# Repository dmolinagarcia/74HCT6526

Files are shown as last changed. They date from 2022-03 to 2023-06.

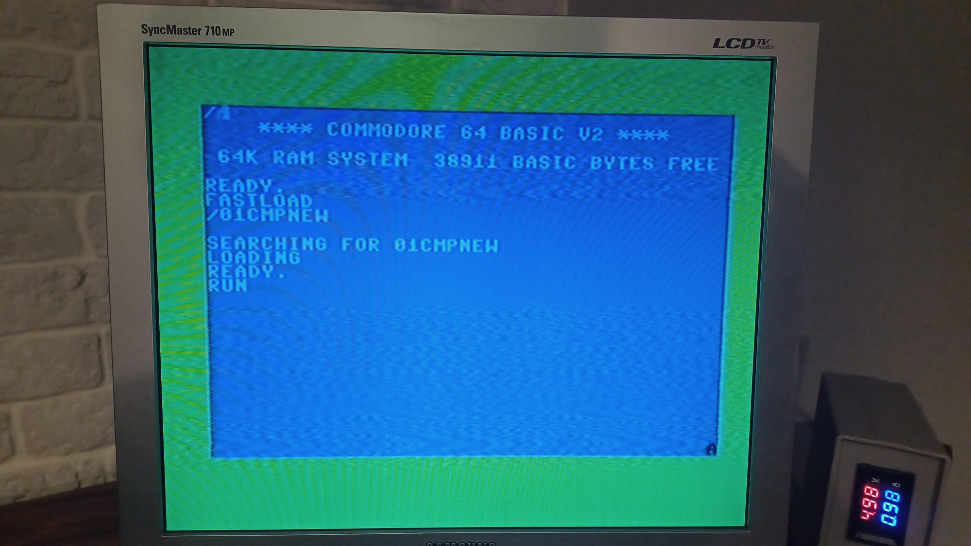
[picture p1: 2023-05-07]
img/20230506_TEST01_NEWHCT.jpeg

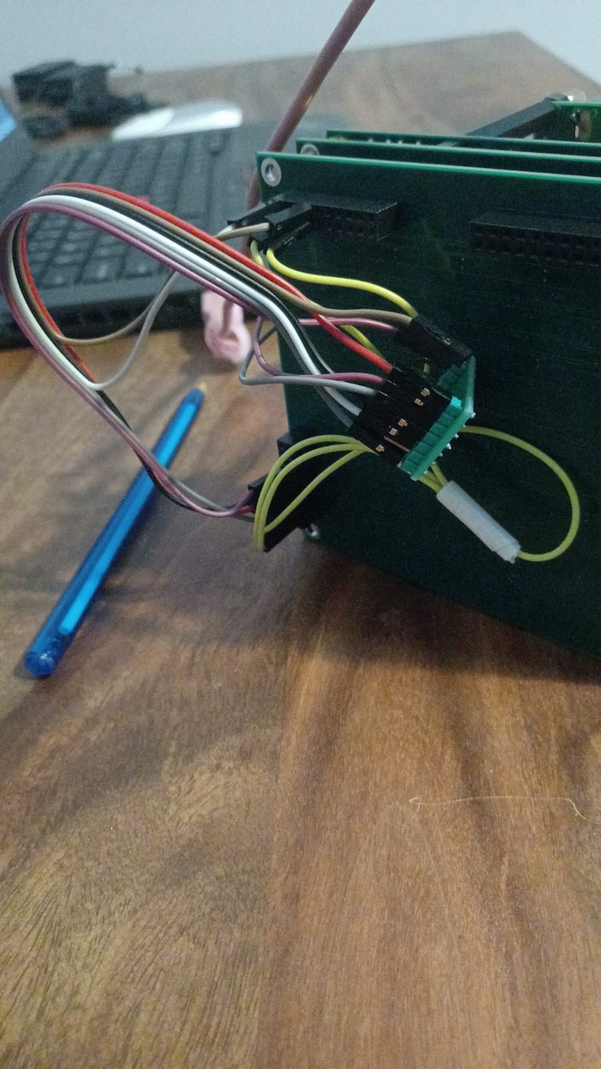
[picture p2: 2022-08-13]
img/20220810_TA_fix.jpg

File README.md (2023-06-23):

>
> DISCLAIMER
> Everything you see here is the result of the work of an amateur hobbyist. I had no knowledge in any required field for this project when I started, so I offer no guarantee that, if you replicate my work, you may end burning up you Commodore, your fingertips, or your whole house.
> So far, no Commodore equipment (or fingertips, or whole house) have been permanently damaged in any way. But I can't promise to keep it that way.
>

# 74HCT6526 
The 74HCT6526 is a very amateur attempt at building a MOS6526 replica using discrete logic. This repo is publicly shared just for educational purposes, and I can offer no guarantee on the correct behaviour of this implementation. So far, it's working great for me, but I can't promise anything.

# Current Status
As of v0.2.2, the 74HCT6526 is extremely cycle accurate when compared to a real 6526. Some VICE test still fail on edge cases, but it has been tested against multiple games with very satisfactory results. 

# History
Work on the 74HCT6526 began in the summer of 2018. I was so impressed by other attempts at replicating Commodore chips, that I wanted to give it myself a try. I chose the CIA, as it wasn't replicated back then, even though it seemed the simplest chip. I had no previous knowledge in electronics, only some lessons back in college more than 20 years ago.

> ###### Important note
> Please visit http://forum.6502.org/viewtopic.php?f=4&t=5593 for more information

# Versioning
74HCT6526 is released under the following versioning scheme:

> MAJOR.MINOR.REVISION

For a stack to work properly, is mandatory that all boards share the same MAJOR.MINOR versión. Any change than renders a board incompatible with the previous releases triggers a new MINOR version. If a version only includes fixes, but does not alter the buses, it's only a new revision. There may be some cases where boards with different MAJOR.MINOR version can actually work together, but this is not something I can guarantee or predict. A deep look at the schematics to understand the differences between releases is needed to actually confirm this.

Under the current scheme, I don't think I'll ever need a new MAJOR version, but it is nice to have it there, just in case.

# Upgrades
In the upgrades folder, there's a guide for each version/board pair, with instructions to upgrade the board up until the latest version. You'll see theres no file for the latest version (As there's no upgrade path for it).

Whenever a new release is published, upgrade path for the now second-oldest release will by published.

> WARNING! I offer no guarantee on anything on this project, but, specially on the upgrades part. 

# Manufacturing
All boards are tested against JLCPCB and PCBWAY capabilities. For PCBWAY, there is no increase in cost compared to the standard 4 layer board.

# Releases
* v0.1.0  First production run. Only includes B0 (DDR and PORTs)
* v0.1.0a First production run for B1. (TIMERA and CREGA)
* v0.1.1  Second production run for B1. Fixes TASTART issue. First B2 (TIMERB and CREGB) 
* v0.1.2  First production run for B3. (SDR and ICR)
* v0.2.0  First MINOR advance. B0+B1+B2+B3 tested and validated. 
* v0.2.1  Fixes for Reload under Underflow issue. 
* v0.2.2  First production run for B4 (TOD). It now passes test 01 and 02 in both NEW and OLD modes.

# Changelog
## [0.2.2 ] - 23-Jun-2023
* B0. Some HCT parts are changed to HC
* B1. Split TIMER into modules for improved readability
* B2. Split TIMER into modules for improved readability
* B3. Issue #12. Fixed all issues for test 02
* B3. Master Switch for Mode Change. (Old vs NEW)
* B3. Some HC parts are changed to HCT
* B4. Added TOD PCB and SCH
* All boards. Published upgrade procedures

## [0.2.1 ] - 26-Mar-2023
* All boards. Added pdfs for all schematic and pcbs for all versions for ease of access
* B1. Changes to Reload portion of TimerA pipeline to fix 01cmpold issue
* B2. Changes to Reload portion of TimerA pipeline to fix 01cmpold issue
* B3. Added switch to select OLD or NEW CIA

## [0.2.0 ] - 24-Jan-2023
* All boards. Removed TARUNMODE from the ControlBus
* All boards. Updated for JLCPCB and PCBWAY capabilities
* All boards. Minor aesthetic changes to schematics
* All boards. Updated PDFs on the release
* B1. Optimized CNT edge detector
* B2. Optimized CNT edge detector
* B3. Fixed FLAG edge detector in ICR
* B3. Fixed SDR input and output issues from v0.1.2 (not sending nor receiving)

## [0.1.2 ] - 01-Nov-2022 
* B3. First release. SDR and ICR
* B2. Updates for JLCPCB capabilities
* All boards. Schematic review. Added /RES capacitor to prevent false restarts

## [0.1.1 ] - 24-Aug-2022 
* B2. First release. 
* B1. Fixed additional cycle on forceload by removing second flipflop in the chain (rolled-back)
* B1. Added additionad dFF to Start before being fed into the timer
* B1. D and DZ moved to separate buses on schematic.
* B0. Routing optimized. D and DZ moved to separate buses on schematic. Silkscreen improved. 

## [0.1.0a] - 06-Jun-2022
* B1 with TimerA and Control Register A. Ready for production. 

## [0.1.0 ] - 19-Oct-2021
* Mounting holes pads were covered with soldermask. Soldermask removed and pads properly labeled.
* Silkscreen fixes
* Updated gerber files
* B0 with DDRs, PORTs, and bus interface

# Status updates
* June 23, 2023. v0.2.2 released. Adds TOD (B4) and fixes more NEW to OLD issues. Now passes tests 01 and 02.
* March 26, 2023. v0.2.1 released. Fixes a missing IRQ issue on reload while underflowing. It also adds a selector for OLD vs NEW cia in ICR
* January 24, 2023. v0.2.0 released. Fixes a potential problem on B1 and B2 with CNT edge detector. It also fixes some bugs on B3. A cleanup of schematic, PCBs and PDFs for all boards has been done. TARUNMODE is removed from controlbus as it is not needed. This triggers a new MINOR version
* November 01, 2022. v0.1.2 released. Includes B3 (SDR+ICR) and some minor tweaks to all boards
* August 24, 2022. v0.1.1 released. Fixes a bug in B1 (TASTART) and adds B2. Minor routing fixes to all boards
* June 06, 2022. v0.1.0a released. It adds B1 to v0.1.0
* October 19, 2021. v0.1.0 is released. It add B0 to v0.1.0
* September 12th, 2021. Repository is now public. B0 schematic is 100% done. PCB layout is 100% done. It's currently being reviewed before sending it into production

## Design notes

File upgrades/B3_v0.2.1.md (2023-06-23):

# B3 v0.2.1 Upgrade Path

@ v0.2.1
- [ ] We need one extra FF (NEWFF). 7 to GND 14 to VCC
- [ ] We also need one 74HC157 and a 2 way switch. 8 to GND 16 to VCC
- [ ] HC157.1 to center pin on switch.
- [ ] On switch. GND is NEW. VCC will be old
- [ ] HC157.15 to GND (/ENABLE)
- [ ] Replace /ICRCLR2 by /ICRCLR1 for all sources. Lift U330.6. Connect U331.1 to U330.8
- [ ] ICR1 clear OLD vs NEW. Lift U332.13. Connect to HC157.4
- [ ] ICR1 clear OLD vs NEW. HC157.2 connect to U331.13
- [ ] ICR1 clear OLD vs NEW. HC157.3 connect to U330.6
- [ ] ICR1 SET ICR7. Lift U337.12 connect to U335.13
- [ ] ICR7 OLD vs NEW. Lift U334.13 connect to U334.1
- [ ] ICR7 OLD vs NEW. Lift U336.8 connect to HC157.7
- [ ] ICR7 OLD vs NEW. HC157.5 to U334.5
- [ ] ICR7 OLD vs NEW. HC157.6 to U334.9
- [ ] IRQ OLD vs NEW. NEWFF.1 to U333.13
- [ ] IRQ OLD vs NEW. NEWFF.2 NEWFF.3 NEWFF.10 to VCC
- [ ] IRQ OLD vs NEW. NEWFF.4 to U335.8
- [ ] IRQ OLD vs NEW. NEWFF.5 to NEWFF.12
- [ ] IRQ OLD vs NEW. NEWFF.6 to HC157.11
- [ ] IRQ OLD vs NEW. NEWFF.8 to HC157.10
- [ ] IRQ OLD vs NEW. NEWFF.11 to U330.3
- [ ] IRQ OLD vs NEW. HC157.9 to /IRQ in controlBUS

@ v0.2.2

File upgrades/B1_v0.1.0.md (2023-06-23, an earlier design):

# B1 v0.1.0 Upgrade Path

@ v0.1.0
- [ ] FIX TASTART is too early. We need a new FF. Prepare a new 74HC74
- [ ] Cut trace just outside U125 PIN5. Data PIN will be early, but this is good enough
- [ ] NEWFF.1 >> VCC                RESET (VCC)
- [ ] Connect U125.5 to NEWFF.2     DATA  (old TASTART)
- [ ] NEWFF.3 >> U128.11            CLOCK (/PHI2)
- [ ] NEWFF.4 >> VCC                SET   (VCC)
- [ ] NEWFF.5 >> U127.9             Q     (new TASTART)
- [ ] NEWFF.6 >> unconected         /Q
- [ ] NEWFF.7 >> GND                GND
- [ ] NEWFF.14>> VCC                VCC

@ v0.1.1
- [ ] Added reset capacitor (100n) Optional.

@ v0.1.2
- [ ] TARUNMODE Removed from CONTROLBUS. Optional. (For now)
- [ ] CNTSYNC Improvement. Lift U123.1 Connect to 8. Optional

@ v0.2.0
- [x] FORCELOAD FIX. We use second FF from Extra FF. 
- [ ] Cut between U119.9 and U127.4
- [ ] NEWFF.13 >> U119.13 (RESET)
- [ ] NEWFF.12 >> U119.9  (DATA)
- [ ] NEWFF.11 >> NEWFF.3 (/PHI2) 
- [ ] NEWFF.10 >> VCC     (SET)
- [ ] NEWFF.9  >>  U127.4 (NEW DELAYED FORCELOAD)
- [ ] Lift U118.13 >> Connect to U115.4

@ v0.2.1
- [ ] Nothing to do

@ v0.2.2

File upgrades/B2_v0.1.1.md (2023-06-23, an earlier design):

# B2 v0.1.1 Upgrade Path

@ v0.1.1
- [ ] Added reset capacitor (100n) Optional.

@ v0.1.2
- [ ] TARUNMODE Removed from CONTROLBUS. Optional. (For now)
- [ ] CNTSYNC Improvement. Lift U221.1 Connect to U221.8. Optional

@ v0.2.0
- [ ] FORCELOAD FIX. We need an extra FF (NEWFF)
- [ ] Cut between U217.9 and U229.4
- [ ] NEWFF.13 >> U217.13 (RESET)
- [ ] NEWFF.12 >> U217.9  (DATA)
- [ ] NEWFF.11 >> U217.11 (/PHI2) 
- [ ] NEWFF.10 >> VCC     (SET)
- [ ] NEWFF.9  >>  U229.4 (NEW DELAYED FORCELOAD)
- [ ] Lift U216.13 >> Connect to U213.4

@ v0.2.1
- [ ] Nothing to do

@ v0.2.2

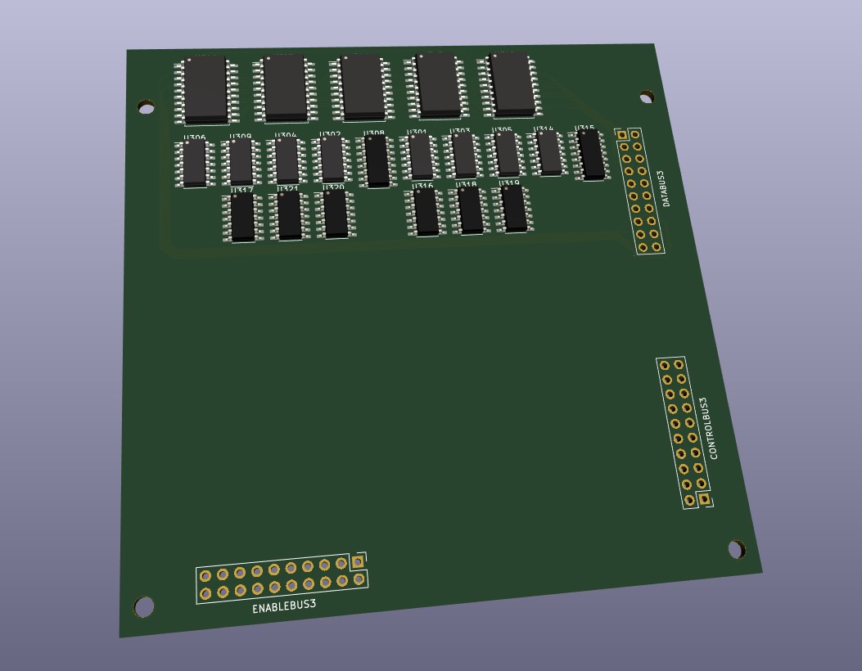
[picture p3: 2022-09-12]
img/B3_prov.jpg

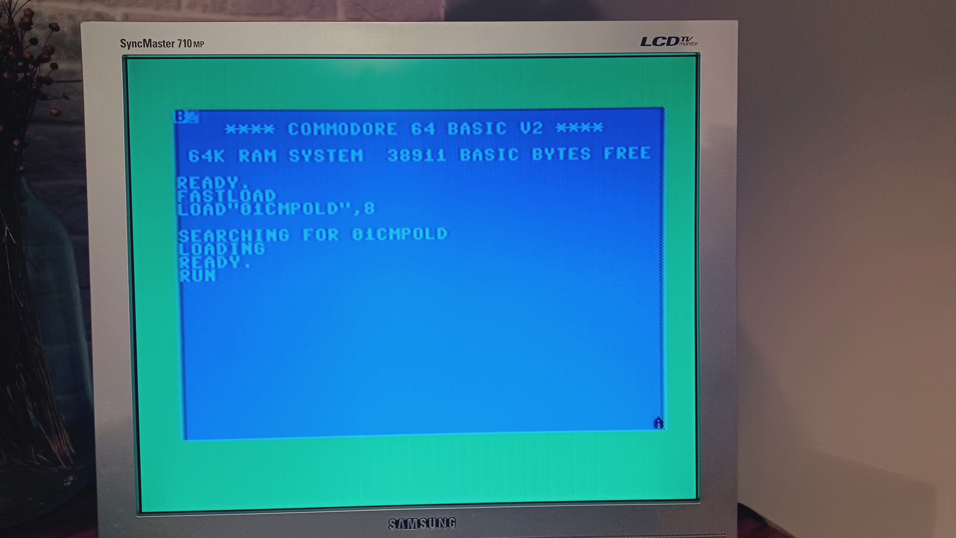
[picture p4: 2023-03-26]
img/20230321_01cmpold_success.jpg

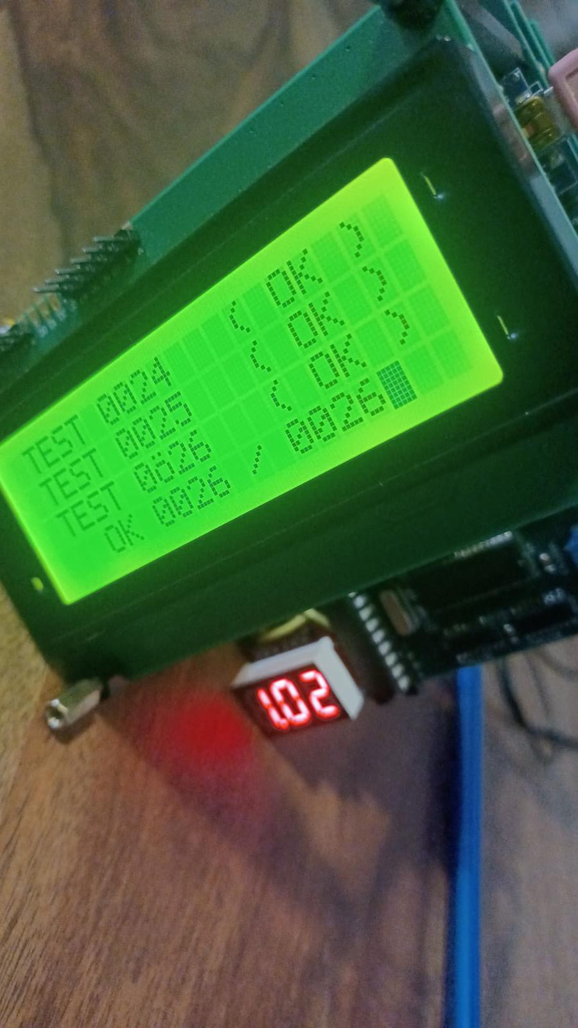
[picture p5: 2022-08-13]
img/20220810_TA_fixed.jpg

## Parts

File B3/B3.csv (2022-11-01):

Source: | Z:\gitHub\74HCT6526\B3\B3.kicad_sch
Date: | 18/10/2022 22:42:34
Tool: | Eeschema (6.0.5)
Generator: | C:\Program Files\KiCad\6.0\bin\scripting\plugins/bom_csv_grouped_by_value.py
Component Count: | 82
Individual Components:
Item | Qty | Reference(s) | Value | LibPart | Footprint | Datasheet
 |  | C301 | 100n | Device:C | Capacitor_SMD:C_0603_1608Metric | ~
 |  | C302 | 100n | Device:C | Capacitor_SMD:C_0603_1608Metric | ~
 |  | C303 | 100n | Device:C | Capacitor_SMD:C_0603_1608Metric | ~
 |  | C304 | 100n | Device:C | Capacitor_SMD:C_0603_1608Metric | ~
 |  | C305 | 100n | Device:C | Capacitor_SMD:C_0603_1608Metric | ~
 |  | C306 | 100n | Device:C | Capacitor_SMD:C_0603_1608Metric | ~
 |  | C307 | 100n | Device:C | Capacitor_SMD:C_0603_1608Metric | ~
 |  | C308 | 100n | Device:C | Capacitor_SMD:C_0603_1608Metric | ~
 |  | C309 | 100n | Device:C | Capacitor_SMD:C_0603_1608Metric | ~
 |  | C310 | 100n | Device:C | Capacitor_SMD:C_0603_1608Metric | ~
 |  | C311 | 100n | Device:C | Capacitor_SMD:C_0603_1608Metric | ~
 |  | C312 | 100n | Device:C | Capacitor_SMD:C_0603_1608Metric | ~
 |  | C313 | 100n | Device:C | Capacitor_SMD:C_0603_1608Metric | ~
 |  | C314 | 100n | Device:C | Capacitor_SMD:C_0603_1608Metric | ~
 |  | C315 | 100n | Device:C | Capacitor_SMD:C_0603_1608Metric | ~
 |  | C316 | 100n | Device:C | Capacitor_SMD:C_0603_1608Metric | ~
 |  | C317 | 100n | Device:C | Capacitor_SMD:C_0603_1608Metric | ~
 |  | C318 | 100n | Device:C | Capacitor_SMD:C_0603_1608Metric | ~
 |  | C319 | 100n | Device:C | Capacitor_SMD:C_0603_1608Metric | ~
 |  | C320 | 100n | Device:C | Capacitor_SMD:C_0603_1608Metric | ~
 |  | C321 | 100n | Device:C | Capacitor_SMD:C_0603_1608Metric | ~
 |  | C322 | 100n | Device:C | Capacitor_SMD:C_0603_1608Metric | ~
 |  | C323 | 100n | Device:C | Capacitor_SMD:C_0603_1608Metric | ~
 |  | C324 | 100n | Device:C | Capacitor_SMD:C_0603_1608Metric | ~
 |  | C325 | 100n | Device:C | Capacitor_SMD:C_0603_1608Metric | ~
 |  | C326 | 100n | Device:C | Capacitor_SMD:C_0603_1608Metric | ~
 |  | C327 | 100n | Device:C | Capacitor_SMD:C_0603_1608Metric | ~
 |  | C328 | 100n | Device:C | Capacitor_SMD:C_0603_1608Metric | ~
 |  | C329 | 100n | Device:C | Capacitor_SMD:C_0603_1608Metric | ~
 |  | C330 | 100n | Device:C | Capacitor_SMD:C_0603_1608Metric | ~
 |  | C331 | 100n | Device:C | Capacitor_SMD:C_0603_1608Metric | ~
 |  | C332 | 100n | Device:C | Capacitor_SMD:C_0603_1608Metric | ~
 |  | C333 | 100n | Device:C | Capacitor_SMD:C_0603_1608Metric | ~
 |  | C334 | 100n | Device:C | Capacitor_SMD:C_0603_1608Metric | ~
 |  | C335 | 100n | Device:C | Capacitor_SMD:C_0603_1608Metric | ~
 |  | C336 | 100n | Device:C | Capacitor_SMD:C_0603_1608Metric | ~
 |  | C337 | 100n | Device:C | Capacitor_SMD:C_0603_1608Metric | ~
 |  | C338 | 100n | Device:C | Capacitor_SMD:C_0603_1608Metric | ~
 |  | C339 | 100n | Device:C | Capacitor_SMD:C_0603_1608Metric | ~
 |  | C340 | 100n | Device:C | Capacitor_SMD:C_0603_1608Metric | ~
 |  | CONTROLBUS3 | Conn_02x10_Odd_Even | Connector_Generic:Conn_02x10_Odd_Even | Connector_PinHeader_2.54mm:PinHeader_2x10_P2.54mm_Vertical | ~
 |  | DATABUS3 | Conn_02x10_Odd_Even | Connector_Generic:Conn_02x10_Odd_Even | Connector_PinHeader_2.54mm:PinHeader_2x10_P2.54mm_Vertical | ~
 |  | ENABLEBUS3 | Conn_02x10_Odd_Even | Connector_Generic:Conn_02x10_Odd_Even | Connector_PinHeader_2.54mm:PinHeader_2x10_P2.54mm_Vertical | ~
 |  | U301 | 74HC00 | 74xx:74HC00 | Package_SO:SO-14_3.9x8.65mm_P1.27mm | http://www.ti.com/lit/gpn/sn74hc00
 |  | U302 | 74HC125 | 74xx:74LS125 | Package_SO:SO-14_3.9x8.65mm_P1.27mm | http://www.ti.com/lit/gpn/sn74LS125
 |  | U303 | 74HC74 | 74xx:74HC74 | Package_SO:SO-14_3.9x8.65mm_P1.27mm | 74xx/74hc_hct74.pdf
 |  | U304 | 74HC74 | 74xx:74HC74 | Package_SO:SO-14_3.9x8.65mm_P1.27mm | 74xx/74hc_hct74.pdf
 |  | U305 | 74HC74 | 74xx:74HC74 | Package_SO:SO-14_3.9x8.65mm_P1.27mm | 74xx/74hc_hct74.pdf
 |  | U306 | 74HC32 | 74xx:74LS32 | Package_SO:SO-14_3.9x8.65mm_P1.27mm | http://www.ti.com/lit/gpn/sn74LS32
 |  | U307 | 74HC299 | 74xx:74LS299 | Package_SO:SOIC-20W_7.5x12.8mm_P1.27mm | http://www.ti.com/lit/gpn/sn74LS299
 |  | U308 | 74HC193 | 74xx:74LS193 | Package_SO:SO-16_3.9x9.9mm_P1.27mm | http://www.ti.com/lit/ds/symlink/sn74ls193.pdf
 |  | U309 | 74HC00 | 74xx:74HC00 | Package_SO:SO-14_3.9x8.65mm_P1.27mm | http://www.ti.com/lit/gpn/sn74hc00
 |  | U310 | 74HC244 | 74xx:74HC244 | Package_SO:SOIC-20W_7.5x12.8mm_P1.27mm | https://assets.nexperia.com/documents/data-sheet/74HC_HCT244.pdf
 |  | U311 | 74HC377 | 74xx:74LS377 | Package_SO:SOIC-20W_7.5x12.8mm_P1.27mm | http://www.ti.com/lit/gpn/sn74LS377
 |  | U312 | 74HC244 | 74xx:74HC244 | Package_SO:SOIC-20W_7.5x12.8mm_P1.27mm | https://assets.nexperia.com/documents/data-sheet/74HC_HCT244.pdf
 |  | U313 | 74HC299 | 74xx:74LS299 | Package_SO:SOIC-20W_7.5x12.8mm_P1.27mm | http://www.ti.com/lit/gpn/sn74LS299
 |  | U314 | 74HC32 | 74xx:74LS32 | Package_SO:SO-14_3.9x8.65mm_P1.27mm | http://www.ti.com/lit/gpn/sn74LS32
 |  | U315 | 74HC193 | 74xx:74LS193 | Package_SO:SO-16_3.9x9.9mm_P1.27mm | http://www.ti.com/lit/ds/symlink/sn74ls193.pdf
 |  | U316 | 74HC00 | 74xx:74HC00 | Package_SO:SO-14_3.9x8.65mm_P1.27mm | http://www.ti.com/lit/gpn/sn74hc00
 |  | U317 | 74HC74 | 74xx:74HC74 | Package_SO:SO-14_3.9x8.65mm_P1.27mm | 74xx/74hc_hct74.pdf
 |  | U318 | 74HC08 | Custom 74xx:74HC08 | Package_SO:SO-14_3.9x8.65mm_P1.27mm
 |  | U319 | 74HC32 | 74xx:74LS32 | Package_SO:SO-14_3.9x8.65mm_P1.27mm | http://www.ti.com/lit/gpn/sn74LS32
 |  | U320 | 74HC00 | 74xx:74HC00 | Package_SO:SO-14_3.9x8.65mm_P1.27mm | http://www.ti.com/lit/gpn/sn74hc00
 |  | U321 | 74HC00 | 74xx:74HC00 | Package_SO:SO-14_3.9x8.65mm_P1.27mm | http://www.ti.com/lit/gpn/sn74hc00
 |  | U322 | 74HC00 | 74xx:74HC00 | Package_SO:SO-14_3.9x8.65mm_P1.27mm | http://www.ti.com/lit/gpn/sn74hc00
 |  | U323 | 74HC00 | 74xx:74HC00 | Package_SO:SO-14_3.9x8.65mm_P1.27mm | http://www.ti.com/lit/gpn/sn74hc00
 |  | U324 | 74HC00 | 74xx:74HC00 | Package_SO:SO-14_3.9x8.65mm_P1.27mm | http://www.ti.com/lit/gpn/sn74hc00
 |  | U325 | 74HC08 | Custom 74xx:74HC08 | Package_SO:SO-14_3.9x8.65mm_P1.27mm
 |  | U326 | 74HC08 | Custom 74xx:74HC08 | Package_SO:SO-14_3.9x8.65mm_P1.27mm
 |  | U327 | 74HC377 | 74xx:74LS377 | Package_SO:SOIC-20W_7.5x12.8mm_P1.27mm | http://www.ti.com/lit/gpn/sn74LS377
 |  | U328 | 74HC00 | 74xx:74HC00 | Package_SO:SO-14_3.9x8.65mm_P1.27mm | http://www.ti.com/lit/gpn/sn74hc00
 |  | U329 | 74HC00 | 74xx:74HC00 | Package_SO:SO-14_3.9x8.65mm_P1.27mm | http://www.ti.com/lit/gpn/sn74hc00
 |  | U330 | 74HC74 | 74xx:74HC74 | Package_SO:SO-14_3.9x8.65mm_P1.27mm | 74xx/74hc_hct74.pdf
 |  | U331 | 74HC74 | 74xx:74HC74 | Package_SO:SO-14_3.9x8.65mm_P1.27mm | 74xx/74hc_hct74.pdf
 |  | U332 | 74HC74 | 74xx:74HC74 | Package_SO:SO-14_3.9x8.65mm_P1.27mm | 74xx/74hc_hct74.pdf
 |  | U333 | 74HC74 | 74xx:74HC74 | Package_SO:SO-14_3.9x8.65mm_P1.27mm | 74xx/74hc_hct74.pdf
 |  | U334 | 74HC74 | 74xx:74HC74 | Package_SO:SO-14_3.9x8.65mm_P1.27mm | 74xx/74hc_hct74.pdf
 |  | U335 | 74HC04 | 74xx:74HC04 | Package_SO:SO-14_3.9x8.65mm_P1.27mm | https://assets.nexperia.com/documents/data-sheet/74HC_HCT04.pdf
 |  | U336 | 74HC244 | 74xx:74HC244 | Package_SO:SOIC-20W_7.5x12.8mm_P1.27mm | https://assets.nexperia.com/documents/data-sheet/74HC_HCT244.pdf
 |  | U337 | 74HC08 | Custom 74xx:74HC08 | Package_SO:SO-14_3.9x8.65mm_P1.27mm
 |  | U338 | 74HC32 | 74xx:74LS32 | Package_SO:SO-14_3.9x8.65mm_P1.27mm | http://www.ti.com/lit/gpn/sn74LS32
 |  | U339 | 74HC08 | Custom 74xx:74HC08 | Package_SO:SO-14_3.9x8.65mm_P1.27mm
Collated Components:
Item | Qty | Reference(s) | Value | LibPart | Footprint | Datasheet
1 | 40 | C301, C302, C303, C304, C305, C306, C307, C308, C309, C310, C311, C312, C313, C314, C315, C316, C317, C318, C319, C320, C321, C322, C323, C324, C325, C326, C327, C328, C329, C330, C331, C332, C333, C334, C335, C336, C337, C338, C339, C340 | 100n | Device:C | Capacitor_SMD:C_0603_1608Metric | ~
2 | 3 | CONTROLBUS3, DATABUS3, ENABLEBUS3 | Conn_02x10_Odd_Even | Connector_Generic:Conn_02x10_Odd_Even | Connector_PinHeader_2.54mm:PinHeader_2x10_P2.54mm_Vertical | ~
3 | 10 | U301, U309, U316, U320, U321, U322, U323, U324, U328, U329 | 74HC00 | 74xx:74HC00 | Package_SO:SO-14_3.9x8.65mm_P1.27mm | http://www.ti.com/lit/gpn/sn74hc00
4 | 1 | U302 | 74HC125 | 74xx:74LS125 | Package_SO:SO-14_3.9x8.65mm_P1.27mm | http://www.ti.com/lit/gpn/sn74LS125
5 | 9 | U303, U304, U305, U317, U330, U331, U332, U333, U334 | 74HC74 | 74xx:74HC74 | Package_SO:SO-14_3.9x8.65mm_P1.27mm | 74xx/74hc_hct74.pdf
6 | 4 | U306, U314, U319, U338 | 74HC32 | 74xx:74LS32 | Package_SO:SO-14_3.9x8.65mm_P1.27mm | http://www.ti.com/lit/gpn/sn74LS32
7 | 2 | U307, U313 | 74HC299 | 74xx:74LS299 | Package_SO:SOIC-20W_7.5x12.8mm_P1.27mm | http://www.ti.com/lit/gpn/sn74LS299
8 | 2 | U308, U315 | 74HC193 | 74xx:74LS193 | Package_SO:SO-16_3.9x9.9mm_P1.27mm | http://www.ti.com/lit/ds/symlink/sn74ls193.pdf
9 | 3 | U310, U312, U336 | 74HC244 | 74xx:74HC244 | Package_SO:SOIC-20W_7.5x12.8mm_P1.27mm | https://assets.nexperia.com/documents/data-sheet/74HC_HCT244.pdf
10 | 2 | U311, U327 | 74HC377 | 74xx:74LS377 | Package_SO:SOIC-20W_7.5x12.8mm_P1.27mm | http://www.ti.com/lit/gpn/sn74LS377
11 | 5 | U318, U325, U326, U337, U339 | 74HC08 | Custom 74xx:74HC08 | Package_SO:SO-14_3.9x8.65mm_P1.27mm
12 | 1 | U335 | 74HC04 | 74xx:74HC04 | Package_SO:SO-14_3.9x8.65mm_P1.27mm | https://assets.nexperia.com/documents/data-sheet/74HC_HCT04.pdf

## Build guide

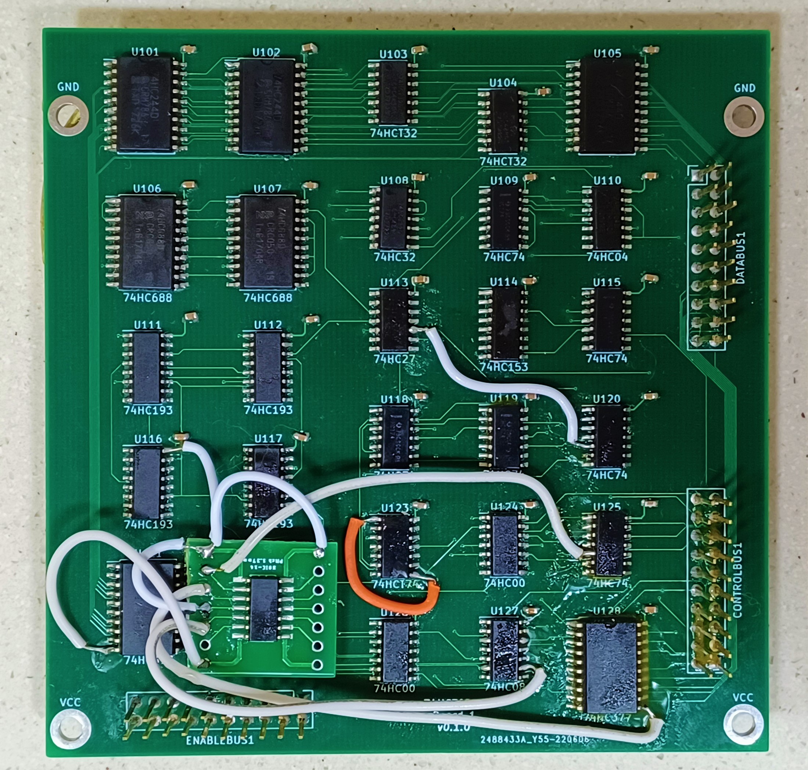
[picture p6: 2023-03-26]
img/Photos-001/20230319_step1.jpg

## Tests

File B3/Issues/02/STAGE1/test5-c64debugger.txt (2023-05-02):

abrimos el retrodebugger
load 02olcdias.prg
reset

poke 2077,5		; Start en test 5
sys 2061

breakpoint 096b		right after delay

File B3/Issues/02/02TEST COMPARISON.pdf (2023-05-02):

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
@ iA iA iA iA

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
iA iA iA iA

@

@

@

@

@ iA iA iA iA
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
@ iA iA iA iA iA

@

@

@

@

@

@

@
iA iA iA iA

@

@

@

@

@ iA iA iA iA
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
@ iA iA iA iA iA

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
iA iA iA

@

@

@

@

@

@ iA iA iA
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
@ iA iA iA iA iA

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
iA iA iA

@

@

@

@

@ iA iA iA
K

K

K

G

G

G

G

B | B B B

HCTOLD

MOSOLD

TEST6

HCTNEW

MOSNEW

TEST6

TEST5

HCTNEW

MOSNEW

TEST5

HCTOLD

MOSOLD

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
@ iB iB iB iB

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
@ iB iB iB

@

@

@

@

@

@ iB iB iB
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
@ iB iB iB iB iB

@

@

@

@

@

@

@
iB iB iB iB

@

@

@

@

@ iB iB iB iB
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
@ iB iB iB iB iB

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
@ iB iB

@

@

@

@

@

@

@ iB iB
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
@ iB iB iB iB iB

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
i@ iB iB

@

@

@

@

@ i@ iB iB
K

K

K

G

G

G

G

B | B B B

TEST8

HCTNEW

MOSNEW

TEST8

HCTOLD

MOSOLD

TEST7

HCTNEW

MOSNEW

TEST7

HCTOLD

MOSOLD

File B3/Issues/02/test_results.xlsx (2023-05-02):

 | OLD MODE |  |  |  | NEW MODE
AFTER CHANGE | 01old | 01new | 02old | 02new | 01old | 01new | 02old | 02new
1 | OK - ESPERADO | KO - ESPERADO | TA OK - TB OK - IA OK - IB KO | TA OK - TB KO - IA KO - IB KO | KO - ESPERADO | OK - ESPERADO | TA OK TB OK IA KO IB KO | TA OK TB KO IA KO IB KO

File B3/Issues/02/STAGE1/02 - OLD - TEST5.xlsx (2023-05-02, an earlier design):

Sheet: Hoja1
microSecs | MOS OLD |  |  |  |  |  |  | microSecs | HCT OLD |  |  |  |  |  |  |  |  |  | A | B | C | D | E | F | G | H
 | PHI2 | PB6 | /CS | /IRQ | D7 | D1 | D0 |  | PHI2 | PB6 | /CS | /IRQ | D7 | D1 | D0 |  |  |  | @ | @ | @ | @ | @ | @ | @ | @
 |  |  |  |  |  |  |  |  |  |  |  |  |  |  |  |  |  |  |  | @ | @ | @ | @ | @ | @ | @
 |  |  |  |  |  |  |  |  |  |  |  |  |  |  |  |  |  |  |  | A | A | A
 |  |  |  |  |  |  |  |  |  |  |  |  |  |  |  | OPCODE |  | SCREEN OUTPUT
48.250 | 0 | 1 | 1 | 1 | 1 | 0 | 1 | 48.375 | 0 | 1 | 1 | 1 | 1 | 0 | 1
48.375 | 0 | 1 | 1 | 1 | 0 | 0 | 0 | 48.500 | 0 | 1 | 1 | 1 | 0 | 0 | 0
48.500 | 0 | 1 | 1 | 1 | 0 | 0 | 0 | 48.625 | 0 | 1 | 1 | 1 | 0 | 0 | 0
48.625 | 1 | 1 | 0 | 1 | 0 | 0 | 0 | 48.750 | 1 | 1 | 0 | 1 | 0 | 1 | 1
48.750 | 1 | 1 | 0 | 1 | 0 | 1 | 1 | 48.875 | 1 | 1 | 0 | 1 | 0 | 1 | 1
48.875 | 1 | 1 | 0 | 1 | 0 | 1 | 1 | 49.000 | 1 | 1 | 0 | 1 | 0 | 1 | 1
49.000 | 1 | 1 | 0 | 1 | 0 | 1 | 1 | 49.125 | 1 | 1 | 0 | 1 | 0 | 1 | 1 |  |  |  |  |  |  |  |  |  |  |  | STA CRG | SET PB ON
49.125 | 0 | 1 | 1 | 1 | 0 | 1 | 1 | 49.250 | 0 | 0 | 1 | 1 | 0 | 1 | 1 |  |  |  |  |  |  |  |  |  |  |  | START OF TEST
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

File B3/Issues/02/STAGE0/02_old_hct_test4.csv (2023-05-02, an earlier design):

Time[s] | PHI2 | PB6 | PB7 | /CS | /IRQ | D0 | D1 | D7
0.019945375000000 | 1 | 1 | 1 | 1 | 1 | 0 | 0 | 0
0.019945500000000 | 1 | 1 | 1 | 0 | 1 | 0 | 0 | 0
0.019945625000000 | 1 | 1 | 1 | 0 | 1 | 0 | 0 | 0
0.019945750000000 | 1 | 1 | 1 | 0 | 1 | 0 | 0 | 0
0.019945875000000 | 0 | 1 | 1 | 1 | 1 | 0 | 0 | 0
0.019946000000000 | 0 | 1 | 1 | 1 | 1 | 0 | 0 | 0
0.019946125000000 | 0 | 1 | 1 | 1 | 1 | 0 | 0 | 0
0.019946250000000 | 0 | 1 | 1 | 1 | 1 | 0 | 0 | 0
0.019946375000000 | 1 | 1 | 1 | 1 | 1 | 0 | 0 | 0
0.019946500000000 | 1 | 1 | 1 | 1 | 1 | 0 | 0 | 0
0.019946625000000 | 1 | 1 | 1 | 1 | 1 | 0 | 0 | 1
0.019946750000000 | 1 | 1 | 1 | 1 | 1 | 1 | 0 | 1
0.019946875000000 | 0 | 1 | 1 | 1 | 1 | 1 | 0 | 1
0.019947000000000 | 0 | 1 | 1 | 1 | 1 | 1 | 0 | 1
0.019947125000000 | 0 | 1 | 1 | 1 | 1 | 1 | 0 | 1
0.019947250000000 | 0 | 1 | 1 | 1 | 1 | 0 | 0 | 0
0.019947375000000 | 1 | 1 | 1 | 1 | 1 | 0 | 0 | 0
0.019947500000000 | 1 | 1 | 1 | 1 | 1 | 0 | 0 | 0
0.019947625000000 | 1 | 1 | 1 | 1 | 1 | 0 | 0 | 0
0.019947750000000 | 1 | 1 | 1 | 1 | 1 | 0 | 0 | 0
0.019947875000000 | 0 | 1 | 1 | 1 | 1 | 0 | 0 | 0
0.019948000000000 | 0 | 1 | 1 | 1 | 1 | 0 | 0 | 0
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

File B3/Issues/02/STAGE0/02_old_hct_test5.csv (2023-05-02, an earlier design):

Time[s] | PHI2 | PB6 | PB7 | /CS | /IRQ | D0 | D1 | D7
0.059857750000000 | 1 | 1 | 1 | 0 | 1 | 0 | 0 | 0
0.059857875000000 | 1 | 1 | 1 | 0 | 1 | 0 | 0 | 0
0.059858000000000 | 1 | 1 | 1 | 0 | 1 | 0 | 0 | 0
0.059858125000000 | 0 | 1 | 1 | 0 | 1 | 0 | 0 | 0
0.059858250000000 | 0 | 1 | 1 | 1 | 1 | 0 | 0 | 0
0.059858375000000 | 0 | 1 | 1 | 1 | 1 | 0 | 0 | 0
0.059858500000000 | 0 | 1 | 1 | 1 | 1 | 0 | 0 | 1
0.059858625000000 | 0 | 1 | 1 | 1 | 1 | 0 | 0 | 1
0.059858750000000 | 1 | 1 | 1 | 1 | 1 | 0 | 0 | 1
0.059858875000000 | 1 | 1 | 1 | 1 | 1 | 0 | 0 | 1
0.059859000000000 | 1 | 1 | 1 | 1 | 1 | 1 | 0 | 1
0.059859125000000 | 1 | 1 | 1 | 1 | 1 | 1 | 0 | 1
0.059859250000000 | 0 | 1 | 1 | 1 | 1 | 1 | 0 | 1
0.059859375000000 | 0 | 1 | 1 | 1 | 1 | 1 | 0 | 1
0.059859500000000 | 0 | 1 | 1 | 1 | 1 | 0 | 0 | 0
0.059859625000000 | 0 | 1 | 1 | 1 | 1 | 0 | 0 | 0
0.059859750000000 | 1 | 1 | 1 | 1 | 1 | 0 | 0 | 0
0.059859875000000 | 1 | 1 | 1 | 1 | 1 | 0 | 0 | 0
0.059860000000000 | 1 | 1 | 1 | 1 | 1 | 0 | 0 | 0
0.059860125000000 | 1 | 1 | 1 | 1 | 1 | 0 | 0 | 0
0.059860250000000 | 0 | 1 | 1 | 1 | 1 | 0 | 0 | 0
0.059860375000000 | 0 | 1 | 1 | 1 | 1 | 0 | 0 | 0
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

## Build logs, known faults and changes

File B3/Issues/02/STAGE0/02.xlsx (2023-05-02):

REAL |  |  |  |  |  |  | HCT |  |  |  |  |  |  |  |  | TEST OUTPUT
Time[s] | PHI2 | PB6 | /CS | D7 | D1 | D0 | Time[s] | PHI2 | PB6 | /CS | D7 | D1 | D0 | OPCODE | Comentarios | 0 | 1 | 2 | 3 | 4 | 5 | 6 | 7 | 8 | 9 | a | b | c | d | e | f | ICR
 |  |  |  |  |  |  |  |  |  |  |  |  |  |  |  |  |  |  |  |  |  |  |  |  | B | C | D | E | F | G | H
 |  |  |  |  |  |  |  |  |  |  |  |  |  |  |  |  |  |  |  |  |  |  |  |  | A | A | A | A | A | A | @
 |  |  |  |  |  |  |  |  |  |  |  |  |  |  |  |  |  |  |  |  |  |  |  |  | @ | @ | @ | @ | @ | @ | @
0.019945375 | 1 | 1 | 1 | 1 | 0 | 0 | 0.019945375 | 1 | 1 | 1 | 0 | 0 | 0
0.019945500 | 1 | 1 | 0 | 1 | 0 | 0 | 0.019945500 | 1 | 1 | 0 | 0 | 0 | 0
0.019945625 | 1 | 1 | 0 | 0 | 0 | 0 | 0.019945625 | 1 | 1 | 0 | 0 | 0 | 0
0.019945750 | 1 | 1 | 0 | 0 | 0 | 0 | 0.019945750 | 1 | 1 | 0 | 0 | 0 | 0
0.019945875 | 0 | 1 | 0 | 0 | 0 | 0 | 0.019945875 | 0 | 1 | 1 | 0 | 0 | 0
0.019946000 | 0 | 1 | 1 | 0 | 0 | 0 | 0.019946000 | 0 | 1 | 1 | 0 | 0 | 0
0.019946125 | 0 | 1 | 1 | 0 | 0 | 0 | 0.019946125 | 0 | 1 | 1 | 0 | 0 | 0
0.019946250 | 0 | 1 | 1 | 0 | 0 | 0 | 0.019946250 | 0 | 1 | 1 | 0 | 0 | 0
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

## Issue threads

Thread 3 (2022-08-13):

ICR

dmolinagarcia, 2022-08-13:
// IRQ bit 7 of ICR is one cycle later set also one cycle later cleared than a timer irq is set.
// Reading ICR seems to reset the ICR the next cycle.
// Writing ICR seems to also clear the ICR, 2 cycles later, in my 6526R4. (without any read)

Seen in https://www.forum64.de/index.php?thread/109935-mos6526-cia-detailed-test-vectors-and-models/&pageNo=1

dmolinagarcia, 2023-06-23:
So far this is unproven. ICR seems ok now. Closing this.
We'll revisit if necesary.

Closed 2023-06-23.

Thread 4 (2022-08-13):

TIMER B BUG

dmolinagarcia, 2022-08-13:
Reading when timer b is going to fire an interrupt causes it not to fire.

dmolinagarcia, 2023-02-05:
```
Guess what?

I do have a Timer B bug.

And a timer A bug.

And everything else  :lol:

Everything else seems to be doing just fine, so I'm focusing on fixing this, before moving on to TOD.

The problem is something like this.

Whenever the ICR is read, on the next cycle, all interrupt bits are cleared to, by asserting the /reset line on their DFFs (74HC74). (/ICRCLR signal accomplish this)
The interrupt source feeds into the /set line of the DFFs.

I did some tests with just a couple of ICs, and whenever /set and /reset where asserted at the same time, /set prevailed, leaving the DFF set to 1. According to the datasheet, this is supposed to output a high value on both Q and /Q, and on the next clock pulse, the value on the D input is latched. Anyway, Clk and D are tied high.

The interrupt source and the /ICRCLR are out of phase by half a cycle, and are active only for 1 full cycle.  So... the interrupt source can be half a cycle earlier, or half a cycle after the /ICRCLR signal.

PHI2      --__--__--__--__--__--__
IRQsource -----------__-----------
/IRCLR    ------------__----------

PHI2      --__--__--__--__--__--__
IRQsource -----------__-----------
/IRCLR    ----------__------------
```

dmolinagarcia, 2023-02-05:
I need to confirm the behaviour of the FF when this happens on both cases. Does it really trigger the IRQ? How can I prevent it?

dmolinagarcia, 2023-06-23:
After solving #12 this seems to be fixed too. But further confirmation is needed.

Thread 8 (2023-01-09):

Check if pdf are updated for schematic

dmolinagarcia, 2023-01-09:

dmolinagarcia, 2023-01-24:
Updating all pdfs. Will be fixed in v0.2.0

Closed 2023-01-24.

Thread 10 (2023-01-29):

TIMERA/TIMERB underflows issue.

dmolinagarcia, 2023-01-29:
From CIATEST 01.cmpold. Wheneven TIMERB is loaded (or force loaded) exactly when it overflows, real CIA seems to skip an interrupt, where 74HCT6526 doesn't. This causes NMI 51C6 to fail on the test.

This is the only value that fails.

dmolinagarcia, 2023-01-30:
Looking at test results... it seems the opposite, I skip the IRQ, real CIA doesn't but... totally unsure at this point.

dmolinagarcia, 2023-02-05:
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

6526 on the left, 74HCT6526 on right. When TIMERB underflows right after TB Forceload, the underflow is missed, and so is the pulse, and the interrupt.

dmolinagarcia, 2023-02-05:
And...

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

Logisim does not share this behaviour. IRQ fires one cycle later, but still fires.

dmolinagarcia, 2023-02-06:
Needed test!

Run the test but with different values. Verify that I'm indeed triggering the timer pulse and IRQ on the exact cycle. As IRQ is not execute until current instruction ends, I may be firing with a cycle offset and still don't see it.

As the whole test runs fine, I have the feeling I'm triggering on the exact cycle, but I want to verify it.

Then focus on how to get the underflow while reloading!

dmolinagarcia, 2023-02-06:
Bite me!

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

According to logisim, TBLOAD is high during 1 cycle, but start is high for two cycles. Enough that on the next cycle, to the forceload, the interrupt is triggered. Still not 100% accurate but.. 95% closer than my current version.

I need to measure 74HCT6526 with the same values as this last test.  According to logisim, there's plenty of time for the pulse to happen... it isn't even an asynchronous event, so, why am I missing it?

dmolinagarcia, 2023-02-08:
What signals do I need for this test?

- PHI2
- /CS (CIA2)
- /NMI
- A[3..0]
- TA[4..0]
- TBis0 (Underflow Signal from timer block)
- TBLOAD (output from CREG)
- TBPRECOUNT (Output from first FF in pipeline)
- ICR1
- TBStart (output from CREG)

Son 17 señales. Puedo prescindir de /CS (Lo calculo desde A) o de parte de A, lo calculo desde el flujo del programa.

dmolinagarcia, 2023-02-13:
I'm thinking of a reduced test that I can do with a 8ch channel.
* PHI2
* /CS (CIA2)
* PB6 (TAPULSE)
* PB7 (TBPULSE)
* TBLOAD
* TBPRECOUNT
* TBSTART (Output from CREG, not the register value)

But... I may have found a solution. Neither TBLOAD nor TBHI when not running should clear the pipeline, but they do. TBHI does not matter, as timer is not running, so pipeline is already empty, but.. TBLOAD... why!!!!

If I reset the clock pipeline with TBPULSET, and have the other reload sources reset only the LOAD ff. It may just work. Just maybe...

dmolinagarcia, 2023-02-24:
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

Indeed, this seems to be case, at least on LOGISIM6526. However, as forceload does not clear the pipeline, count differs by one. I need to add a DFF to delay forceload by 1 cycle. Seems to work on LOGISIM, time to do some real testing.

dmolinagarcia, 2023-02-26:
Work in progress. I am adapting B1. From it's original v0.1.0 form it's now a propore 0.1.1 and still works. Will keep upgrading it until 0.2.1

dmolinagarcia, 2023-03-18:
Finished build ov v0.2.1 B1. Unitary tests still works, but 01cmpold is worse than before. The missed underflow is still missing, and there are a few more failures. Will revert to 0.2.0

dmolinagarcia, 2023-03-21:
B1 and B2 upgraded to v0.2.1. The 51C6 failure is fixed but new failures are introduced. When TA=10 and both FL=1 It seems TB underflows earlier than expected. Should this be fixable, a fix will be introduced in 0.2.1 again.

Further testing required.

dmolinagarcia, 2023-03-21:
A wrongfully cut trace (And one that was supposed to be cut, intact) were the cause of this. Once this has been fixed, 01cmpold success.

This fix will be incorporated in v0.2.1

Closed 2023-03-21.

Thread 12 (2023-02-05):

02CIATIMERS

dmolinagarcia, 2023-02-05:
Timer pulse on original CIA is aligned with PHI2 falling edge. On 74HCT6526 is aligned with posedge.

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

Fixing this could alter all IRQ timings! Be careful.

dmolinagarcia, 2023-02-07:
I need to run several test, with TA underflows, TB underflows, TA/TB underflows.

dmolinagarcia, 2023-02-11:
HCT fires the timer pulse half a cycle late, but has the same value at PHI2 falling edge, so it should be read-identical via the PB pins. Still IRQ fires at the same time, so it may not be worth fixing this.

I need to move counting earlier (I fire the pulse as soon as the timer overflows, so theres no room to move the pulse earlier, without altering the whole pipeline).

I've been trying for a couple of days, and the pipeline is so delicate, any changes breaks it.

Moreover, if I count at PHI2 falling edge, I may not read a stable value so a latch would be needed, adding to more ICs (8bit latches) to the board.

All other timings seem perfect, at least from a CPU POV. This will remaing as is for now.

dmolinagarcia, 2023-02-12:
Note to self. If I ever go this route, I need to replace the 244 with 373. They will latch the timer output on PHI2 high, so, when PHI falls, they retain the previous value from the timer, while they do their thing.

This me be extended to all Boards. And this may be well my biggest failure :/

dmolinagarcia, 2023-03-29:
Issue renamed to reflect reality. This issue is behind the failure of test 02CIATIMERS. At least that's my current feeling. Emulator tests of 02TIMERS shows that, the very cycle the timer is reloaded, ICR bit is set. (This is NEWCIA behaviour) on OLDCIA, TIMERA does this, but TIMERB ICR is enabled one cycle later.

So, my switch between old mode and new mode is wrong. I need to move both Timers interrupts one cycle earlier (Danger! I need to re-do the pipeline 😭) And the OLD vs NEW change is to delay TIMERB by one cycle, not the interrupt being fired.

I need the full 02 test capture with the logic analyzer, with some changes.
PB7 and PB6 should output timer pulses. This should be captured
PHI2, should be captured
/CS for the CIA, captured
/IRQ as a bonus
On the 74HCT6526, I can add ICR0 and ICR1 too.

I can infer the registers from the code so the are not needed. Capture single subtest at a time. We're looking at 20*200 cycles max per test, so it should be easy to compare.

What am I looking for? Exactness of the pulse (ok ok, I know It is delayed by half a cycle)

dmolinagarcia, 2023-04-10:
OLD vs OLD (bottom result)

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

NEW vs NEW (again, bottom result)

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

dmolinagarcia, 2023-04-10:
TIMER A interrupt shows no difference between new or old. It's timerB the one that has a difference. TIMERB interreupt seems to fire a cycle earlier on NEW cias.

My CIA behaves like an old one. Keep in mind, this is always relative to the ICR register. I am setting the ICR bit as soon as the overflow happens. there's  no room to fire earlier.

dmolinagarcia, 2023-04-11:
Bite me! I'm getting it al wrong!

on first test, when reading ICR, I'm reading a 0 when there should be a 1, but not because I'm setting it half a cycle late... The 1 I should be reading, has fired long before, right at the end of cycle B.

I am clearing the ICR when I shouldn't. That's what I need to tackle. Issue now feels to exists only at ICR level.

dmolinagarcia, 2023-05-01:
After analyzing the test line by line, my failure comes from clearing interrupts too late. So I miss already set interrupt, by creating the clear before it even triggers.

Moving the clear for TA one cycle earlier, I am getting TA with no IRQ to end with OK!

This is stage one. To change from NEW to OLD, Clear of TB needs to move from where it is now (OLD) to one cycle earlier (NEW)

Still some differences in the IRQ enabled tests. Full capture of both old and new (mos and hct9 is done. time to analyze it!

dmolinagarcia, 2023-05-01:
STAGE 1

HCT-NEW
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

HCT-OLD
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

MOS-NEW
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

MOS-OLD
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

dmolinagarcia, 2023-05-08:
Some changes to ICR have been applied.
STAGE0. Cleanup of the dangling flipflop. Glued to the board and with bodge wires replaced. Everything still works the same, but looks much nicer.
STAGE1. ICR0 reset moved one cycle earlier. Fix fixes test 5
STAGE2. Same for ICR0, however, OLD still resets after two, NEW after one
BONUS. This seems to be behind timerB bug.
STAGE3. ICR7 moved one cycle earlier for NEW mode. Works fine!

This is enough to pass 02NEW.

02OLD still shows some issues, which I expect to fix in the next two stages
STAGE4. ICR CLEAR. Reset both ICR7 DFF at the same time. Right now, second one is delayed
STAGE5. IRQ. I have the feeling IRQ does not clear at the same time as ICR7, so I may need a new 74HC74 for this.

None of the above is applied to the schematic.. When S4 and S5 are done and validated, everything will be updated.

dmolinagarcia, 2023-06-19:
Next steps.

Consolidate :
- Stage 1. Fixes TA clear. Same for both modes
- Stage 2. Switch for TB clear. /ICRCLR1 for NEW /ICRCLR2 for OLD
- Stage 3. ICR7 switch. One cycle earlier for NEW

This is confirmed as good.

Then...

Stage 4 alters the clear of ICR on OLD mode, clearing it one cycle earlier. This alters the IRQ in OLD too. NEW shouldn't be affected.
Stage 5 adds 2 new FF for IRQ. The set is same as ICR7, but clear is different.

Adding 4 and 5 I'm getting weird results that I do not understand, so let's backtrack a bit.

- change the new FF so the clear is same as IC7. This should be the same as undoing stage 5.
- undo stage 4. Let's see if I get back to known conditions.

Once here, take capture of the test. Both new and old, HCT and MOS.

dmolinagarcia, 2023-06-21:
Rollback to STAGE3. 02NEW success. But IRQ is produced in a separate set of FF than ICR7.

02OLD fails in two scenearios.
A read right before the interrupt for TB clears ICR1 but not ICR7, so a 0x80 is read. I tried moving ICR7 clear forward, but it remains set always and needs a second read to clear ICR7. I think triggering the ICR7 set with TBPULSE instead of ICR1 can do the trick. Try this later today.

Also, the next iteration, no interrupt should fire. This can probably by fixed ltering the clear for IRQ.

Now that I have separated ICR7 and IRQ, this two issues are independent.

But, as everything checks out in NEW mode, it may be a good idea to make a commit (v0.2.2 I think) with NEW mode working. I really need to consolidate the schematic, as B3 is becoming more and more hard to follow.

dmolinagarcia, 2023-06-21:
Hold your horses!

I've managed to succesfully apply a STAGE4 that fixes the first remaining issue:

A read right before the interrupt for TB clears ICR1 but not ICR7, so a 0x80 is read. I tried moving ICR7 clear forward, but it remains set always and needs a second read to clear ICR7. I think triggering the ICR7 set with TBPULSE instead of ICR1 can do the trick. Try this later today.

First of all. All interrupt sources must be cleaned by

<span style="text-decoration:overline">SIGNAL_ACTIVE_LOW</span>

dmolinagarcia, 2023-06-22:
And stage 5.

Clearing both IRQ sources on /ICRCLR1 makes both old and new 02 to succed :)

dmolinagarcia, 2023-06-23:
All of this will be implemented in release v.0.2.2

Closed 2023-06-23.

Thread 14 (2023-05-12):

Segregate CNT edge detector

dmolinagarcia, 2023-05-12:
CNT edge detector is made up of 3 DFF. First one needs to be HCT.
When TARUNMODE was removed from the CONTROLBUS, a pin was left there unused.
As theres enough realstate on B0, the edge detector can be moved there, and the syncronyzed edge pulse added to the controlbus.
This will use 3 DFF on B0 (there´s 1 free already) so I'll be adding one more IC to B0.
In return, I can remove 9 DFF from B1, B2, B3 (3 each)
On B1, theres a unused FF, so I save 2 ICs
Same for B2. 2 less ICs
Same again on B3, 2 less ICs.
So I save 5 ICs total with this change.
Beware of B3, Edge detector is different, but should work OK with the one on B1 or B2.

This will trigger a new minor release. V0.1.x boards have TARUNMODE on the unused CONTROLBUS pin. So they will be incompatibilites, unless some traces are hacked.

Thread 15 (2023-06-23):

Timer Pulses are offseted half a cycle

dmolinagarcia, 2023-06-23:
Timer pulse on original CIA is aligned with PHI2 falling edge. On 74HCT6526 is aligned with posedge.

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

Fixing this could alter all IRQ timings! Be careful.

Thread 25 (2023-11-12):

TOD Count is (wrongly) Enabled by default

dmolinagarcia, 2023-11-12:
As both TENTHs and HOURS are written to on reset... SET predominates on the flipflop.

We can remove RESET from TENTHs write. Let's see what value do we have on restart!
Or reverse bits, and set COUNT to /Q on the flipflop.

dmolinagarcia, 2023-11-14:
Some mistery here... After retinning the stack connectors, this is now working. I will keep it open until I can fully confirm it is working fine.

dmolinagarcia, 2023-11-19:
Still working, every time. Assuming it's OK. Will reopen if necessary.

Closed 2023-11-19.

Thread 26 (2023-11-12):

TOD AM/PM flag is not wired properly.

dmolinagarcia, 2023-11-12:
Issue on v0.2.2. AM/PM flip DFF will never be set. Look into it.

dmolinagarcia, 2023-11-19:
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

changed into

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

H7_FLIP FF is properly rewired. H7_FLIP is delayed by one cycle so after writing a 12 or 92, it doesn't get lost to SET or RESET on H7.

Also, it is gated with /LOADH so succesive writes still work.

Fixed!

Closed 2023-11-19.

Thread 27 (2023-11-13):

TOD is not setting ICR2

dmolinagarcia, 2023-11-13:

dmolinagarcia, 2023-11-13:
On first inspection. TODIRQ is not set on B4. Will need to check the status of all 4 comparators. Maybe start with a reflow.

dmolinagarcia, 2023-11-15:
ALARM register for seconds was not properly soldered. I have reflowed it and now I get TODIRQ. However, ICR2 is not getting set yet. Maybe the stack connector, maybe an issue on the ICR.

Also, right now ICR2 fires based on TODIRQ level which is not right. Under normal conditions, TODIRQ will be active for at least a tenth, so multiple IRQ fires are possible. ICR2 should be edge triggered.

dmolinagarcia, 2023-11-15:
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

TODIRQ is ok on B3, measured on 335.1 (04 input)
However /TODIRQ at 332.4 does not reach 0v. It bottoms at 0.5v.
ICR2, measured at the 244 input (336.4) never goes high.

U335 or U332 maybe faulty. Reflow, and replace.

dmolinagarcia, 2023-11-17:
Short to ground under U337 that affected ICR1 and ICR2.

Fixed after removal, cleanup and resolder of U337.

Closed 2023-11-17.

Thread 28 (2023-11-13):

SDR sends fails

dmolinagarcia, 2023-11-13:

dmolinagarcia, 2024-01-27:
Test SDR send on both units. Identify actual behaviour. Register it and elaborate test case.

dmolinagarcia, 2024-02-01:
SDR send is failing on both units.

On U1, only 1's are shifted out. CNT pulses seem OK, but no matter what I write into the register, only 0xFF is shifted out.

On U2. A single byte send seems OK, but two consecutive bytes causes some failures.

dmolinagarcia, 2024-02-01:
We will start with U1. Proposed test is as follows :

U302.11 is SP out
U302.6  is CNT out
U314.11 is SP driver. A 0 pulls SP down. A 1 lets it float
U313.17 is Q7. Bit to be shifted out
U313.12 is Cp. Clock pulses to Shift register.

This test will let me know if the issue is :
- Is the SP output failing? If it is provided with actual output, but not producing any
- Is the SHIFT register being pulsed? If it is, and actual byte shows up in Q7, shift is fine
- Maybe shift register is not being written to. Although, I don't think it initializes to all ones.

dmolinagarcia, 2024-02-03:
Test reveals SDR value is not being loaded onto the shift register.
S1 and CP (Setup signal and Clock pulse) to 299 are correct, so value should be loaded.
Is it possible the outout 299 is faulty? I've swapped both on U1, and now both output and input works. Bad solder or Bad IC (with only the output stage affected?)

Anyway, I am not unswapping them. It works, move on.

I am going to do a full dual send suite now.

dmolinagarcia, 2024-02-03:
Dual send has some issues.... LSB seems to fail every two bytes. I feel I am writing the second byte to the shift register too early.

More tests needed. Let's focus on SDR Send on U2 now.

dmolinagarcia, 2024-02-03:
U2 works the same as U1. Closing this issue. A new one will be created to handle the dual send issue.

Closed 2024-02-03.

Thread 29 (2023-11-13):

SDR receive issues

dmolinagarcia, 2023-11-13:
Sometimes we receive, sometimes we don't.

dmolinagarcia, 2024-01-27:
Test SDR receive on both units. Identify actual behaviour. Register it and elaborate test case.

dmolinagarcia, 2024-01-28:
Receive on U1 works without issue.

dmolinagarcia, 2024-01-28:
Receive on U2 works too.

Keep testing and close if confirmed

dmolinagarcia, 2024-01-30:
Tested OK. Both U1 and U2 receive without issues

Closed 2024-01-30.

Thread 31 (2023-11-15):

TOD invalid counts

dmolinagarcia, 2023-11-15:
I'm not checking the full nibble to trigger the ticks in TOD. A redesign with 74HC85 may be good for this. Although it will increase the IC count on an already very dense board.

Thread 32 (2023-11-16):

ICR1 is missing

dmolinagarcia, 2023-11-16:
TB underflow triggers IRQ and sets ICR7 (If enabled) but ICR1 is not set.

Suspecting a U335 fault while troubleshooting #27 (Apparently, Input was OK but output was not 0v but 0,5v) I did replace it. Then ICR1 was gone. U332 was also replaced (A Set in the FF didn't set it) but again, nothing.

A faulty IC? Solder ball? Broken trace?

dmolinagarcia, 2023-11-17:
Replaced again U335 as it was in very bad shape. Clean solder now.
I'm measuring U335.13 (TBPULSE) and U332.10 (/TBPULSE > /SET). Logic analyzer says they're OK. But no ICR1

dmolinagarcia, 2023-11-17:
Short to ground on the output buffer (ICR2 - TOD was also affected). Caused by unmelted solder paste under U337.

Fixed after removal of U337, cleanup and resolder.

Closed 2023-11-17.

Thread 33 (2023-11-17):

TOD IRQ should be edge-triggered

dmolinagarcia, 2023-11-17:
Test 409 hangs. (TOD+IRQ)

IRQ fires as soon as the alarm is reached. However, as TOD takes a while to clean... it never goes down.

dmolinagarcia, 2023-11-17:
In B3. Change this

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

To this

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

With this, ICR2 is now rising-edge triggered from TODIRQ. Otherwise, TODIRQ stays high for a tenth of a second, triggering IRQ after IRQ and (most likely) overflowing the stack and causing a crash.

Closed 2023-11-17.

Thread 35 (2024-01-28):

U1 B3 SDR Interrupt bit clear

dmolinagarcia, 2024-01-28:
I think I am clearing it with ICRCLR2. too many fixes, lost track of it. It should be cleared with ICRCLR1. Schematics for new releases are OK, it is just a build construction issue.

Check On U2 too to be safe.

dmolinagarcia, 2024-01-28:
U1 clear SDR with ICRCLR2
U2 clear SDR with ICRCLR1

So, when reading ICR on U1, ICR7 is not cleared on first run. Need to read twice.

Revisit

dmolinagarcia, 2024-01-29:
Cut trace between

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

And problem is solved

dmolinagarcia, 2024-01-29:
TOD IRQ cycle has changed. Still not exact to original, but closer. Issue solved.

Closed 2024-01-29.

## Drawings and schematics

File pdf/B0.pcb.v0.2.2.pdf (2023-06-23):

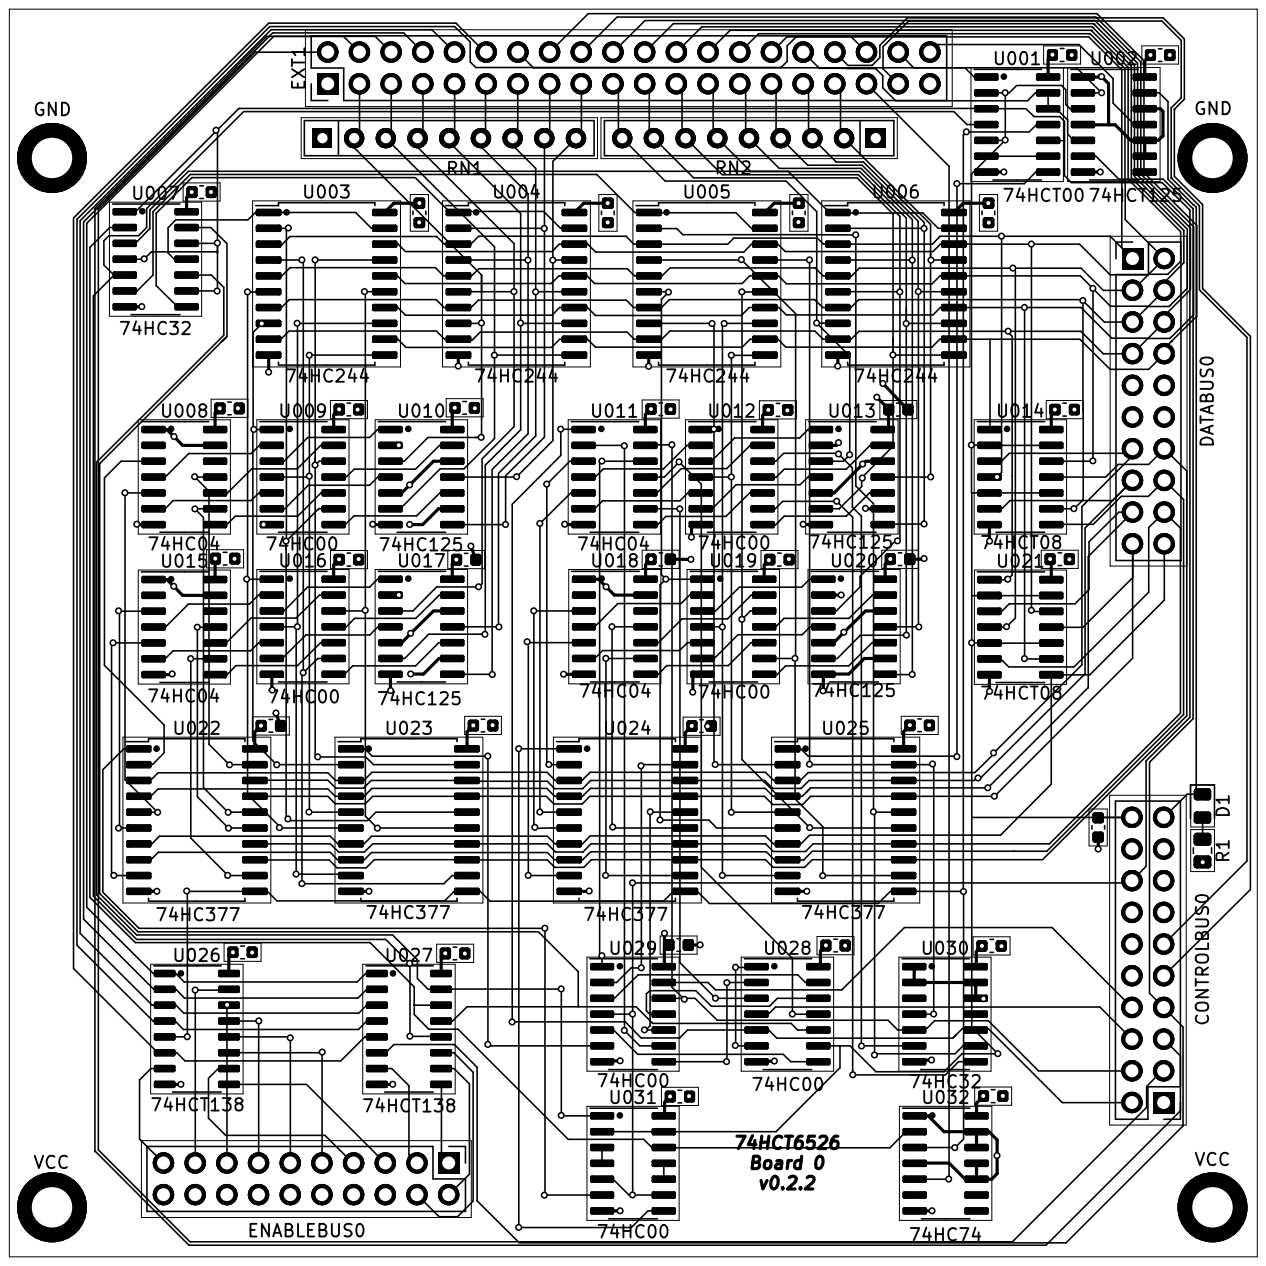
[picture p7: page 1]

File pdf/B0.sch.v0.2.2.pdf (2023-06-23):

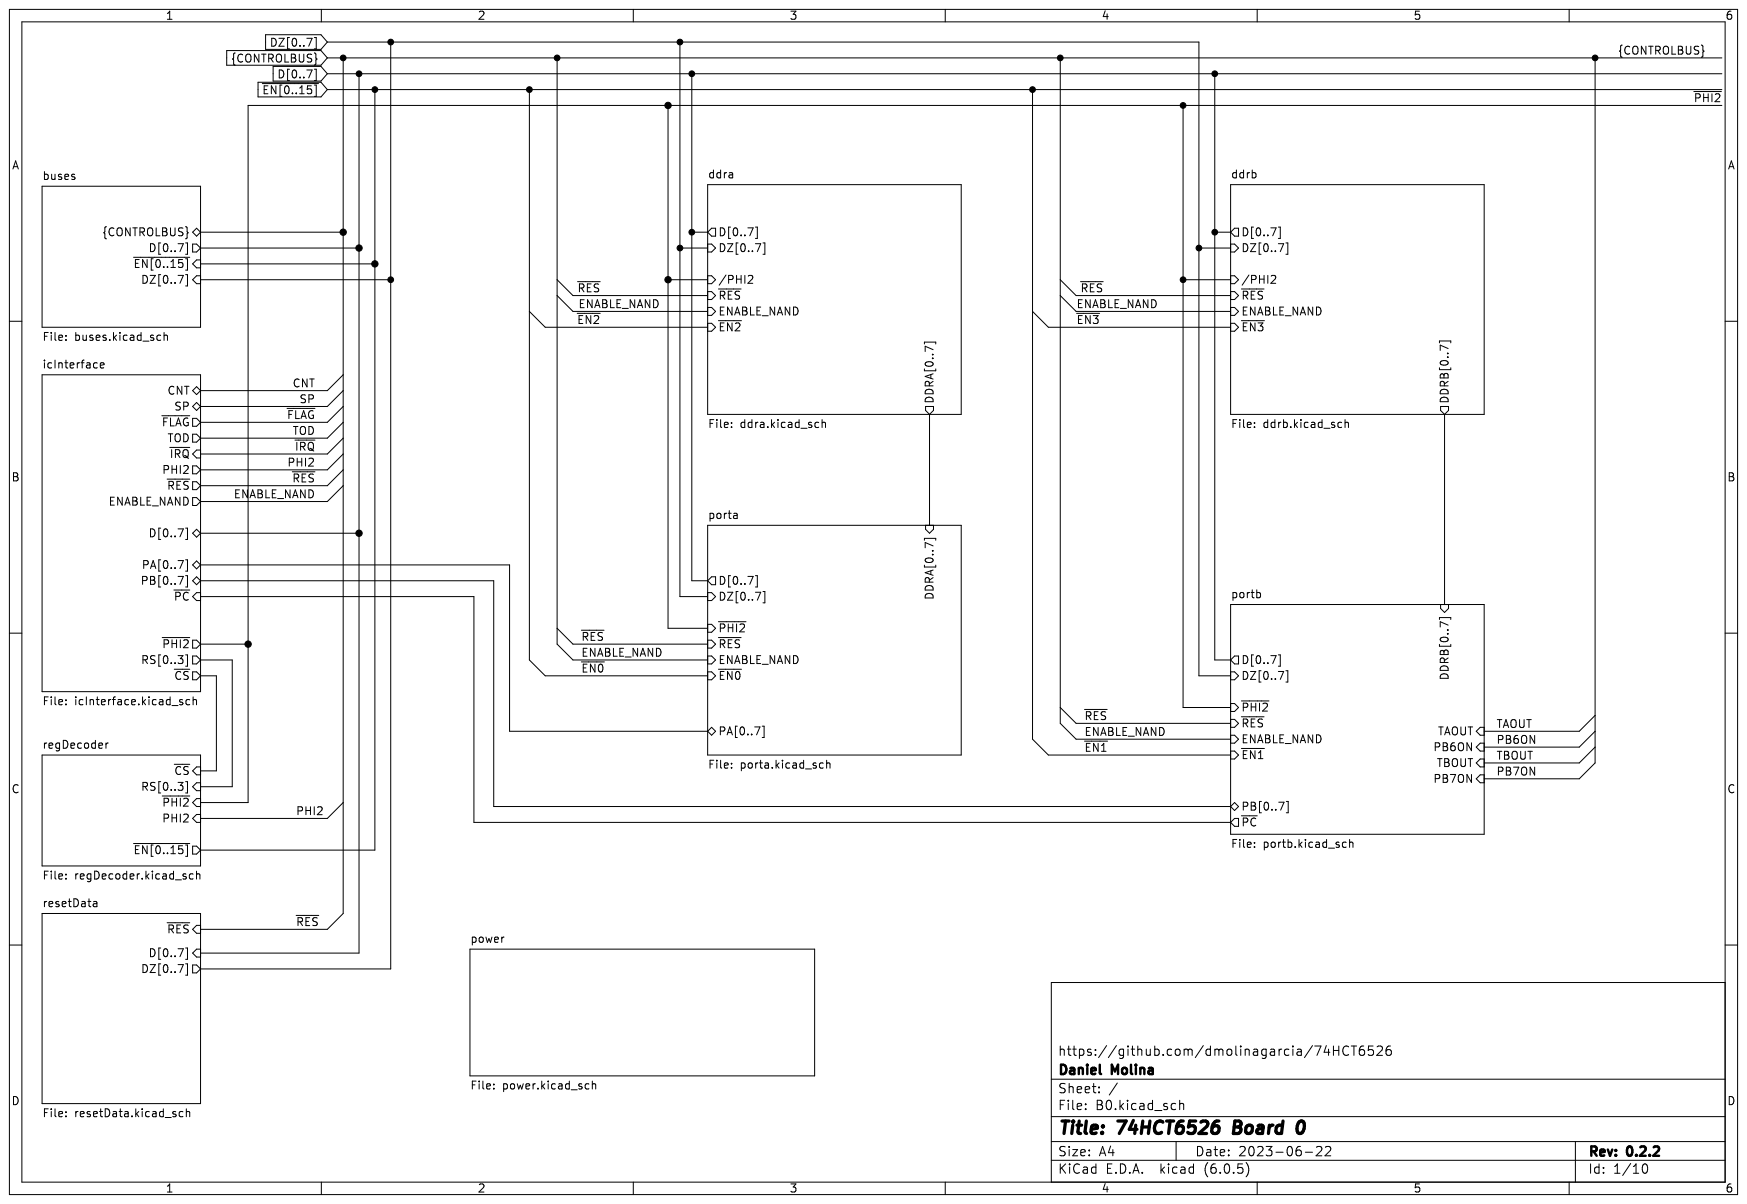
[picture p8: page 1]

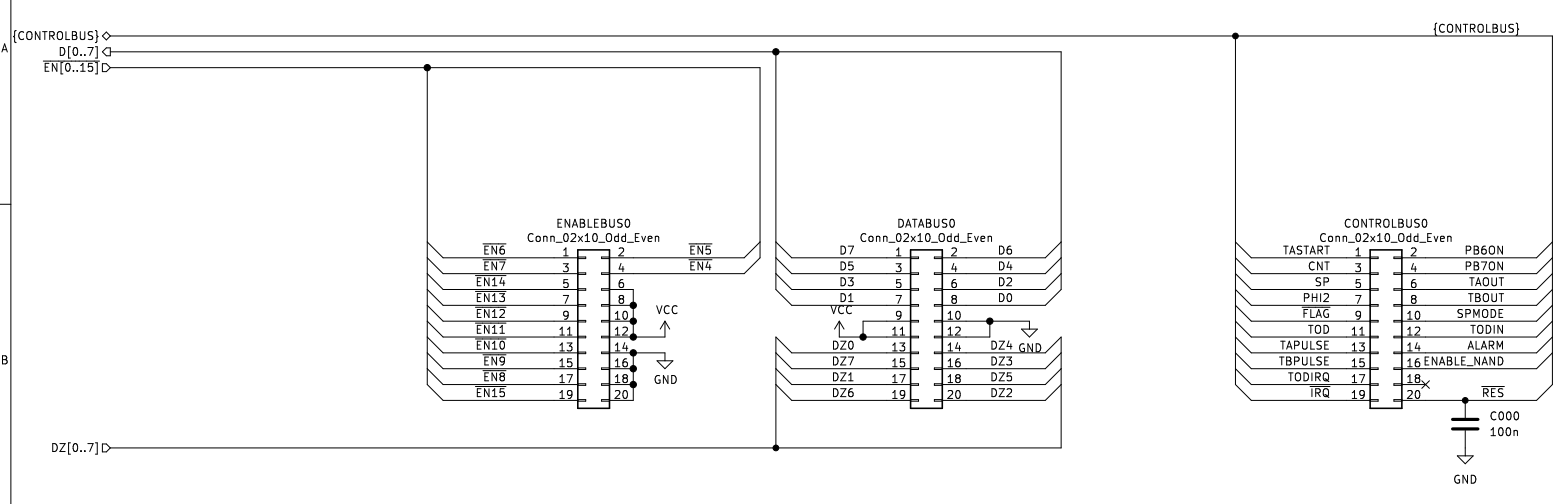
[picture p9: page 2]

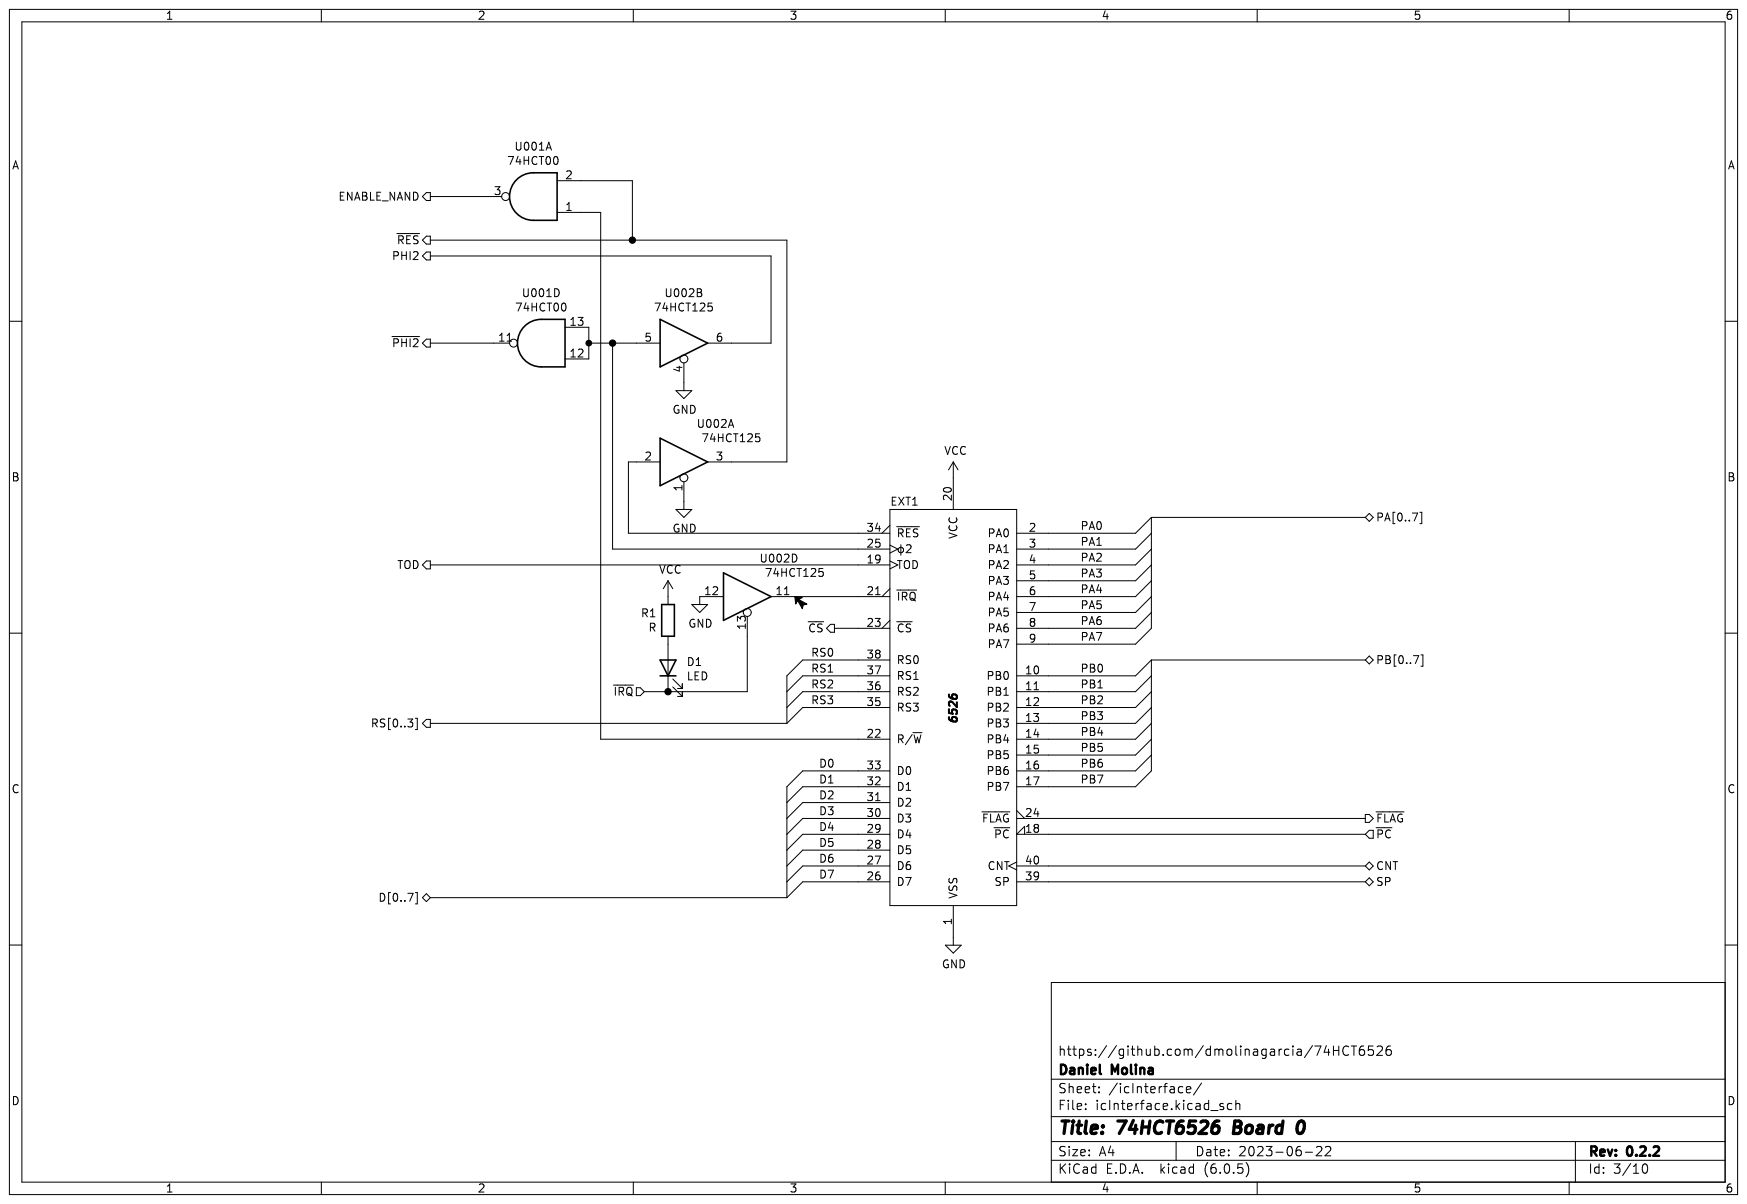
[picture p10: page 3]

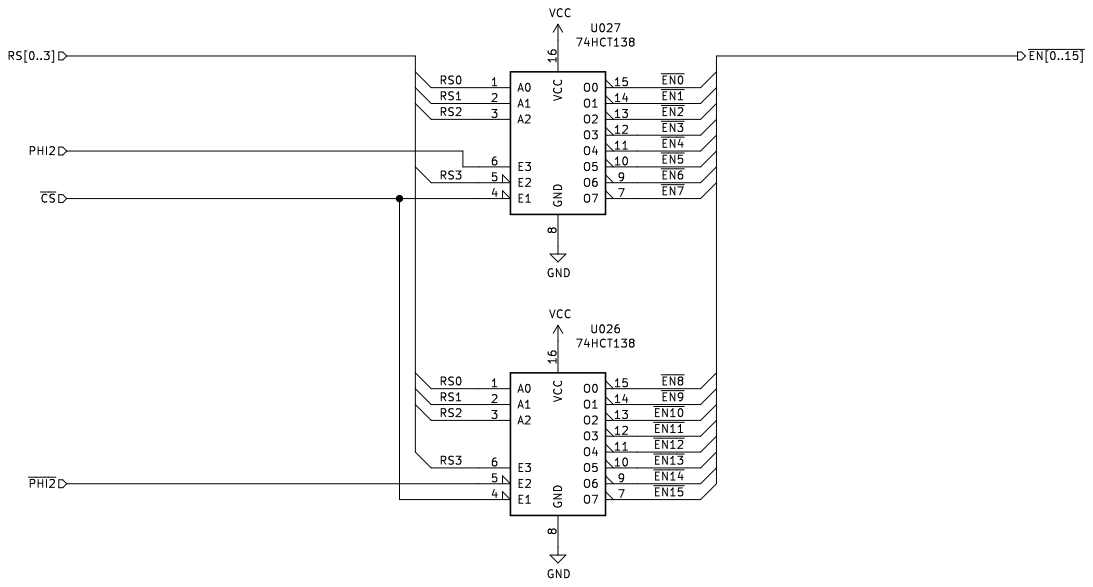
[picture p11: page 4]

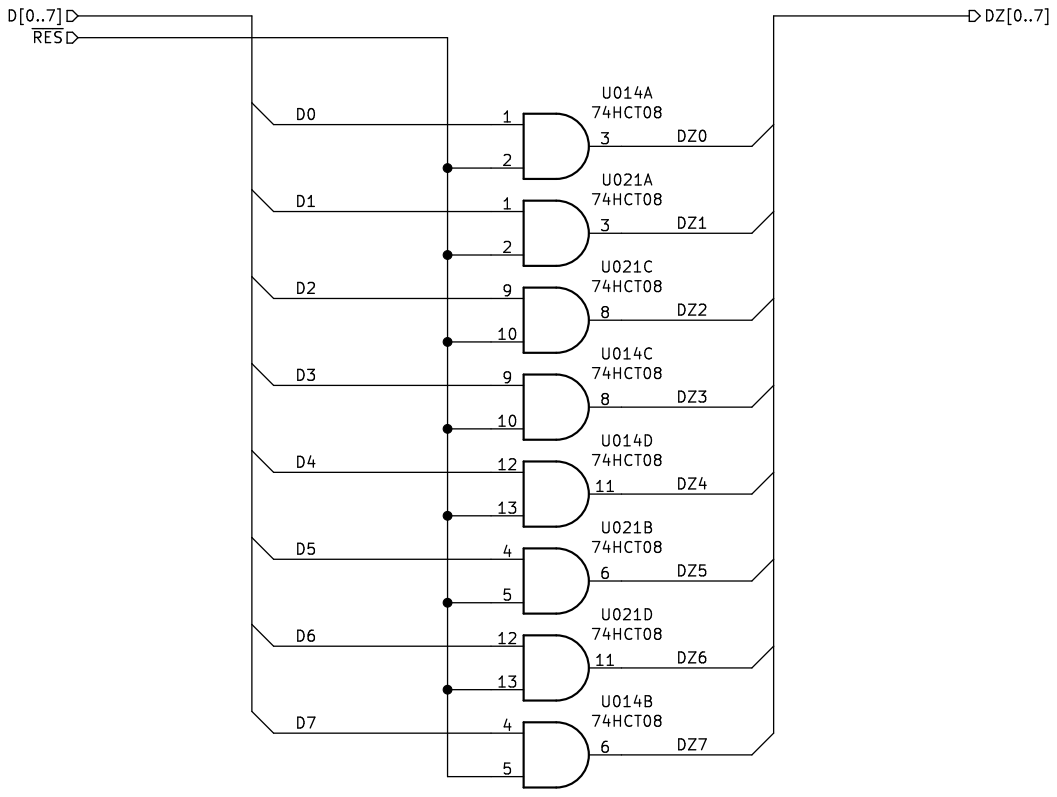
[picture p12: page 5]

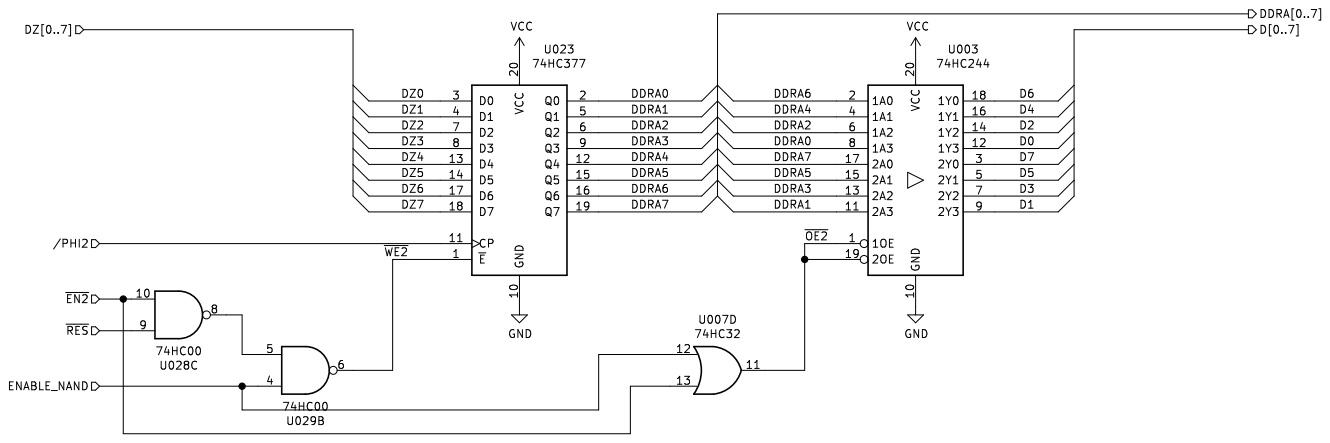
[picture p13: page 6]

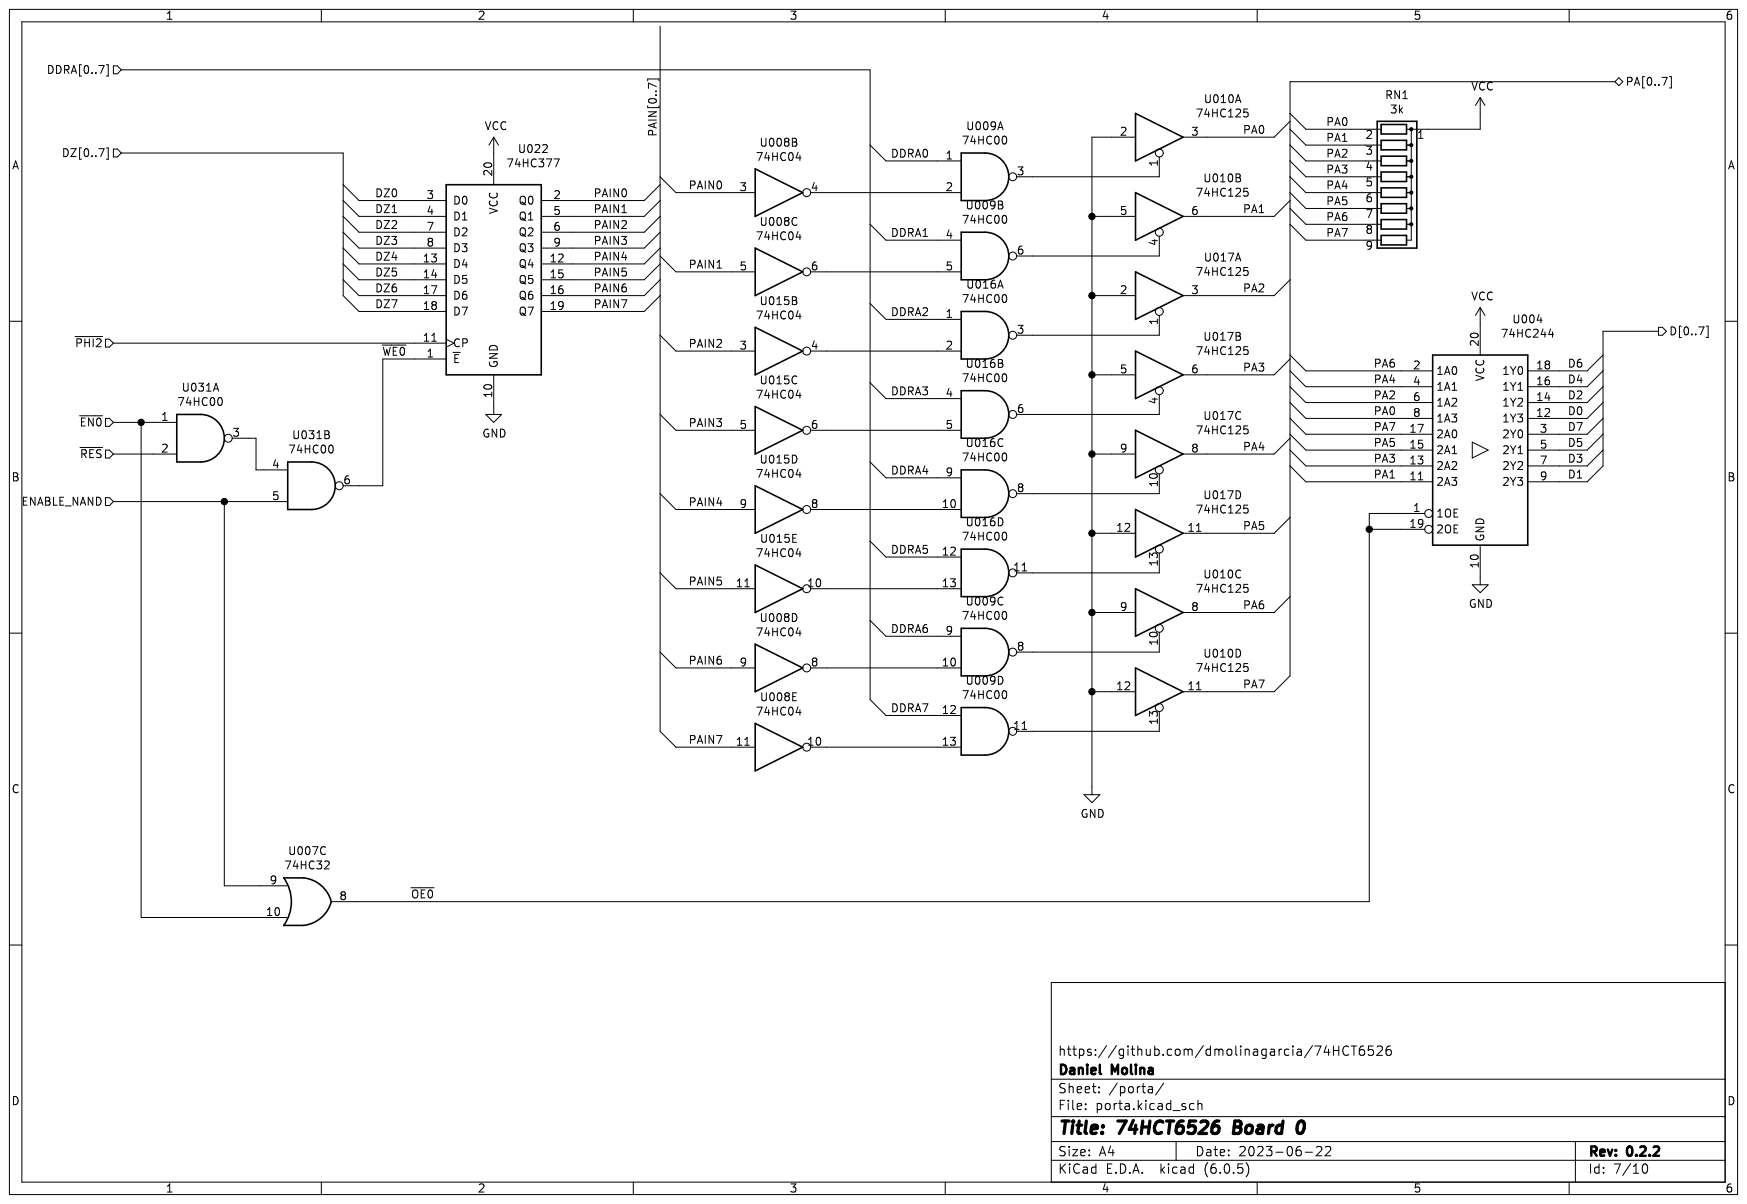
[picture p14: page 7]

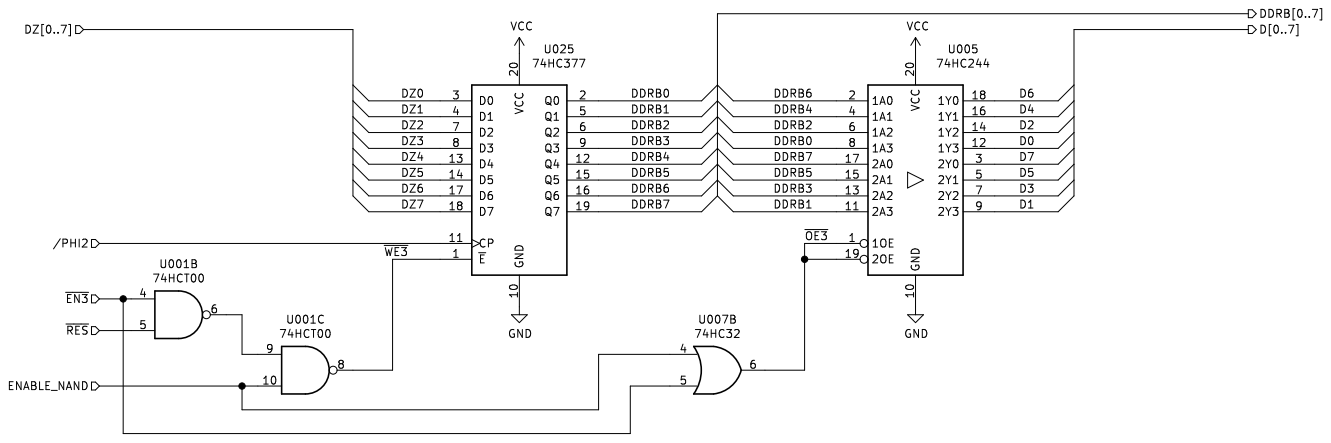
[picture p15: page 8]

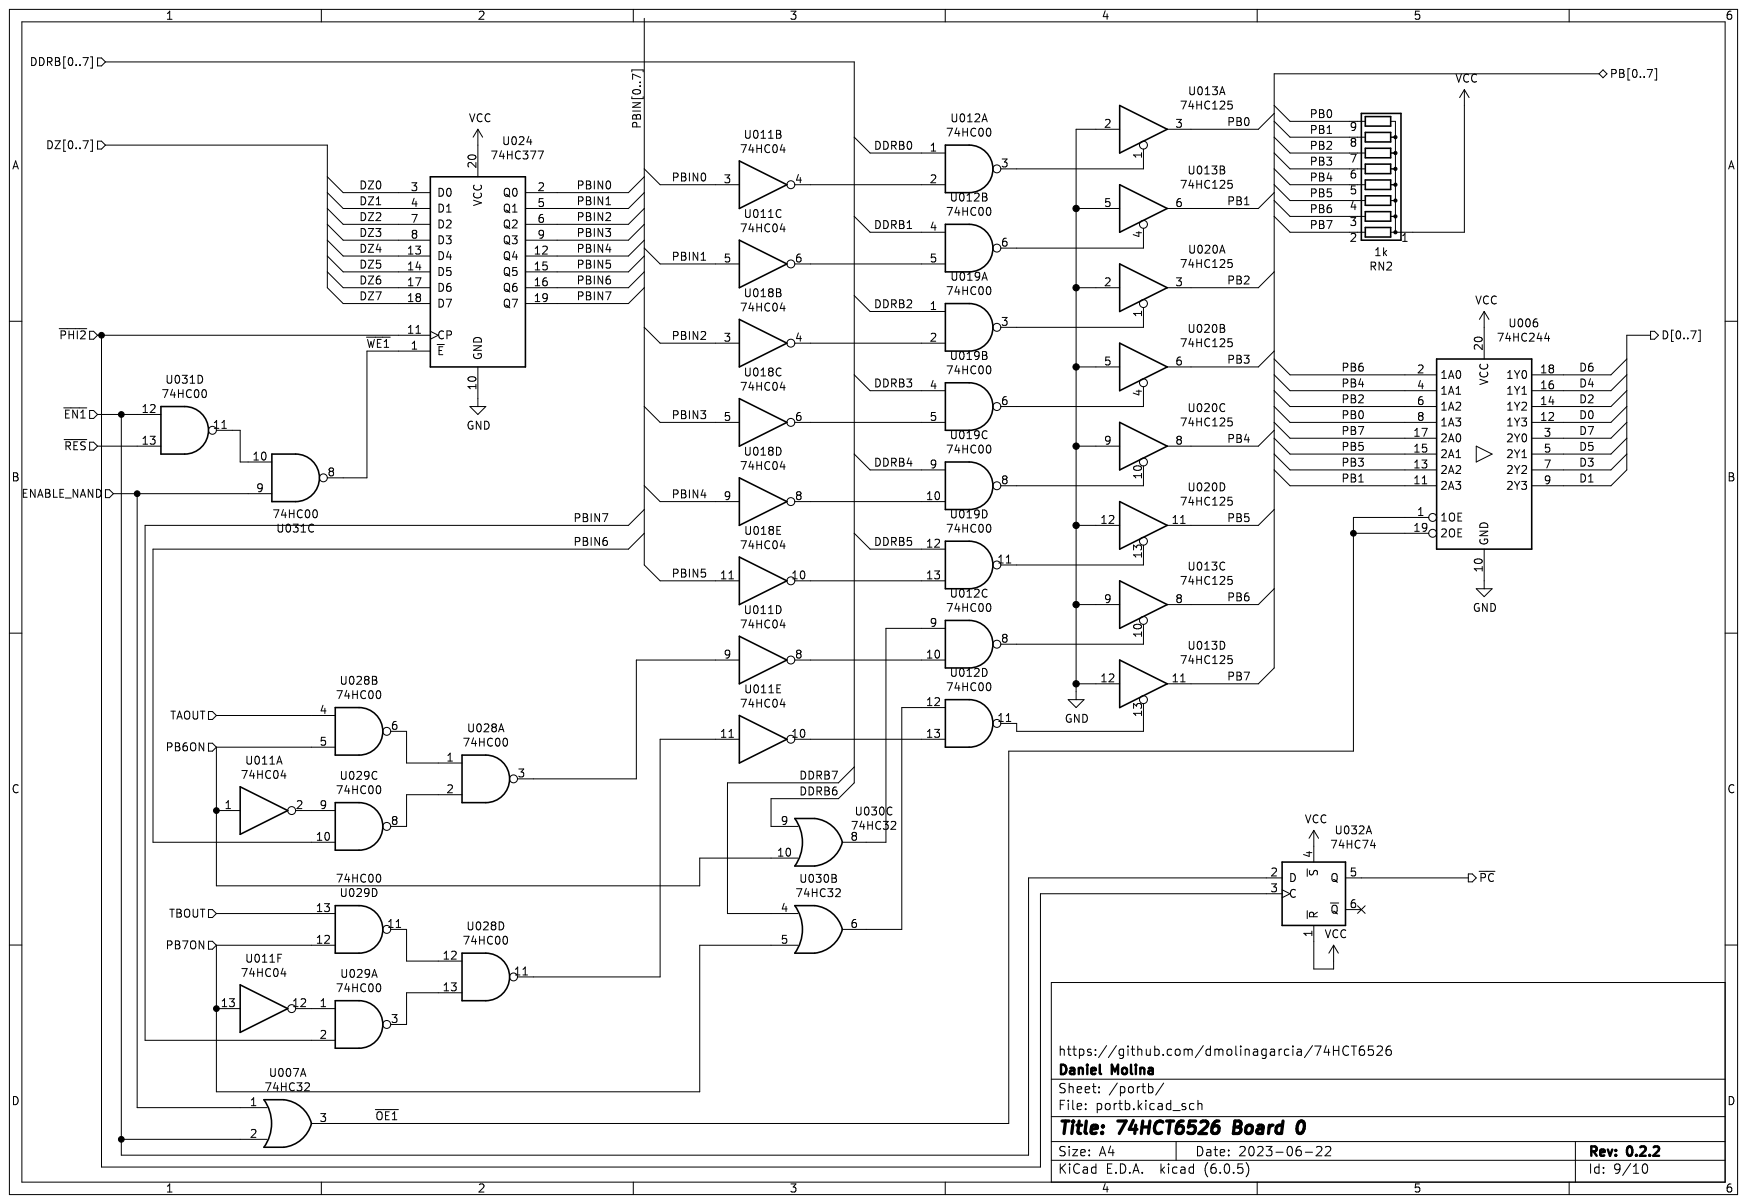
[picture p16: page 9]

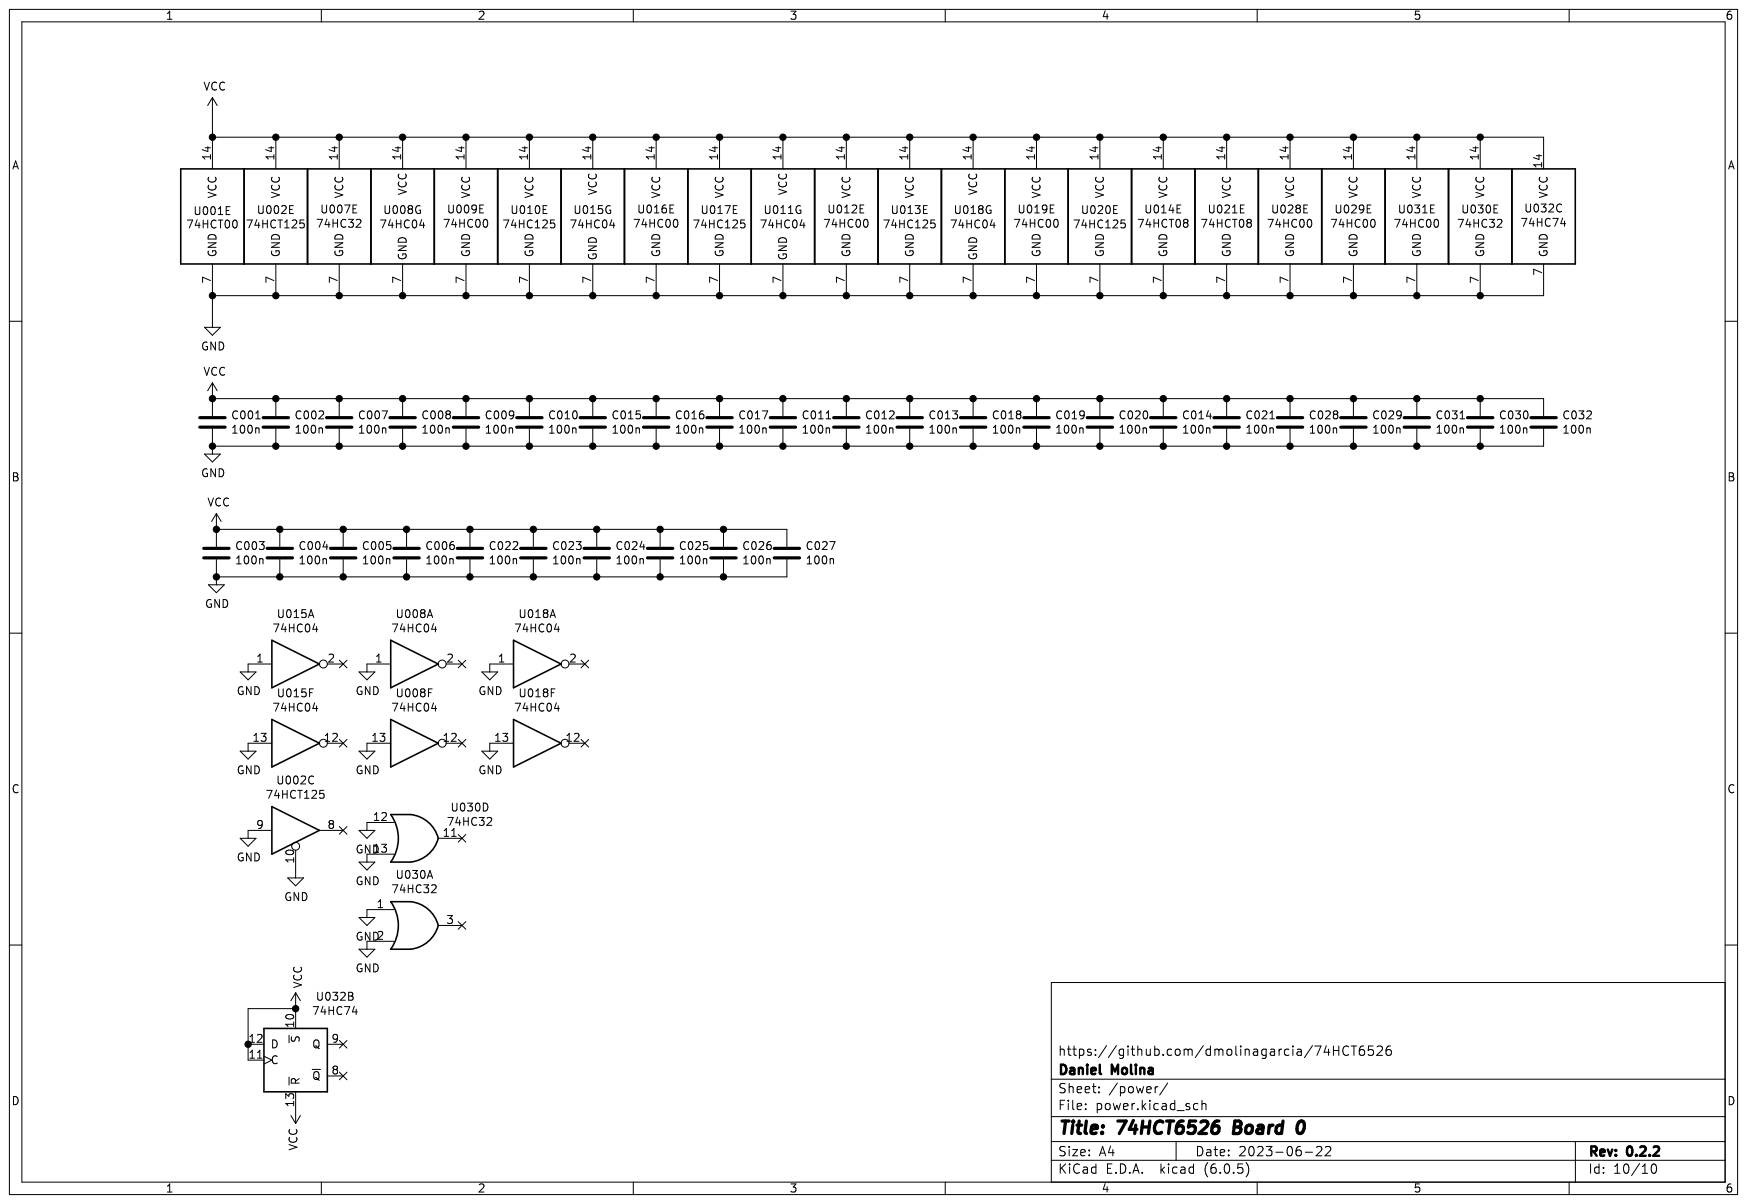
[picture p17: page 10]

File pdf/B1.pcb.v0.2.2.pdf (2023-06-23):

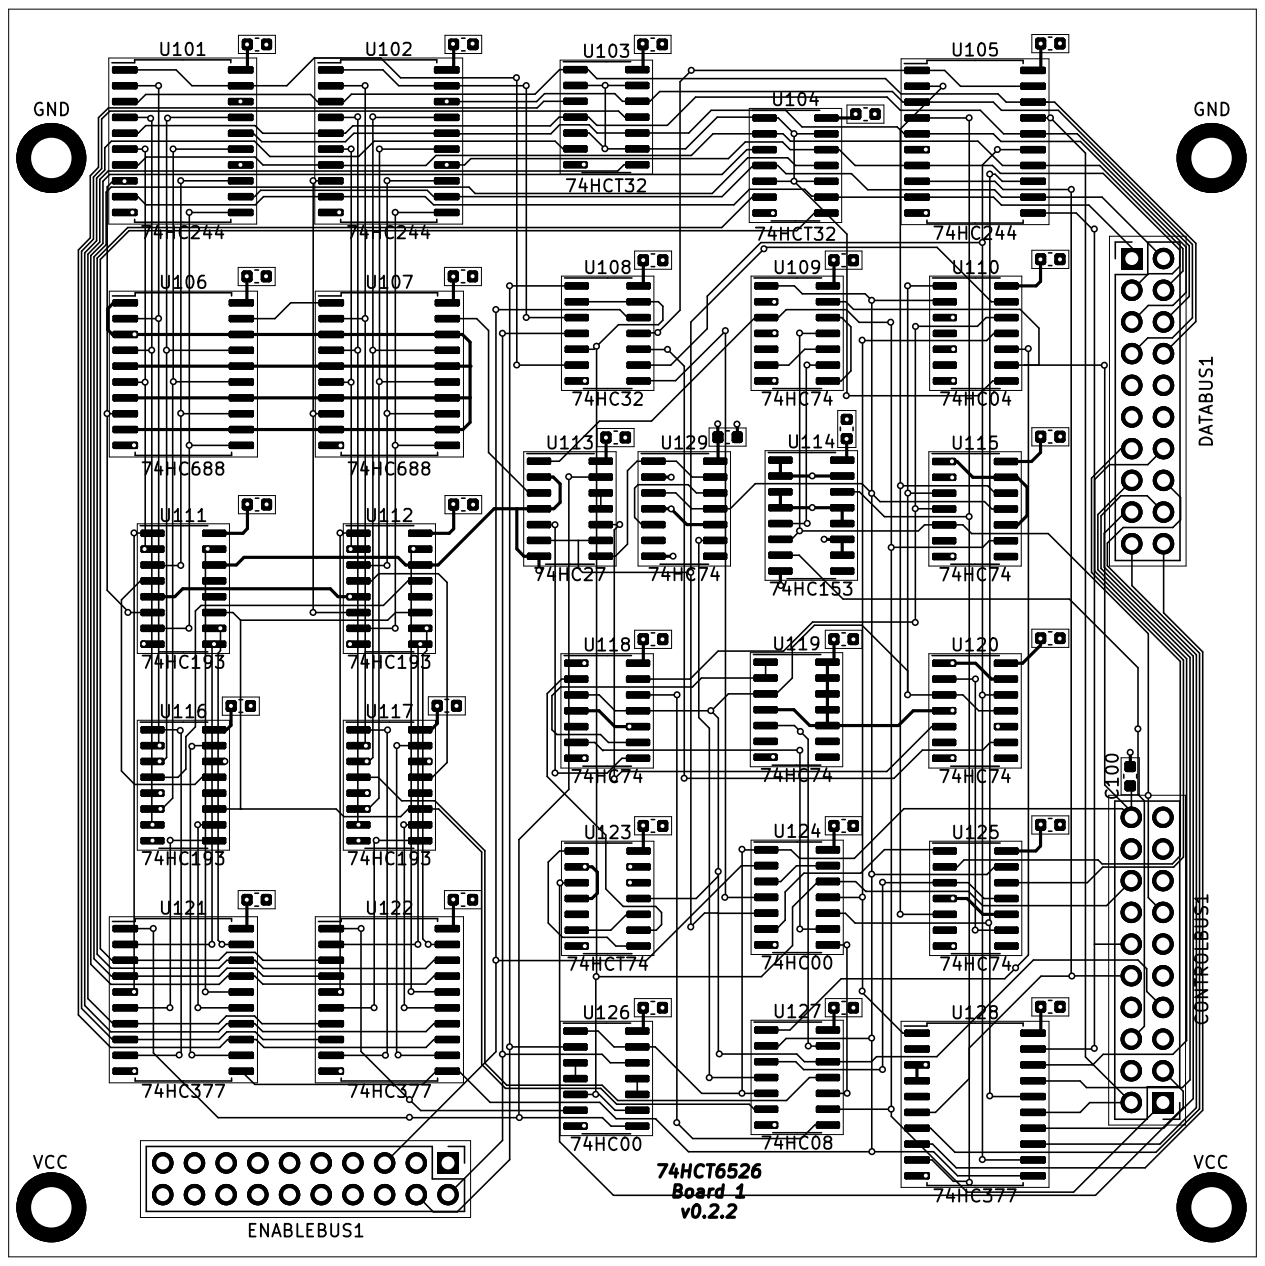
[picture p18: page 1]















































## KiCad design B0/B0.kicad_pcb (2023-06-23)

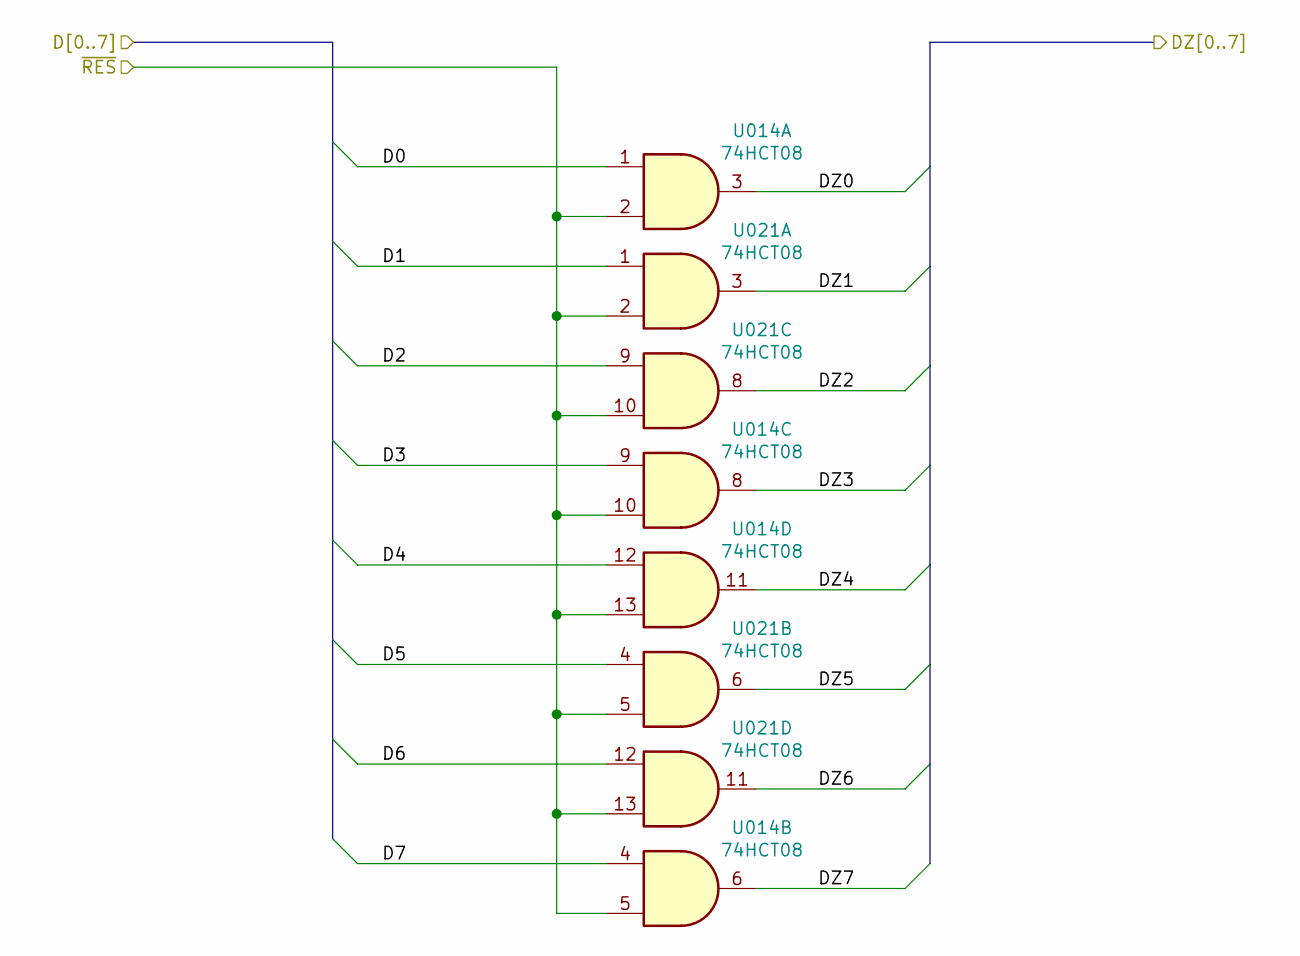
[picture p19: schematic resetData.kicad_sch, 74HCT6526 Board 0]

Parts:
U014, U021: 74HCT08; SO-14

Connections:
D0: U014.1; also elsewhere on the board
D1: U021.1; also elsewhere on the board
D2: U021.9; also elsewhere on the board
D3: U014.9; also elsewhere on the board
D4: U014.12; also elsewhere on the board
D5: U021.4; also elsewhere on the board
D6: U021.12; also elsewhere on the board
D7: U014.4; also elsewhere on the board
DZ0: U014.3; also elsewhere on the board
DZ1: U021.3; also elsewhere on the board
DZ2: U021.8; also elsewhere on the board
DZ3: U014.8; also elsewhere on the board
DZ4: U014.11; also elsewhere on the board
DZ5: U021.6; also elsewhere on the board
DZ6: U021.11; also elsewhere on the board
DZ7: U014.6; also elsewhere on the board
~RES: U014.2, U014.5, U014.10, U014.13, U021.2, U021.5, U021.10, U021.13; also elsewhere on the board

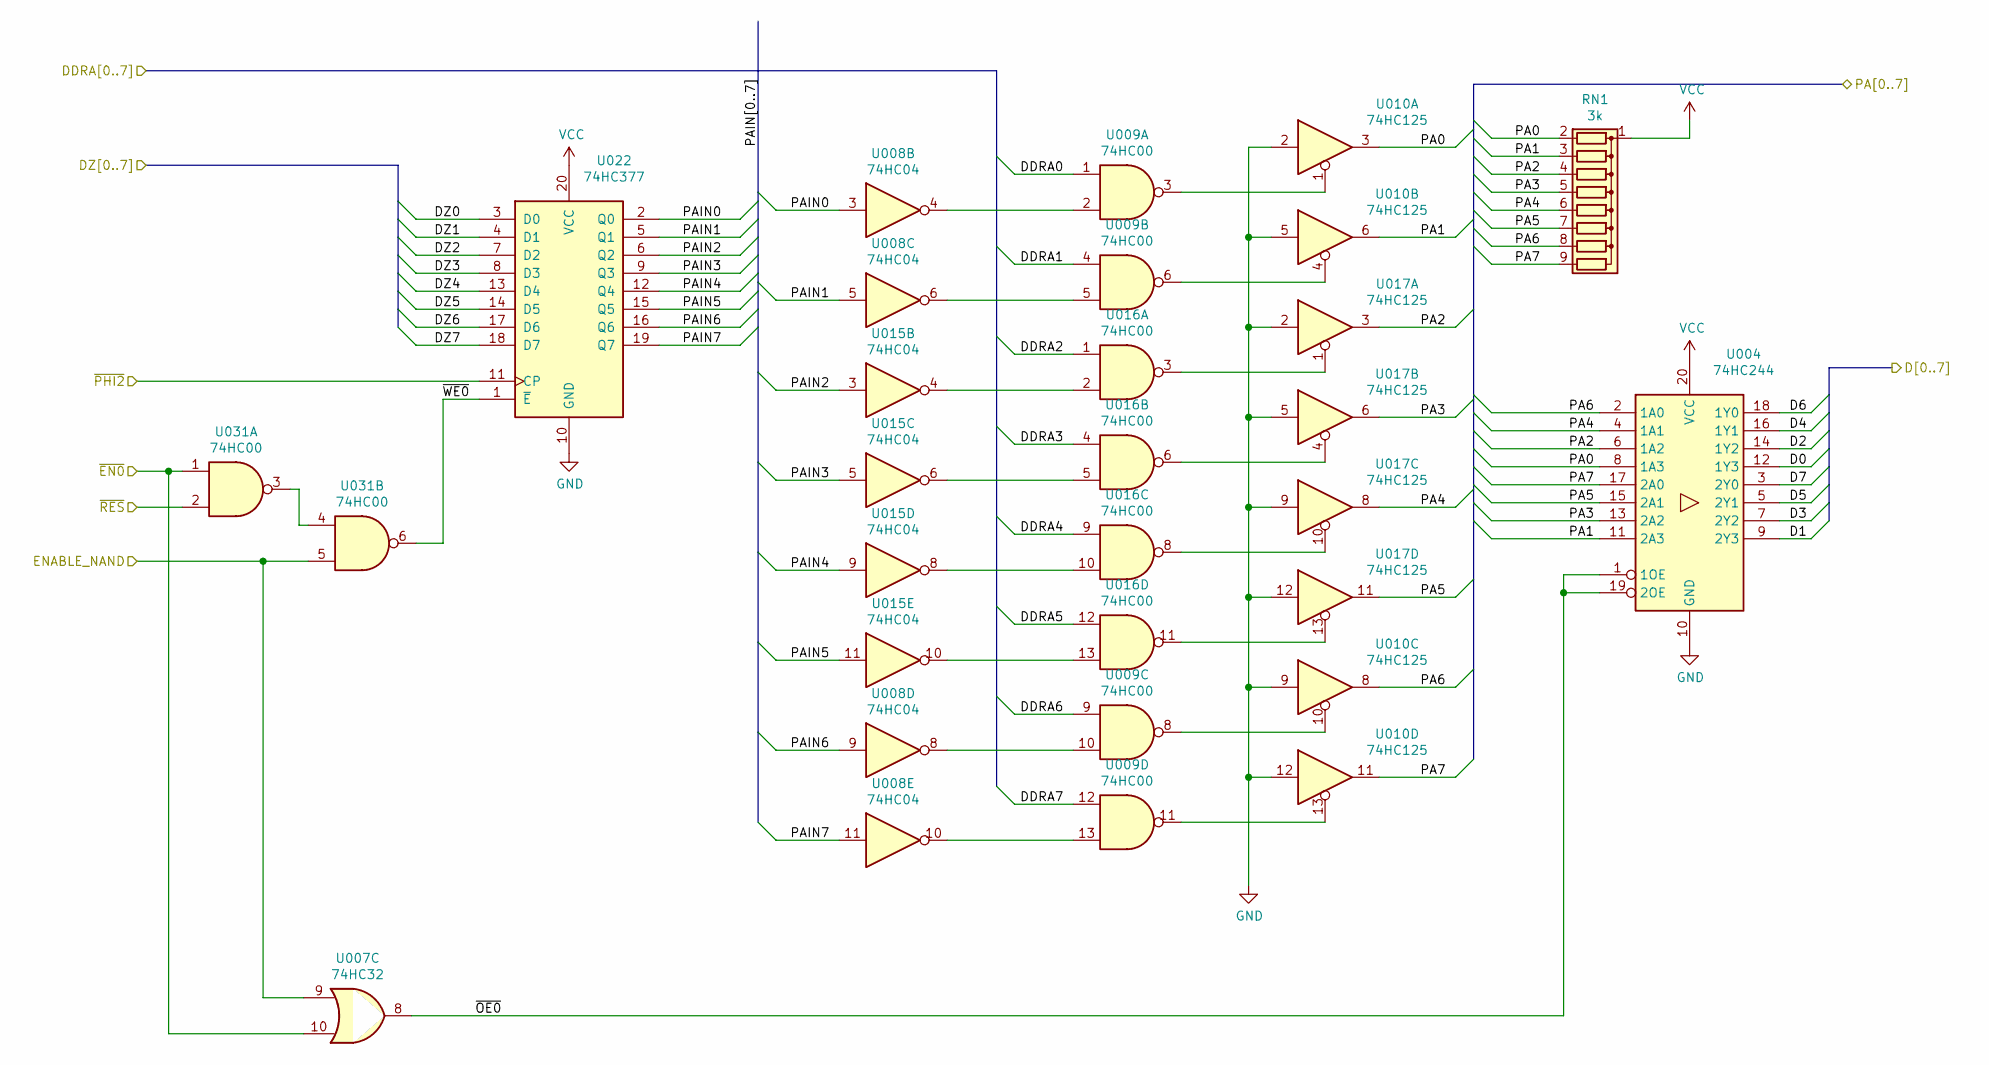
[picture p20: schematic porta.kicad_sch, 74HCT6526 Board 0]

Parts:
RN1: 3k; R_Array_SIP9
U004: 74HC244; SOIC-20W
U007: 74HC32; SO-14
U008, U015: 74HC04; SO-14
U009, U016, U031: 74HC00; SO-14
U010, U017: 74HC125; SO-14
U022: 74HC377; SOIC-20W

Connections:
/ddra/DDRA0: U009.1; also elsewhere on the board
/ddra/DDRA1: U009.4; also elsewhere on the board
/ddra/DDRA2: U016.1; also elsewhere on the board
/ddra/DDRA3: U016.4; also elsewhere on the board
/ddra/DDRA4: U016.9; also elsewhere on the board
/ddra/DDRA5: U016.12; also elsewhere on the board
/ddra/DDRA6: U009.9; also elsewhere on the board
/ddra/DDRA7: U009.12; also elsewhere on the board
/icInterface/PA0: RN1.2 (R1), U004.8 (1A3), U010.3; also elsewhere on the board
/icInterface/PA1: RN1.3 (R2), U004.11 (2A3), U010.6; also elsewhere on the board
/icInterface/PA2: RN1.4 (R3), U004.6 (1A2), U017.3; also elsewhere on the board
/icInterface/PA3: RN1.5 (R4), U004.13 (2A2), U017.6; also elsewhere on the board
/icInterface/PA4: RN1.6 (R5), U004.4 (1A1), U017.8; also elsewhere on the board
/icInterface/PA5: RN1.7 (R6), U004.15 (2A1), U017.11; also elsewhere on the board
/icInterface/PA6: RN1.8 (R7), U004.2 (1A0), U010.8; also elsewhere on the board
/icInterface/PA7: RN1.9 (R8), U004.17 (2A0), U010.11; also elsewhere on the board
/porta/PAIN0: U008.3, U022.2 (Q0)
/porta/PAIN1: U008.5, U022.5 (Q1)
/porta/PAIN2: U015.3, U022.6 (Q2)
/porta/PAIN3: U015.5, U022.9 (Q3)
/porta/PAIN4: U015.9, U022.12 (Q4)
/porta/PAIN5: U015.11, U022.15 (Q5)
/porta/PAIN6: U008.9, U022.16 (Q6)
/porta/PAIN7: U008.11, U022.19 (Q7)
/porta/~OE0: U004.1 (1OE), U004.19 (2OE), U007.8
/porta/~WE0: U022.1 (~E), U031.6
/~PHI2: U022.11 (CP); also elsewhere on the board
D0: U004.12 (1Y3); also elsewhere on the board
D1: U004.9 (2Y3); also elsewhere on the board
D2: U004.14 (1Y2); also elsewhere on the board
D3: U004.7 (2Y2); also elsewhere on the board
D4: U004.16 (1Y1); also elsewhere on the board
D5: U004.5 (2Y1); also elsewhere on the board
D6: U004.18 (1Y0); also elsewhere on the board
D7: U004.3 (2Y0); also elsewhere on the board
DZ0: U022.3 (D0); also elsewhere on the board
DZ1: U022.4 (D1); also elsewhere on the board
DZ2: U022.7 (D2); also elsewhere on the board
DZ3: U022.8 (D3); also elsewhere on the board
DZ4: U022.13 (D4); also elsewhere on the board
DZ5: U022.14 (D5); also elsewhere on the board
DZ6: U022.17 (D6); also elsewhere on the board
DZ7: U022.18 (D7); also elsewhere on the board
ENABLE_NAND: U007.9, U031.5; also elsewhere on the board
GND: U004.10 (GND), U010.2, U010.5, U010.9, U010.12, U017.2, U017.5, U017.9, U017.12, U022.10 (GND); also elsewhere on the board
unnamed: U008.4, U009.2
unnamed: U008.6, U009.5
unnamed: U008.8, U009.10
unnamed: U008.10, U009.13
unnamed: U009.3, U010.1
unnamed: U009.6, U010.4
unnamed: U009.8, U010.10
unnamed: U009.11, U010.13
unnamed: U015.4, U016.2
unnamed: U015.6, U016.5
unnamed: U015.8, U016.10
unnamed: U015.10, U016.13
unnamed: U016.3, U017.1
unnamed: U016.6, U017.4
unnamed: U016.8, U017.10
unnamed: U016.11, U017.13
unnamed: U031.3, U031.4
VCC: RN1.1 (common), U004.20 (VCC), U022.20 (VCC); also elsewhere on the board
~EN0: U007.10, U031.1; also elsewhere on the board
~RES: U031.2; also elsewhere on the board

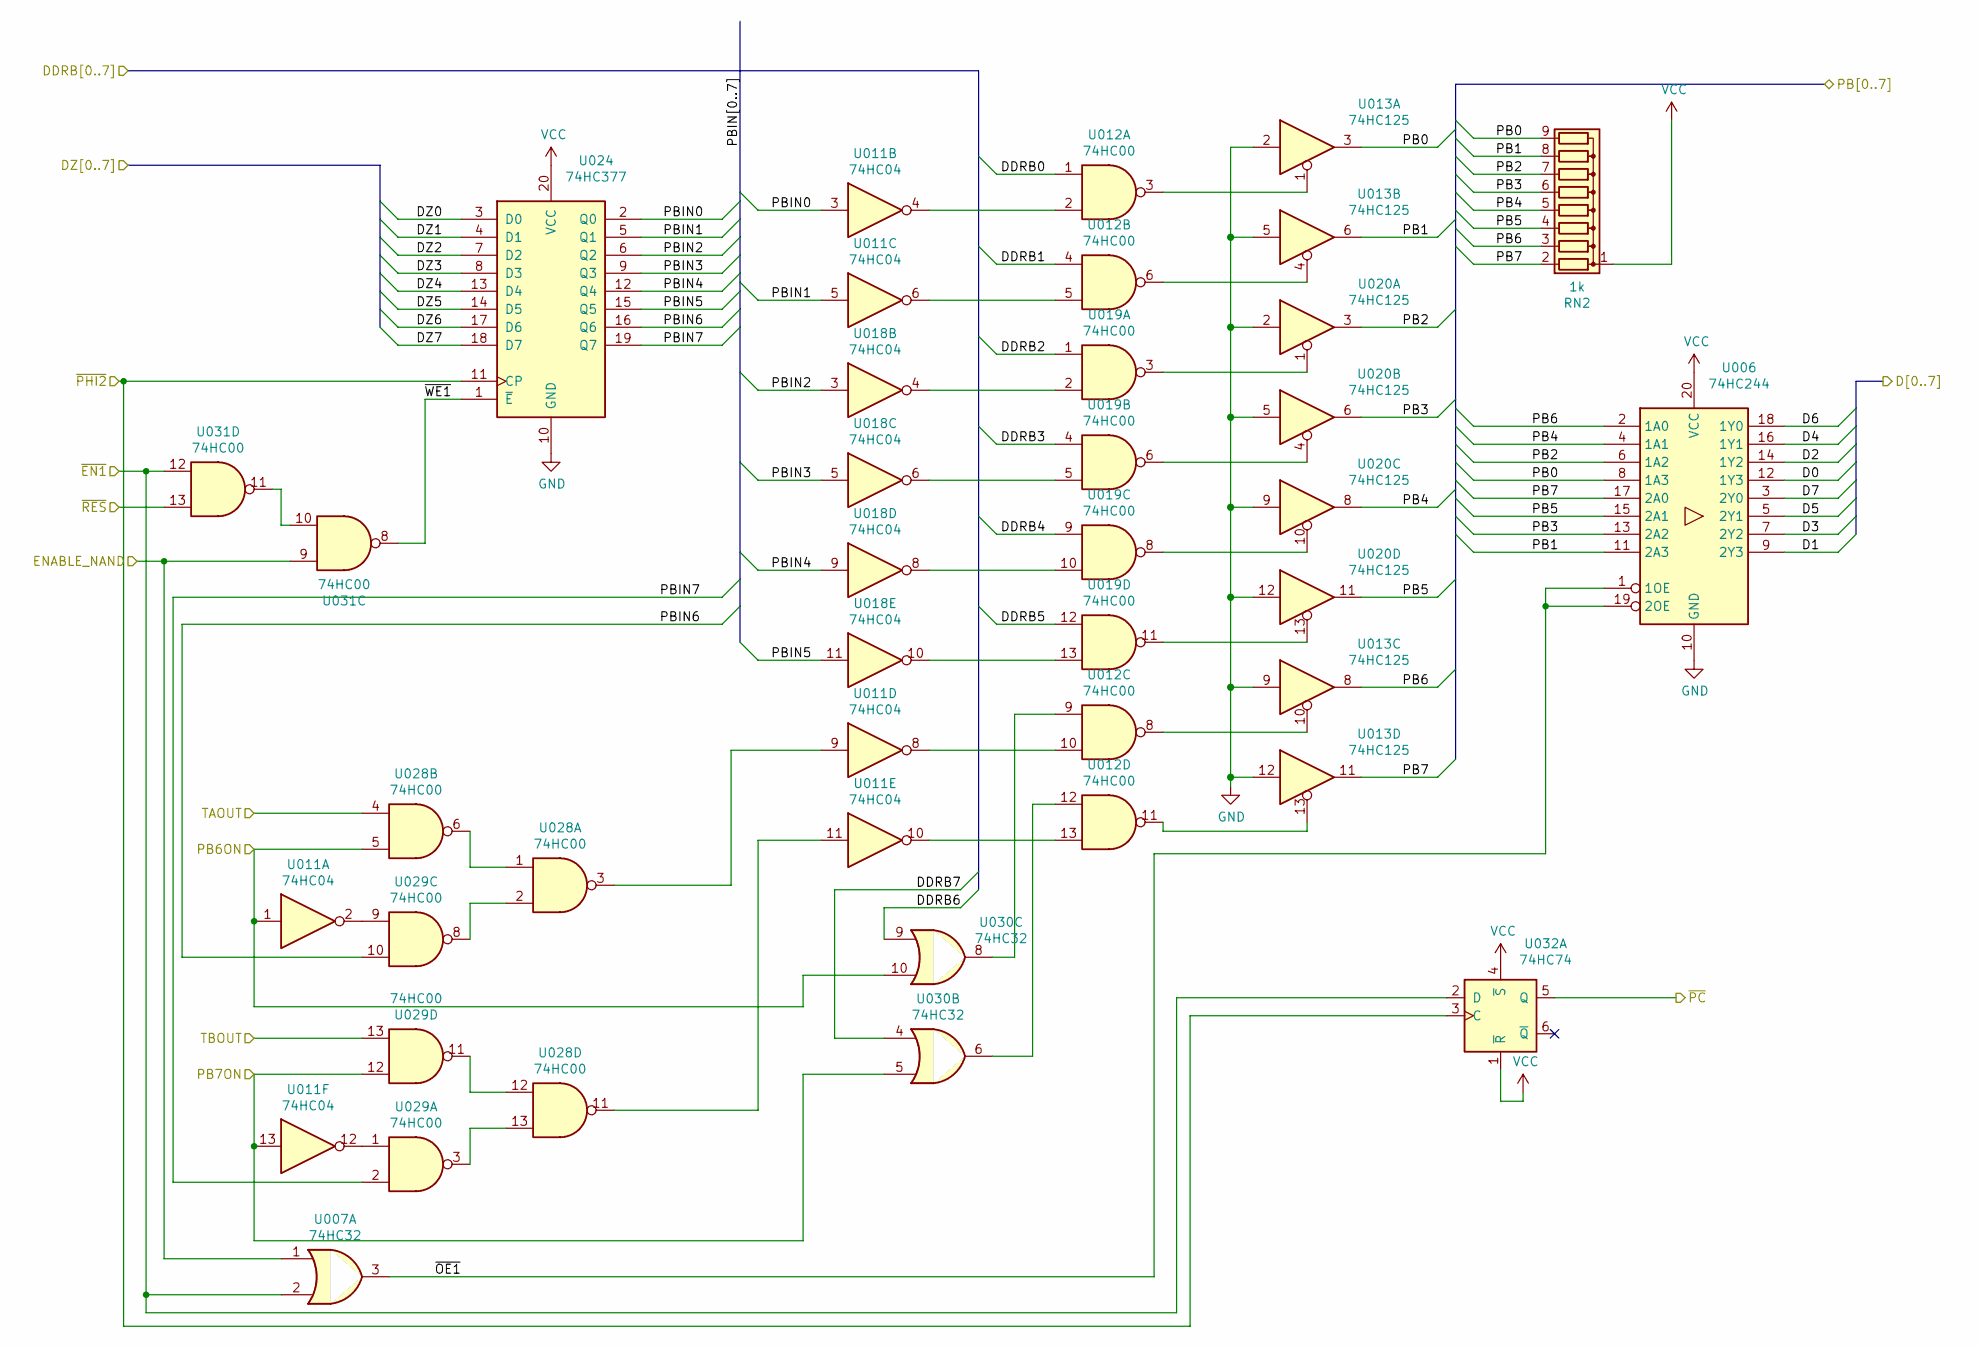
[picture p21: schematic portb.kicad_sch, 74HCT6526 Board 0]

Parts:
RN2: 1k; R_Array_SIP9
U006: 74HC244; SOIC-20W
U007, U030: 74HC32; SO-14
U011, U018: 74HC04; SO-14
U012, U019, U028, U029, U031: 74HC00; SO-14
U013, U020: 74HC125; SO-14
U024: 74HC377; SOIC-20W
U032: 74HC74; SO-14

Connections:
/ddrb/DDRB0: U012.1; also elsewhere on the board
/ddrb/DDRB1: U012.4; also elsewhere on the board
/ddrb/DDRB2: U019.1; also elsewhere on the board
/ddrb/DDRB3: U019.4; also elsewhere on the board
/ddrb/DDRB4: U019.9; also elsewhere on the board
/ddrb/DDRB5: U019.12; also elsewhere on the board
/ddrb/DDRB6: U030.9; also elsewhere on the board
/ddrb/DDRB7: U030.4; also elsewhere on the board
/icInterface/PB0: RN2.9 (R8), U006.8 (1A3), U013.3; also elsewhere on the board
/icInterface/PB1: RN2.8 (R7), U006.11 (2A3), U013.6; also elsewhere on the board
/icInterface/PB2: RN2.7 (R6), U006.6 (1A2), U020.3; also elsewhere on the board
/icInterface/PB3: RN2.6 (R5), U006.13 (2A2), U020.6; also elsewhere on the board
/icInterface/PB4: RN2.5 (R4), U006.4 (1A1), U020.8; also elsewhere on the board
/icInterface/PB5: RN2.4 (R3), U006.15 (2A1), U020.11; also elsewhere on the board
/icInterface/PB6: RN2.3 (R2), U006.2 (1A0), U013.8; also elsewhere on the board
/icInterface/PB7: RN2.2 (R1), U006.17 (2A0), U013.11; also elsewhere on the board
/icInterface/~PC: U032.5 (Q); also elsewhere on the board
/portb/PBIN0: U011.3, U024.2 (Q0)
/portb/PBIN1: U011.5, U024.5 (Q1)
/portb/PBIN2: U018.3, U024.6 (Q2)
/portb/PBIN3: U018.5, U024.9 (Q3)
/portb/PBIN4: U018.9, U024.12 (Q4)
/portb/PBIN5: U018.11, U024.15 (Q5)
/portb/PBIN6: U024.16 (Q6), U029.10
/portb/PBIN7: U024.19 (Q7), U029.2
/portb/~OE1: U006.1 (1OE), U006.19 (2OE), U007.3
/portb/~WE1: U024.1 (~E), U031.8
/~PHI2: U024.11 (CP), U032.3 (C); also elsewhere on the board
D0: U006.12 (1Y3); also elsewhere on the board
D1: U006.9 (2Y3); also elsewhere on the board
D2: U006.14 (1Y2); also elsewhere on the board
D3: U006.7 (2Y2); also elsewhere on the board
D4: U006.16 (1Y1); also elsewhere on the board
D5: U006.5 (2Y1); also elsewhere on the board
D6: U006.18 (1Y0); also elsewhere on the board
D7: U006.3 (2Y0); also elsewhere on the board
DZ0: U024.3 (D0); also elsewhere on the board
DZ1: U024.4 (D1); also elsewhere on the board
DZ2: U024.7 (D2); also elsewhere on the board
DZ3: U024.8 (D3); also elsewhere on the board
DZ4: U024.13 (D4); also elsewhere on the board
DZ5: U024.14 (D5); also elsewhere on the board
DZ6: U024.17 (D6); also elsewhere on the board
DZ7: U024.18 (D7); also elsewhere on the board
ENABLE_NAND: U007.1, U031.9; also elsewhere on the board
GND: U006.10 (GND), U013.2, U013.5, U013.9, U013.12, U020.2, U020.5, U020.9, U020.12, U024.10 (GND); also elsewhere on the board
unnamed: U011.2, U029.9
unnamed: U011.4, U012.2
unnamed: U011.6, U012.5
unnamed: U011.8, U012.10
unnamed: U011.9, U028.3
unnamed: U011.10, U012.13
unnamed: U011.11, U028.11
unnamed: U011.12, U029.1
unnamed: U012.3, U013.1
unnamed: U012.6, U013.4
unnamed: U012.8, U013.10
unnamed: U012.9, U030.8
unnamed: U012.11, U013.13
unnamed: U012.12, U030.6
unnamed: U018.4, U019.2
unnamed: U018.6, U019.5
unnamed: U018.8, U019.10
unnamed: U018.10, U019.13
unnamed: U019.3, U020.1
unnamed: U019.6, U020.4
unnamed: U019.8, U020.10
unnamed: U019.11, U020.13
unnamed: U028.1, U028.6
unnamed: U028.2, U029.8
unnamed: U028.12, U029.11
unnamed: U028.13, U029.3
unnamed: U031.10, U031.11
PB6ON: U011.1, U028.5, U030.10; also elsewhere on the board
PB7ON: U011.13, U029.12, U030.5; also elsewhere on the board
TAOUT: U028.4; also elsewhere on the board
TBOUT: U029.13; also elsewhere on the board
VCC: RN2.1 (common), U006.20 (VCC), U024.20 (VCC), U032.1 (~R), U032.4 (~S); also elsewhere on the board
~EN1: U007.2, U031.12, U032.2 (D); also elsewhere on the board
~RES: U031.13; also elsewhere on the board

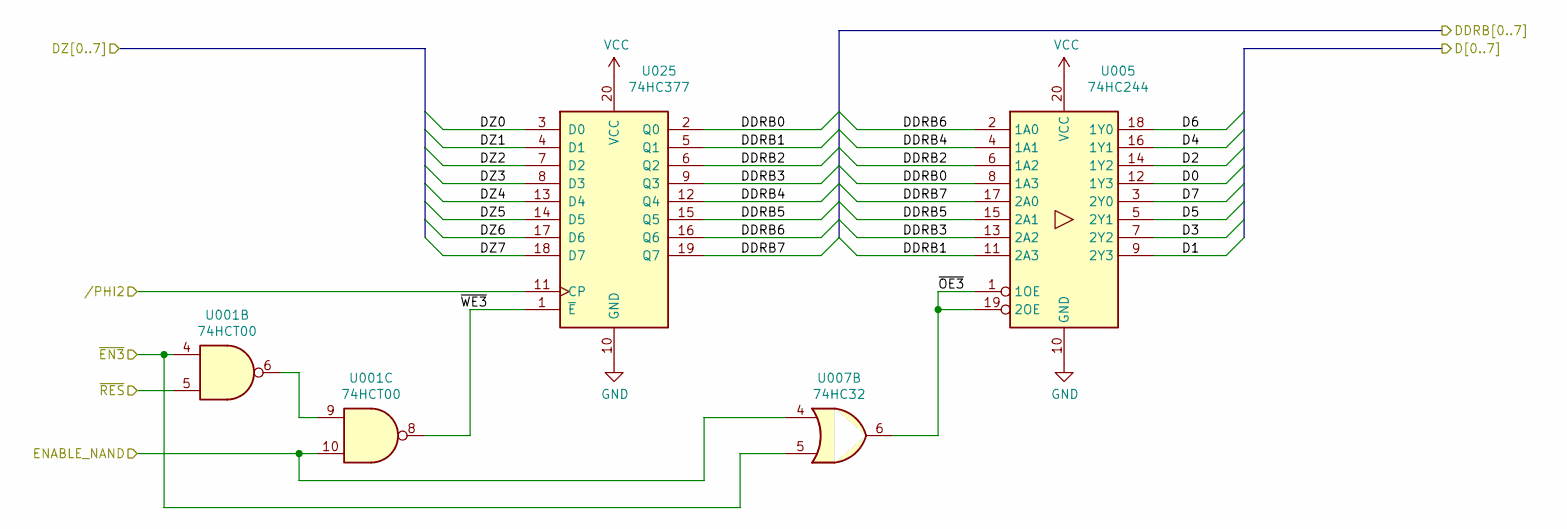
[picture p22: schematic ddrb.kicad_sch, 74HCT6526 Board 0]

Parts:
U001: 74HCT00; SO-14
U005: 74HC244; SOIC-20W
U007: 74HC32; SO-14
U025: 74HC377; SOIC-20W

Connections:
/ddrb/DDRB0: U005.8 (1A3), U025.2 (Q0); also elsewhere on the board
/ddrb/DDRB1: U005.11 (2A3), U025.5 (Q1); also elsewhere on the board
/ddrb/DDRB2: U005.6 (1A2), U025.6 (Q2); also elsewhere on the board
/ddrb/DDRB3: U005.13 (2A2), U025.9 (Q3); also elsewhere on the board
/ddrb/DDRB4: U005.4 (1A1), U025.12 (Q4); also elsewhere on the board
/ddrb/DDRB5: U005.15 (2A1), U025.15 (Q5); also elsewhere on the board
/ddrb/DDRB6: U005.2 (1A0), U025.16 (Q6); also elsewhere on the board
/ddrb/DDRB7: U005.17 (2A0), U025.19 (Q7); also elsewhere on the board
/ddrb/~OE3: U005.1 (1OE), U005.19 (2OE), U007.6
/ddrb/~WE3: U001.8, U025.1 (~E)
/~PHI2: U025.11 (CP); also elsewhere on the board
D0: U005.12 (1Y3); also elsewhere on the board
D1: U005.9 (2Y3); also elsewhere on the board
D2: U005.14 (1Y2); also elsewhere on the board
D3: U005.7 (2Y2); also elsewhere on the board
D4: U005.16 (1Y1); also elsewhere on the board
D5: U005.5 (2Y1); also elsewhere on the board
D6: U005.18 (1Y0); also elsewhere on the board
D7: U005.3 (2Y0); also elsewhere on the board
DZ0: U025.3 (D0); also elsewhere on the board
DZ1: U025.4 (D1); also elsewhere on the board
DZ2: U025.7 (D2); also elsewhere on the board
DZ3: U025.8 (D3); also elsewhere on the board
DZ4: U025.13 (D4); also elsewhere on the board
DZ5: U025.14 (D5); also elsewhere on the board
DZ6: U025.17 (D6); also elsewhere on the board
DZ7: U025.18 (D7); also elsewhere on the board
ENABLE_NAND: U001.10, U007.4; also elsewhere on the board
GND: U005.10 (GND), U025.10 (GND); also elsewhere on the board
unnamed: U001.6, U001.9
VCC: U005.20 (VCC), U025.20 (VCC); also elsewhere on the board
~EN3: U001.4, U007.5; also elsewhere on the board
~RES: U001.5; also elsewhere on the board

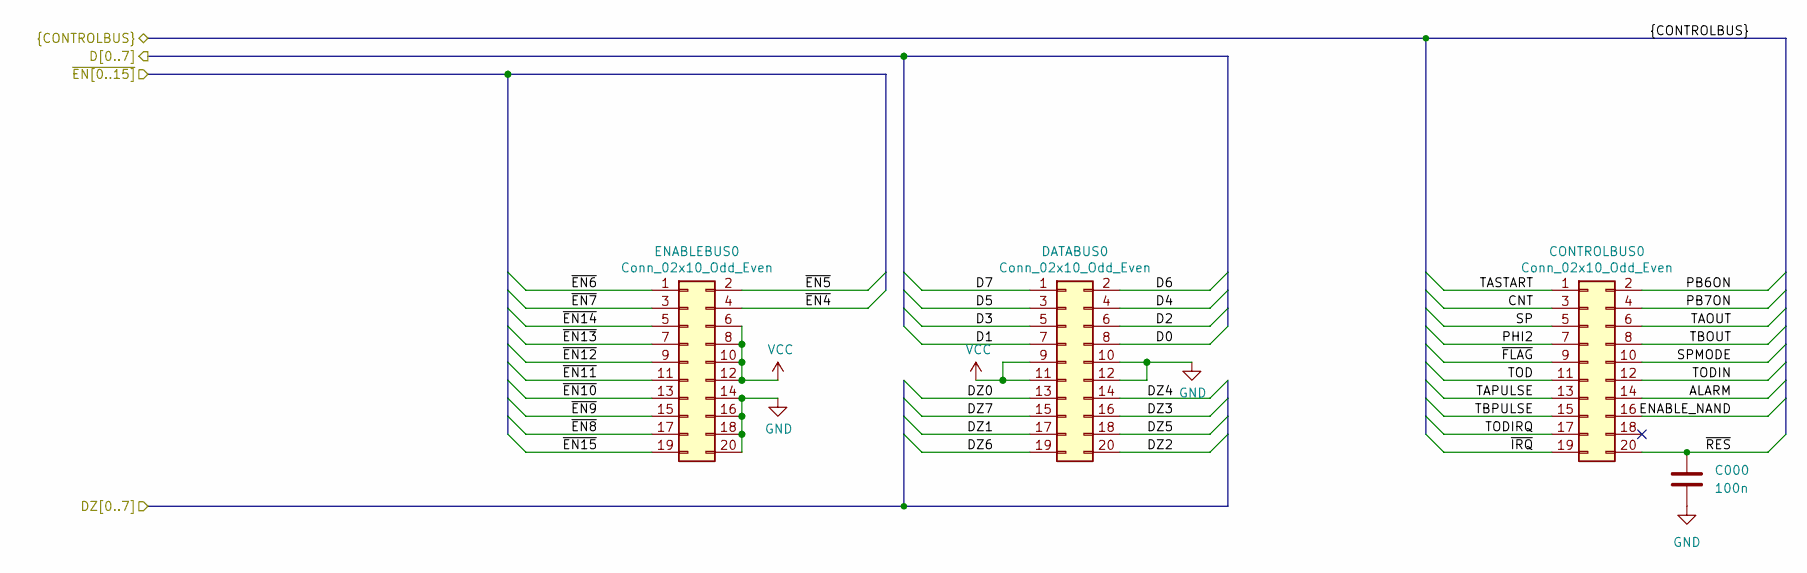
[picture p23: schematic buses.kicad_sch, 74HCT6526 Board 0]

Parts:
C000: 100n; C_0603_1608Metric
CONTROLBUS0: Conn_02x10_Odd_Even; PinHeader_2x10_P2.54mm_Vertical
DATABUS0: Conn_02x10_Odd_Even; PinHeader_2x10_P2.54mm_Vertical
ENABLEBUS0: Conn_02x10_Odd_Even; PinHeader_2x10_P2.54mm_Vertical

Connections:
ALARM: CONTROLBUS0.14
CNT: CONTROLBUS0.3; also elsewhere on the board
D0: DATABUS0.8; also elsewhere on the board
D1: DATABUS0.7; also elsewhere on the board
D2: DATABUS0.6; also elsewhere on the board
D3: DATABUS0.5; also elsewhere on the board
D4: DATABUS0.4; also elsewhere on the board
D5: DATABUS0.3; also elsewhere on the board
D6: DATABUS0.2; also elsewhere on the board
D7: DATABUS0.1; also elsewhere on the board
DZ0: DATABUS0.13; also elsewhere on the board
DZ1: DATABUS0.17; also elsewhere on the board
DZ2: DATABUS0.20; also elsewhere on the board
DZ3: DATABUS0.16; also elsewhere on the board
DZ4: DATABUS0.14; also elsewhere on the board
DZ5: DATABUS0.18; also elsewhere on the board
DZ6: DATABUS0.19; also elsewhere on the board
DZ7: DATABUS0.15; also elsewhere on the board
ENABLE_NAND: CONTROLBUS0.16; also elsewhere on the board
GND: C000.2, DATABUS0.10, DATABUS0.12, ENABLEBUS0.14, ENABLEBUS0.16, ENABLEBUS0.18, ENABLEBUS0.20; also elsewhere on the board
PB6ON: CONTROLBUS0.2; also elsewhere on the board
PB7ON: CONTROLBUS0.4; also elsewhere on the board
PHI2: CONTROLBUS0.7; also elsewhere on the board
SP: CONTROLBUS0.5; also elsewhere on the board
SPMODE: CONTROLBUS0.10
TAOUT: CONTROLBUS0.6; also elsewhere on the board
TAPULSE: CONTROLBUS0.13
TASTART: CONTROLBUS0.1
TBOUT: CONTROLBUS0.8; also elsewhere on the board
TBPULSE: CONTROLBUS0.15
TOD: CONTROLBUS0.11; also elsewhere on the board
TODIN: CONTROLBUS0.12
TODIRQ: CONTROLBUS0.17
VCC: DATABUS0.9, DATABUS0.11, ENABLEBUS0.6, ENABLEBUS0.8, ENABLEBUS0.10, ENABLEBUS0.12; also elsewhere on the board
~EN4: ENABLEBUS0.4; also elsewhere on the board
~EN5: ENABLEBUS0.2; also elsewhere on the board
~EN6: ENABLEBUS0.1; also elsewhere on the board
~EN7: ENABLEBUS0.3; also elsewhere on the board
~EN8: ENABLEBUS0.17; also elsewhere on the board
~EN9: ENABLEBUS0.15; also elsewhere on the board
~EN10: ENABLEBUS0.13; also elsewhere on the board
~EN11: ENABLEBUS0.11; also elsewhere on the board
~EN12: ENABLEBUS0.9; also elsewhere on the board
~EN13: ENABLEBUS0.7; also elsewhere on the board
~EN14: ENABLEBUS0.5; also elsewhere on the board
~EN15: ENABLEBUS0.19; also elsewhere on the board
~FLAG: CONTROLBUS0.9; also elsewhere on the board
~IRQ: CONTROLBUS0.19; also elsewhere on the board
~RES: C000.1, CONTROLBUS0.20; also elsewhere on the board

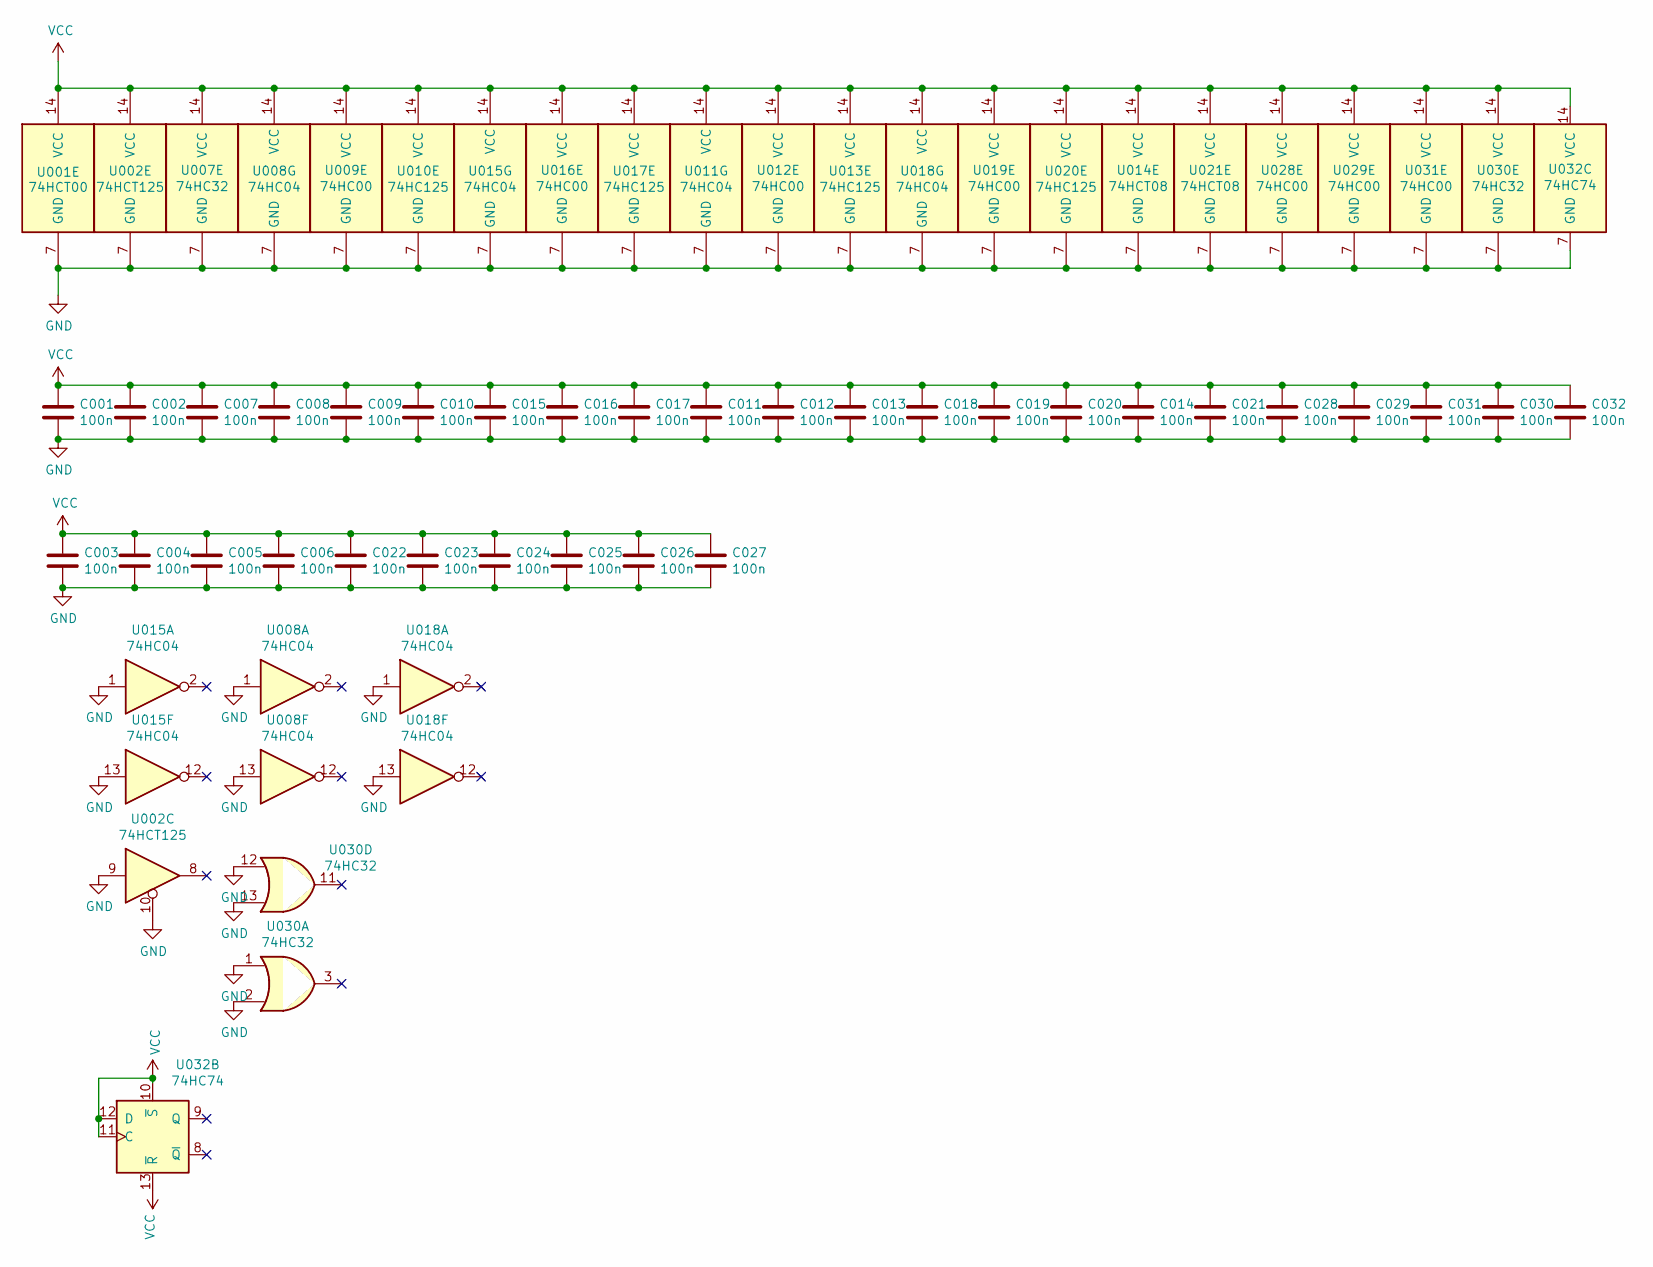
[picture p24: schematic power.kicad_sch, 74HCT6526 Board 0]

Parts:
C001, C002, C003, C004, C005, C006, C007, C008, C009, C010, C011, C012, C013, C014, C015, C016, C017, C018, C019, C020, C021, C022, C023, C024, C025, C026, C027, C028, C029, C030, C031, C032: 100n; 0603_SMD
U001: 74HCT00; SO-14
U002: 74HCT125; SO-14
U007, U030: 74HC32; SO-14
U008, U011, U015, U018: 74HC04; SO-14
U009, U012, U016, U019, U028, U029, U031: 74HC00; SO-14
U010, U013, U017, U020: 74HC125; SO-14
U014, U021: 74HCT08; SO-14
U032: 74HC74; SO-14

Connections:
GND: C001.2, C002.2, C003.2, C004.2, C005.2, C006.2, C007.2, C008.2, C009.2, C010.2, C011.2, C012.2, C013.2, C014.2, C015.2, C016.2, C017.2, C018.2, C019.2, C020.2, C021.2, C022.2, C023.2, C024.2, C025.2, C026.2, C027.2, C028.2, C029.2, C030.2, C031.2, C032.2, U001.7 (GND), U002.7 (GND), U002.9, U002.10, U007.7 (GND), U008.1, U008.7 (GND), U008.13, U009.7 (GND), U010.7 (GND), U011.7 (GND), U012.7 (GND), U013.7 (GND), U014.7 (GND), U015.1, U015.7 (GND), U015.13, U016.7 (GND), U017.7 (GND), U018.1, U018.7 (GND), U018.13, U019.7 (GND), U020.7 (GND), U021.7 (GND), U028.7 (GND), U029.7 (GND), U030.1, U030.2, U030.7 (GND), U030.12, U030.13, U031.7 (GND), U032.7 (GND); also elsewhere on the board
VCC: C001.1, C002.1, C003.1, C004.1, C005.1, C006.1, C007.1, C008.1, C009.1, C010.1, C011.1, C012.1, C013.1, C014.1, C015.1, C016.1, C017.1, C018.1, C019.1, C020.1, C021.1, C022.1, C023.1, C024.1, C025.1, C026.1, C027.1, C028.1, C029.1, C030.1, C031.1, C032.1, U001.14 (VCC), U002.14 (VCC), U007.14 (VCC), U008.14 (VCC), U009.14 (VCC), U010.14 (VCC), U011.14 (VCC), U012.14 (VCC), U013.14 (VCC), U014.14 (VCC), U015.14 (VCC), U016.14 (VCC), U017.14 (VCC), U018.14 (VCC), U019.14 (VCC), U020.14 (VCC), U021.14 (VCC), U028.14 (VCC), U029.14 (VCC), U030.14 (VCC), U031.14 (VCC), U032.10 (~S), U032.11 (C), U032.12 (D), U032.13 (~R), U032.14 (VCC); also elsewhere on the board

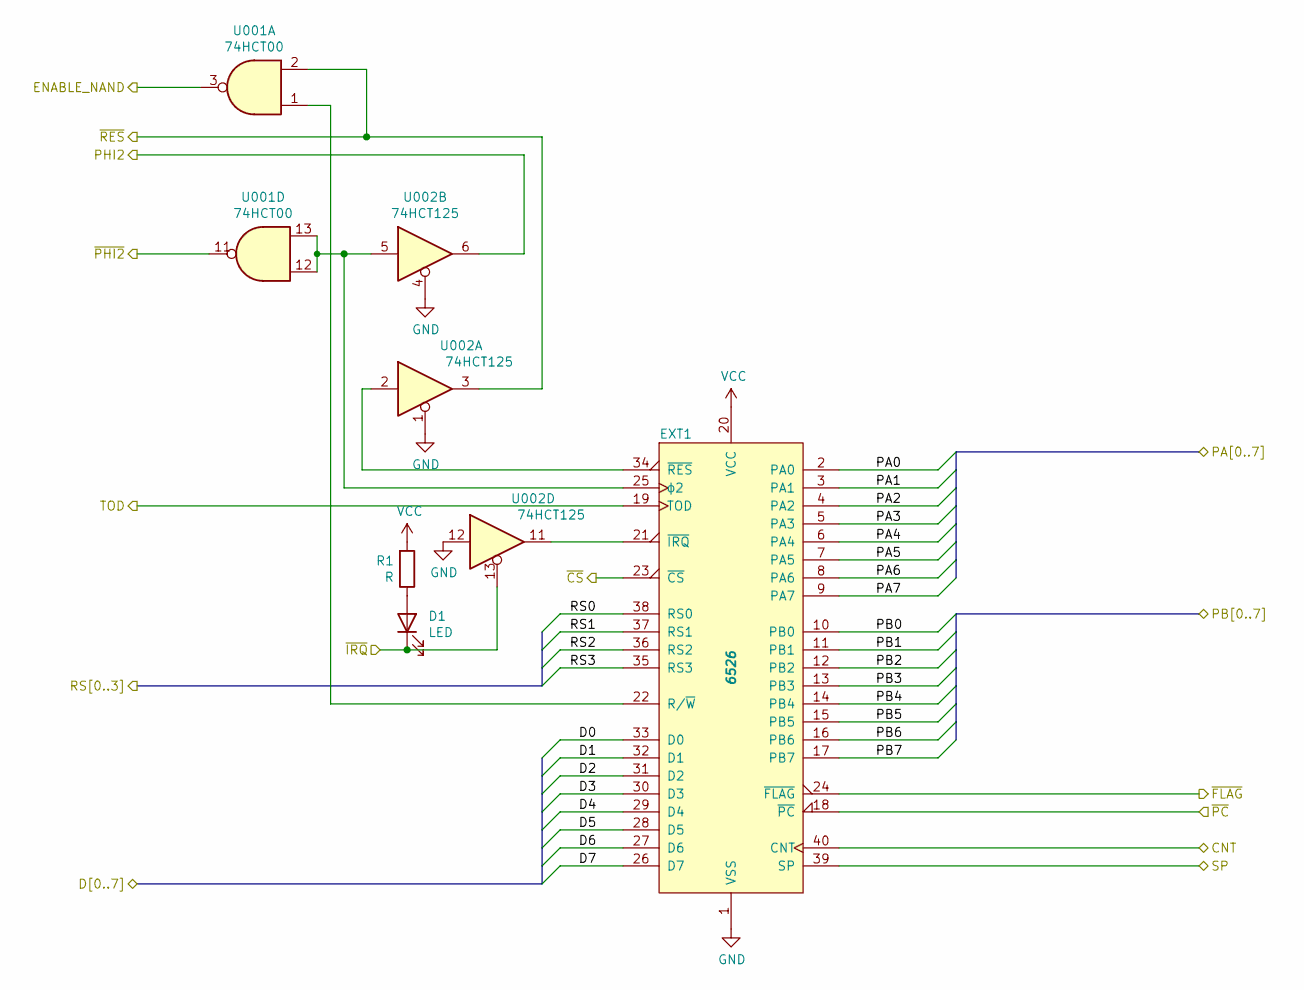
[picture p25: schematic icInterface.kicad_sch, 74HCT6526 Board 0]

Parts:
D1: LED; LED_0805_2012Metric
EXT1: 6526; IC Interface 2x20
R1: R; R_0805_2012Metric
U001: 74HCT00; SO-14
U002: 74HCT125; SO-14

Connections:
/icInterface/PA0: EXT1.2 (PA0); also elsewhere on the board
/icInterface/PA1: EXT1.3 (PA1); also elsewhere on the board
/icInterface/PA2: EXT1.4 (PA2); also elsewhere on the board
/icInterface/PA3: EXT1.5 (PA3); also elsewhere on the board
/icInterface/PA4: EXT1.6 (PA4); also elsewhere on the board
/icInterface/PA5: EXT1.7 (PA5); also elsewhere on the board
/icInterface/PA6: EXT1.8 (PA6); also elsewhere on the board
/icInterface/PA7: EXT1.9 (PA7); also elsewhere on the board
/icInterface/PB0: EXT1.10 (PB0); also elsewhere on the board
/icInterface/PB1: EXT1.11 (PB1); also elsewhere on the board
/icInterface/PB2: EXT1.12 (PB2); also elsewhere on the board
/icInterface/PB3: EXT1.13 (PB3); also elsewhere on the board
/icInterface/PB4: EXT1.14 (PB4); also elsewhere on the board
/icInterface/PB5: EXT1.15 (PB5); also elsewhere on the board
/icInterface/PB6: EXT1.16 (PB6); also elsewhere on the board
/icInterface/PB7: EXT1.17 (PB7); also elsewhere on the board
/icInterface/RS0: EXT1.38 (RS0); also elsewhere on the board
/icInterface/RS1: EXT1.37 (RS1); also elsewhere on the board
/icInterface/RS2: EXT1.36 (RS2); also elsewhere on the board
/icInterface/RS3: EXT1.35 (RS3); also elsewhere on the board
/icInterface/~CS: EXT1.23 (~CS); also elsewhere on the board
/icInterface/~PC: EXT1.18 (~PC); also elsewhere on the board
/~PHI2: U001.11; also elsewhere on the board
CNT: EXT1.40 (CNT); also elsewhere on the board
D0: EXT1.33 (D0); also elsewhere on the board
D1: EXT1.32 (D1); also elsewhere on the board
D2: EXT1.31 (D2); also elsewhere on the board
D3: EXT1.30 (D3); also elsewhere on the board
D4: EXT1.29 (D4); also elsewhere on the board
D5: EXT1.28 (D5); also elsewhere on the board
D6: EXT1.27 (D6); also elsewhere on the board
D7: EXT1.26 (D7); also elsewhere on the board
ENABLE_NAND: U001.3; also elsewhere on the board
GND: EXT1.1 (VSS), U002.1, U002.4, U002.12; also elsewhere on the board
unnamed: D1.2 (A), R1.1
unnamed: EXT1.21 (~IRQ), U002.11
unnamed: EXT1.22 (R/~W), U001.1
unnamed: EXT1.25 (ϕ2), U001.12, U001.13, U002.5
unnamed: EXT1.34 (~RES), U002.2
PHI2: U002.6; also elsewhere on the board
SP: EXT1.39 (SP); also elsewhere on the board
TOD: EXT1.19 (TOD); also elsewhere on the board
VCC: EXT1.20 (VCC), R1.2; also elsewhere on the board
~FLAG: EXT1.24 (~FLAG); also elsewhere on the board
~IRQ: D1.1 (K), U002.13; also elsewhere on the board
~RES: U001.2, U002.3; also elsewhere on the board

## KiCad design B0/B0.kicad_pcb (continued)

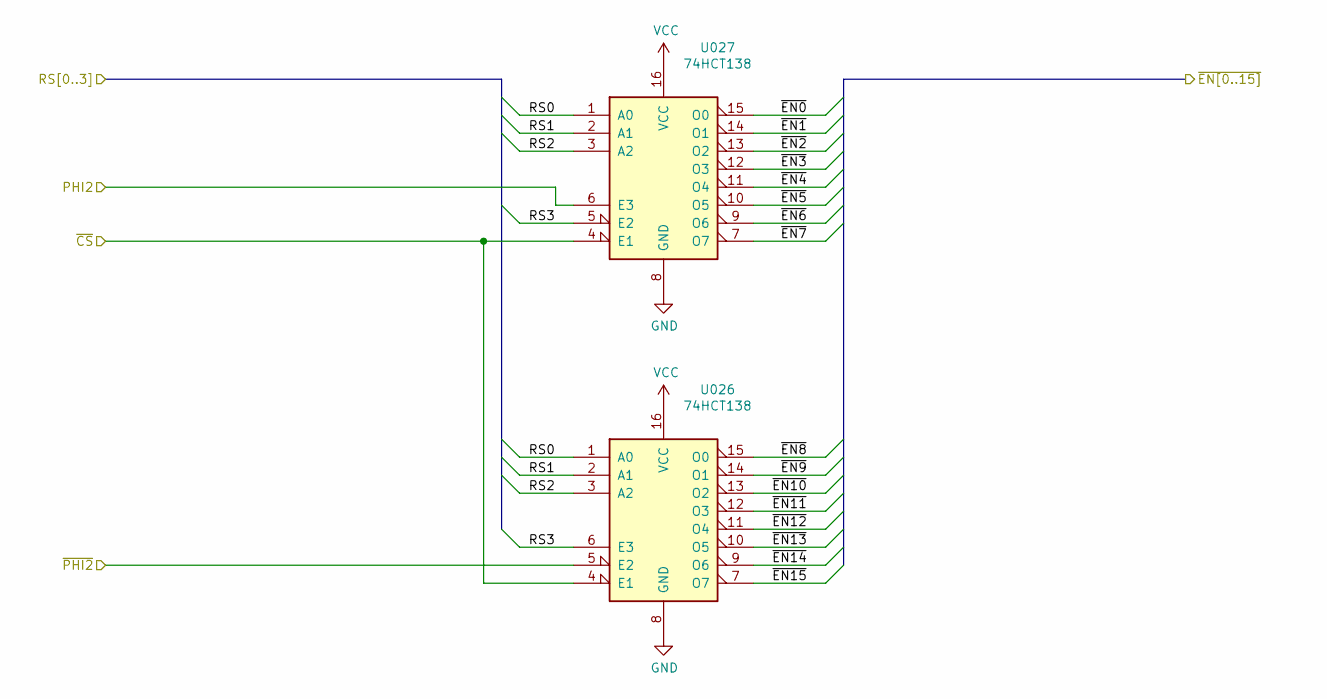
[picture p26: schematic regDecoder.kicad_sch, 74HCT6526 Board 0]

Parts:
U026, U027: 74HCT138; SO-16

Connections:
/icInterface/RS0: U026.1 (A0), U027.1 (A0); also elsewhere on the board
/icInterface/RS1: U026.2 (A1), U027.2 (A1); also elsewhere on the board
/icInterface/RS2: U026.3 (A2), U027.3 (A2); also elsewhere on the board
/icInterface/RS3: U026.6 (E3), U027.5 (E2); also elsewhere on the board
/icInterface/~CS: U026.4 (E1), U027.4 (E1); also elsewhere on the board
/~PHI2: U026.5 (E2); also elsewhere on the board
GND: U026.8 (GND), U027.8 (GND); also elsewhere on the board
PHI2: U027.6 (E3); also elsewhere on the board
VCC: U026.16 (VCC), U027.16 (VCC); also elsewhere on the board
~EN0: U027.15 (O0); also elsewhere on the board
~EN1: U027.14 (O1); also elsewhere on the board
~EN2: U027.13 (O2); also elsewhere on the board
~EN3: U027.12 (O3); also elsewhere on the board
~EN4: U027.11 (O4); also elsewhere on the board
~EN5: U027.10 (O5); also elsewhere on the board
~EN6: U027.9 (O6); also elsewhere on the board
~EN7: U027.7 (O7); also elsewhere on the board
~EN8: U026.15 (O0); also elsewhere on the board
~EN9: U026.14 (O1); also elsewhere on the board
~EN10: U026.13 (O2); also elsewhere on the board
~EN11: U026.12 (O3); also elsewhere on the board
~EN12: U026.11 (O4); also elsewhere on the board
~EN13: U026.10 (O5); also elsewhere on the board
~EN14: U026.9 (O6); also elsewhere on the board
~EN15: U026.7 (O7); also elsewhere on the board

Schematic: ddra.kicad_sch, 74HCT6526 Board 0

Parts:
U003: 74HC244; SOIC-20W
U007: 74HC32; SO-14
U023: 74HC377; SOIC-20W
U028, U029: 74HC00; SO-14

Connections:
/ddra/DDRA0: U003.8 (1A3), U023.2 (Q0); also elsewhere on the board
/ddra/DDRA1: U003.11 (2A3), U023.5 (Q1); also elsewhere on the board
/ddra/DDRA2: U003.6 (1A2), U023.6 (Q2); also elsewhere on the board
/ddra/DDRA3: U003.13 (2A2), U023.9 (Q3); also elsewhere on the board
/ddra/DDRA4: U003.4 (1A1), U023.12 (Q4); also elsewhere on the board
/ddra/DDRA5: U003.15 (2A1), U023.15 (Q5); also elsewhere on the board
/ddra/DDRA6: U003.2 (1A0), U023.16 (Q6); also elsewhere on the board
/ddra/DDRA7: U003.17 (2A0), U023.19 (Q7); also elsewhere on the board
/ddra/~OE2: U003.1 (1OE), U003.19 (2OE), U007.11
/ddra/~WE2: U023.1 (~E), U029.6
/~PHI2: U023.11 (CP); also elsewhere on the board
D0: U003.12 (1Y3); also elsewhere on the board
D1: U003.9 (2Y3); also elsewhere on the board
D2: U003.14 (1Y2); also elsewhere on the board
D3: U003.7 (2Y2); also elsewhere on the board
D4: U003.16 (1Y1); also elsewhere on the board
D5: U003.5 (2Y1); also elsewhere on the board
D6: U003.18 (1Y0); also elsewhere on the board
D7: U003.3 (2Y0); also elsewhere on the board
DZ0: U023.3 (D0); also elsewhere on the board
DZ1: U023.4 (D1); also elsewhere on the board
DZ2: U023.7 (D2); also elsewhere on the board
DZ3: U023.8 (D3); also elsewhere on the board
DZ4: U023.13 (D4); also elsewhere on the board
DZ5: U023.14 (D5); also elsewhere on the board
DZ6: U023.17 (D6); also elsewhere on the board
DZ7: U023.18 (D7); also elsewhere on the board
ENABLE_NAND: U007.12, U029.4; also elsewhere on the board
GND: U003.10 (GND), U023.10 (GND); also elsewhere on the board
unnamed: U028.8, U029.5
VCC: U003.20 (VCC), U023.20 (VCC); also elsewhere on the board
~EN2: U007.13, U028.10; also elsewhere on the board
~RES: U028.9; also elsewhere on the board

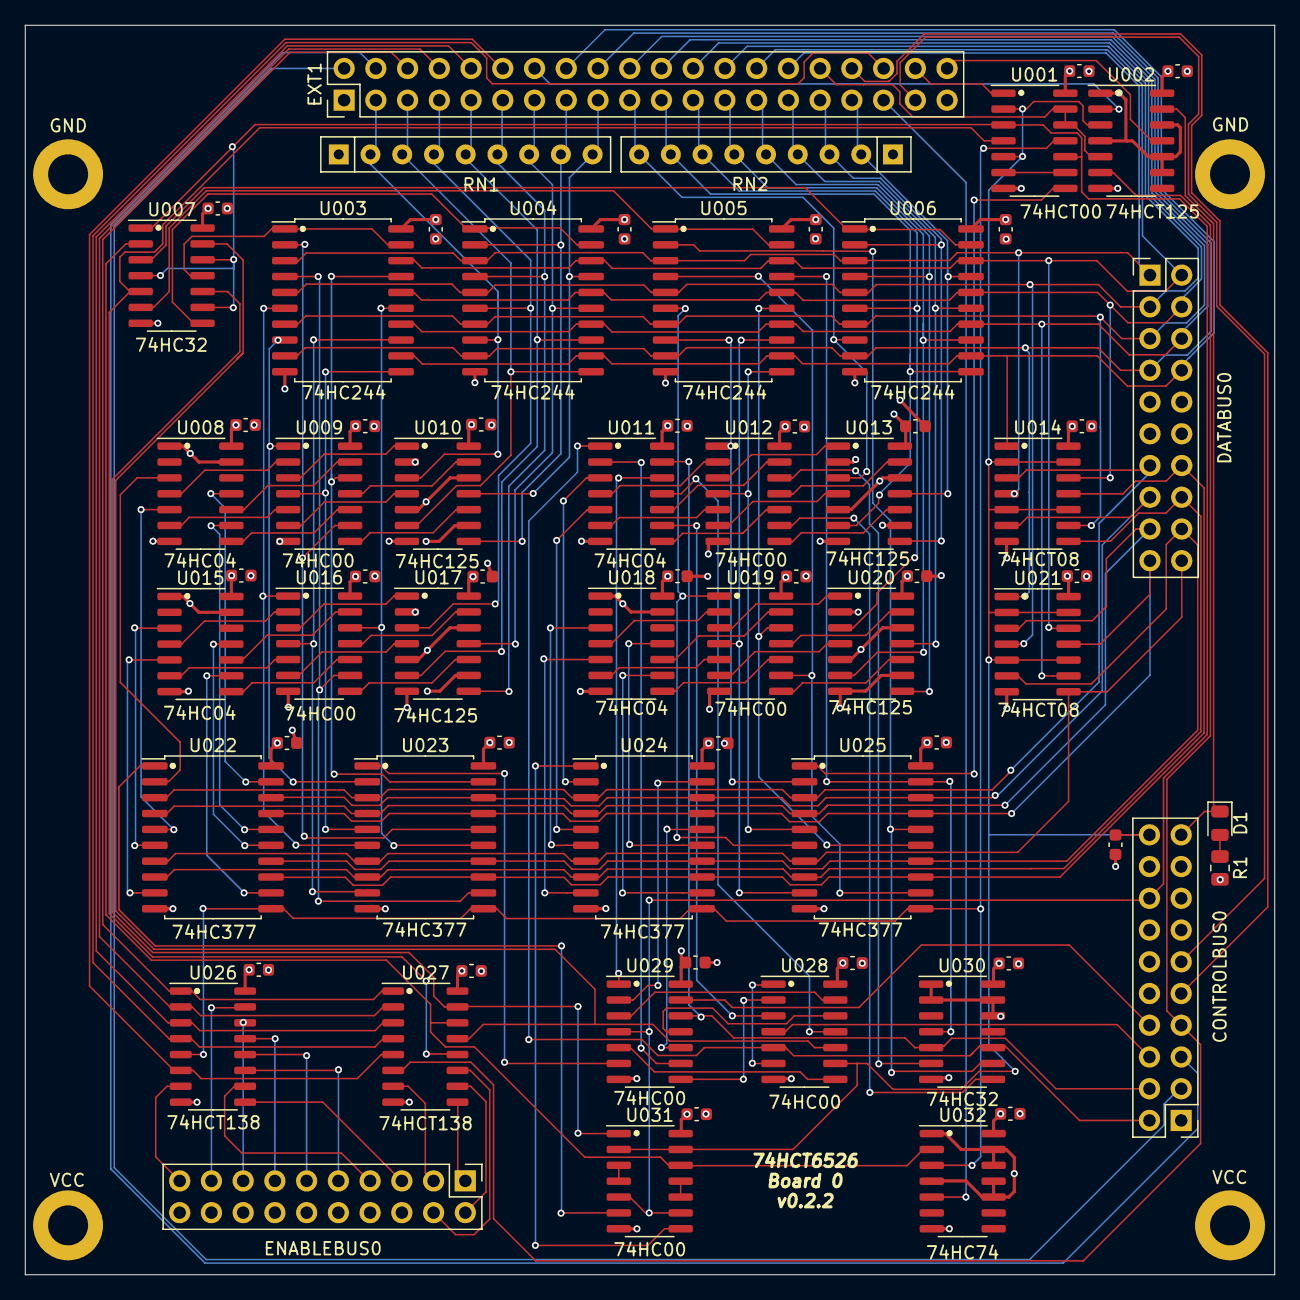
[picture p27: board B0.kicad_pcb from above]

Board: 4 copper layers, 100.0 x 100.0 mm, 77 parts (0 on the bottom side), 160 nets.

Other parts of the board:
GND1, GND2: GND; MountingHole_2.2mm_M2_DIN965_Pad
VCC1, VCC2: VCC; MountingHole_2.2mm_M2_DIN965_Pad

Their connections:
GND: GND1.GND, GND2.GND; also elsewhere on the board
VCC: VCC1.VCC, VCC2.VCC2; also elsewhere on the board

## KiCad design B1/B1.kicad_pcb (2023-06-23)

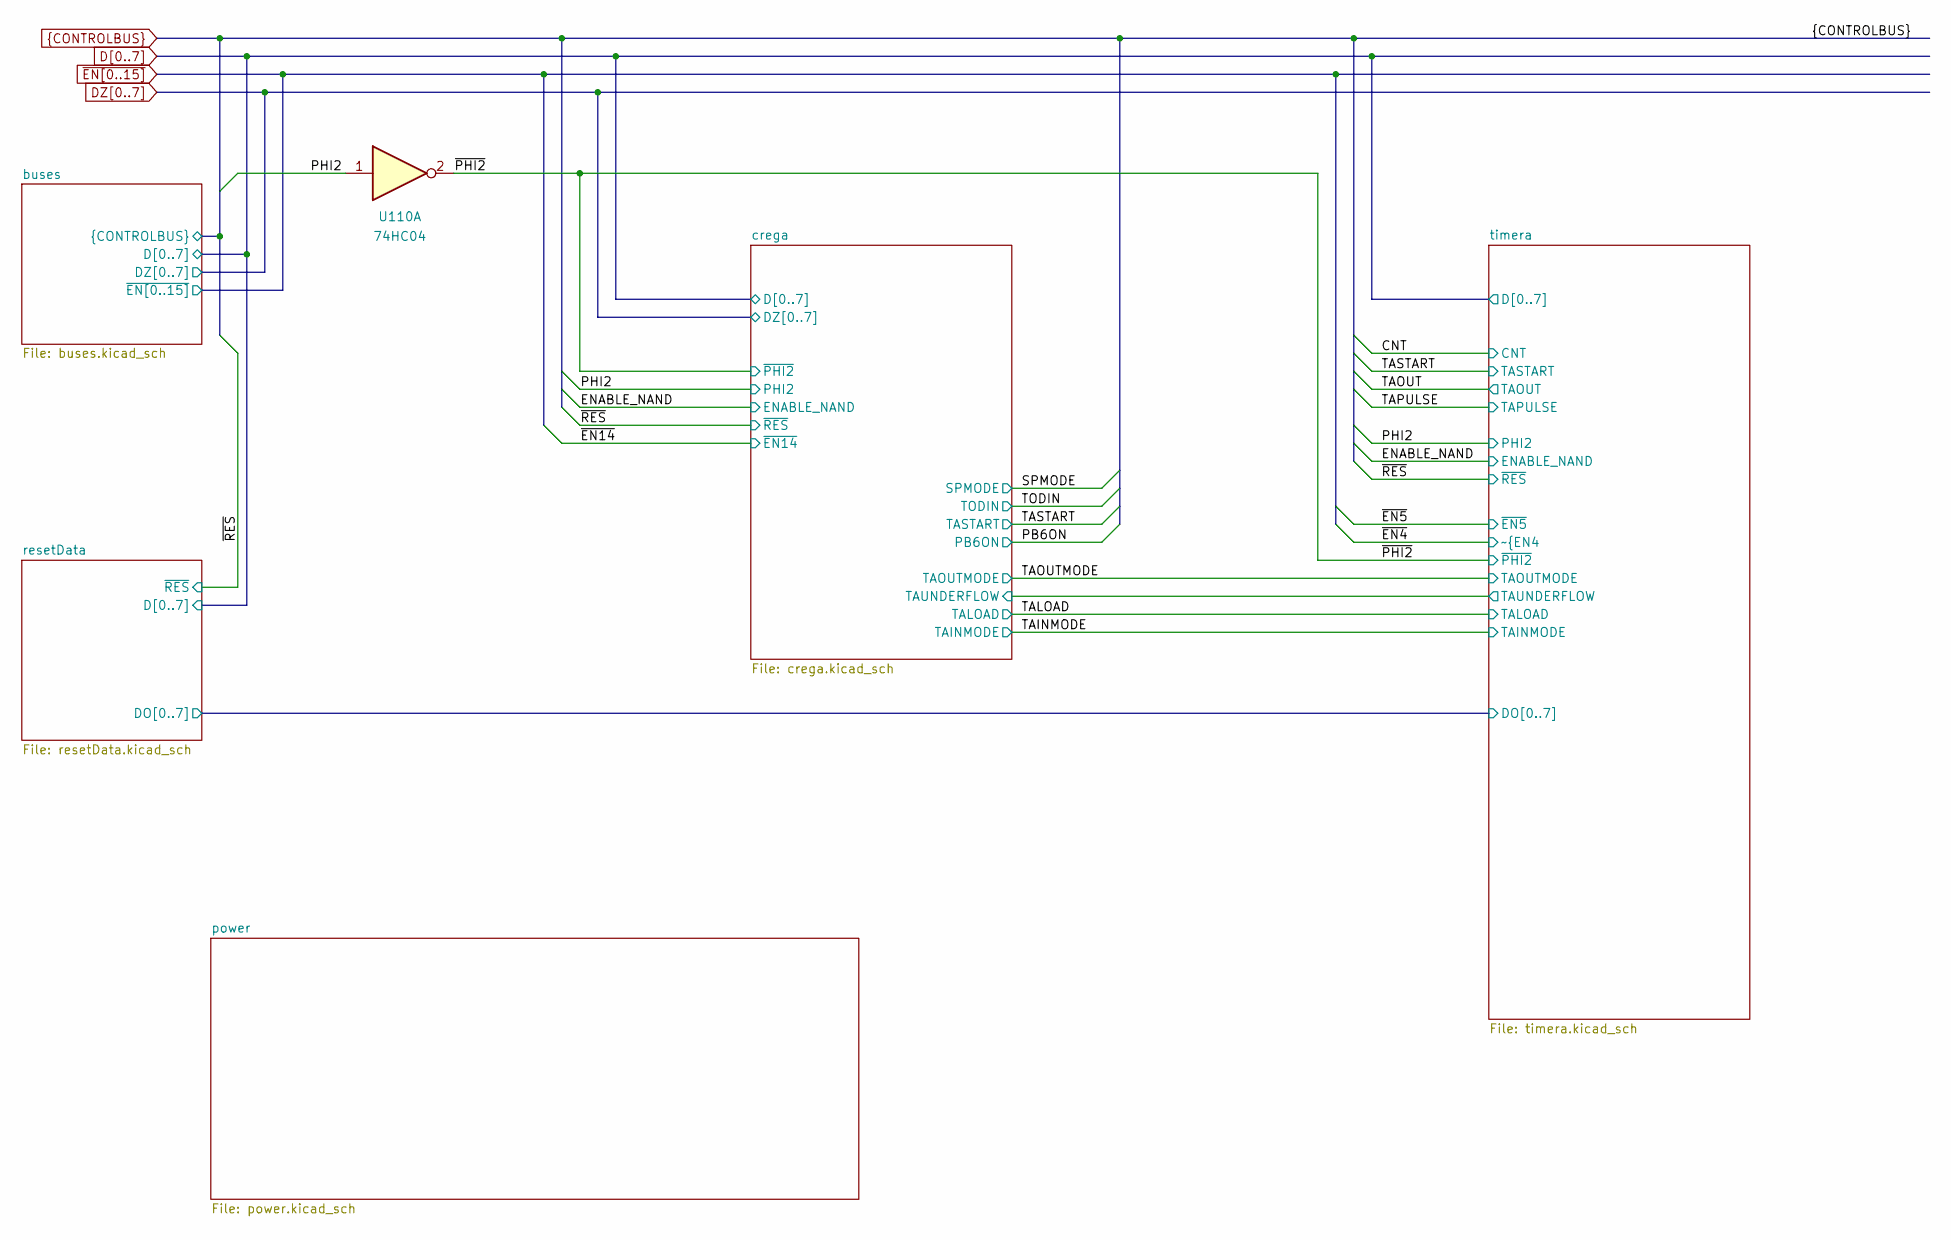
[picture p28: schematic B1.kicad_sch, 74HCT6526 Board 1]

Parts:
U110: 74HC04; SOIC-14_3.9x8.7mm_P1.27mm

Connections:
/~PHI2: U110.2; also elsewhere on the board
PHI2: U110.1; also elsewhere on the board

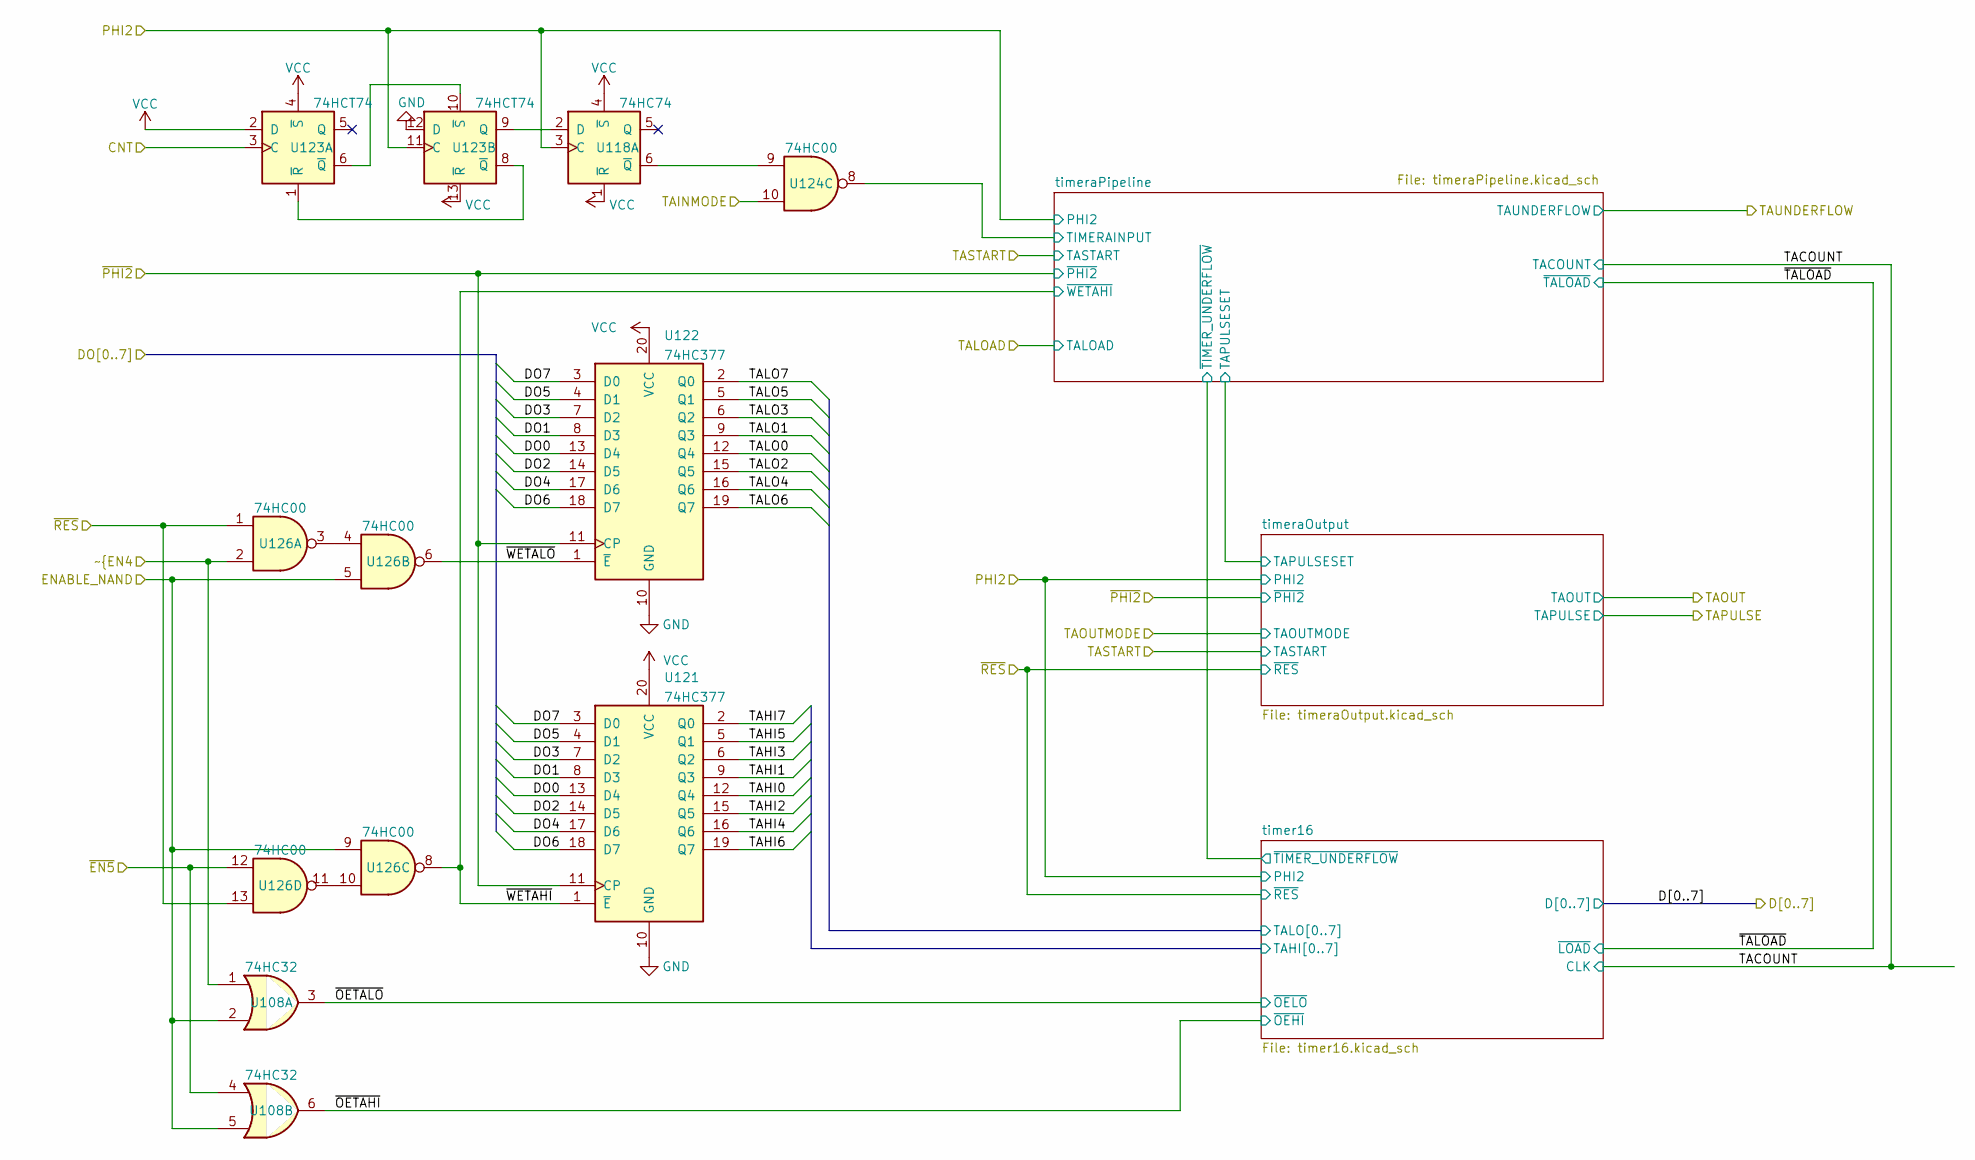
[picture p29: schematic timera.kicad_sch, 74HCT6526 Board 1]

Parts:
U108: 74HC32; SOIC-14_3.9x8.7mm_P1.27mm
U118: 74HC74; SO-14_3.9x8.65mm_P1.27mm
U121, U122: 74HC377; SOIC-20W_7.5x12.8mm_P1.27mm
U123: 74HCT74; SO-14_3.9x8.65mm_P1.27mm
U124: 74HC00; SOIC-14_3.9x8.7mm_P1.27mm
U126: 74HC00; SO-14_3.9x8.65mm_P1.27mm

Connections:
/TAINMODE: U124.10; also elsewhere on the board
/resetData/DO0: U121.13 (D4), U122.13 (D4); also elsewhere on the board
/resetData/DO1: U121.8 (D3), U122.8 (D3); also elsewhere on the board
/resetData/DO2: U121.14 (D5), U122.14 (D5); also elsewhere on the board
/resetData/DO3: U121.7 (D2), U122.7 (D2); also elsewhere on the board
/resetData/DO4: U121.17 (D6), U122.17 (D6); also elsewhere on the board
/resetData/DO5: U121.4 (D1), U122.4 (D1); also elsewhere on the board
/resetData/DO6: U121.18 (D7), U122.18 (D7); also elsewhere on the board
/resetData/DO7: U121.3 (D0), U122.3 (D0); also elsewhere on the board
/timera/timer16/TAHI0: U121.12 (Q4); also elsewhere on the board
/timera/timer16/TAHI1: U121.9 (Q3); also elsewhere on the board
/timera/timer16/TAHI2: U121.15 (Q5); also elsewhere on the board
/timera/timer16/TAHI3: U121.6 (Q2); also elsewhere on the board
/timera/timer16/TAHI4: U121.16 (Q6); also elsewhere on the board
/timera/timer16/TAHI5: U121.5 (Q1); also elsewhere on the board
/timera/timer16/TAHI6: U121.19 (Q7); also elsewhere on the board
/timera/timer16/TAHI7: U121.2 (Q0); also elsewhere on the board
/timera/timer16/TALO0: U122.12 (Q4); also elsewhere on the board
/timera/timer16/TALO1: U122.9 (Q3); also elsewhere on the board
/timera/timer16/TALO2: U122.15 (Q5); also elsewhere on the board
/timera/timer16/TALO3: U122.6 (Q2); also elsewhere on the board
/timera/timer16/TALO4: U122.16 (Q6); also elsewhere on the board
/timera/timer16/TALO5: U122.5 (Q1); also elsewhere on the board
/timera/timer16/TALO6: U122.19 (Q7); also elsewhere on the board
/timera/timer16/TALO7: U122.2 (Q0); also elsewhere on the board
/timera/timeraPipeline/TIMERAINPUT: U124.8; also elsewhere on the board
/timera/~OETAHI: U108.6; also elsewhere on the board
/timera/~OETALO: U108.3; also elsewhere on the board
/timera/~WETAHI: U121.1 (~E), U126.8; also elsewhere on the board
/timera/~WETALO: U122.1 (~E), U126.6
/~PHI2: U121.11 (CP), U122.11 (CP); also elsewhere on the board
CNT: U123.3 (C); also elsewhere on the board
ENABLE_NAND: U108.2, U108.5, U126.5, U126.9; also elsewhere on the board
GND: U121.10 (GND), U122.10 (GND), U123.12 (D); also elsewhere on the board
unnamed: U118.2 (D), U123.9 (Q)
unnamed: U118.6 (~Q), U124.9
unnamed: U123.1 (~R), U123.8 (~Q)
unnamed: U123.6 (~Q), U123.10 (~S)
unnamed: U126.3, U126.4
unnamed: U126.10, U126.11
PHI2: U118.3 (C), U123.11 (C); also elsewhere on the board
VCC: U118.1 (~R), U118.4 (~S), U121.20 (VCC), U122.20 (VCC), U123.2 (D), U123.4 (~S), U123.13 (~R); also elsewhere on the board
~EN4: U108.1, U126.2; also elsewhere on the board
~EN5: U108.4, U126.12; also elsewhere on the board
~RES: U126.1, U126.13; also elsewhere on the board

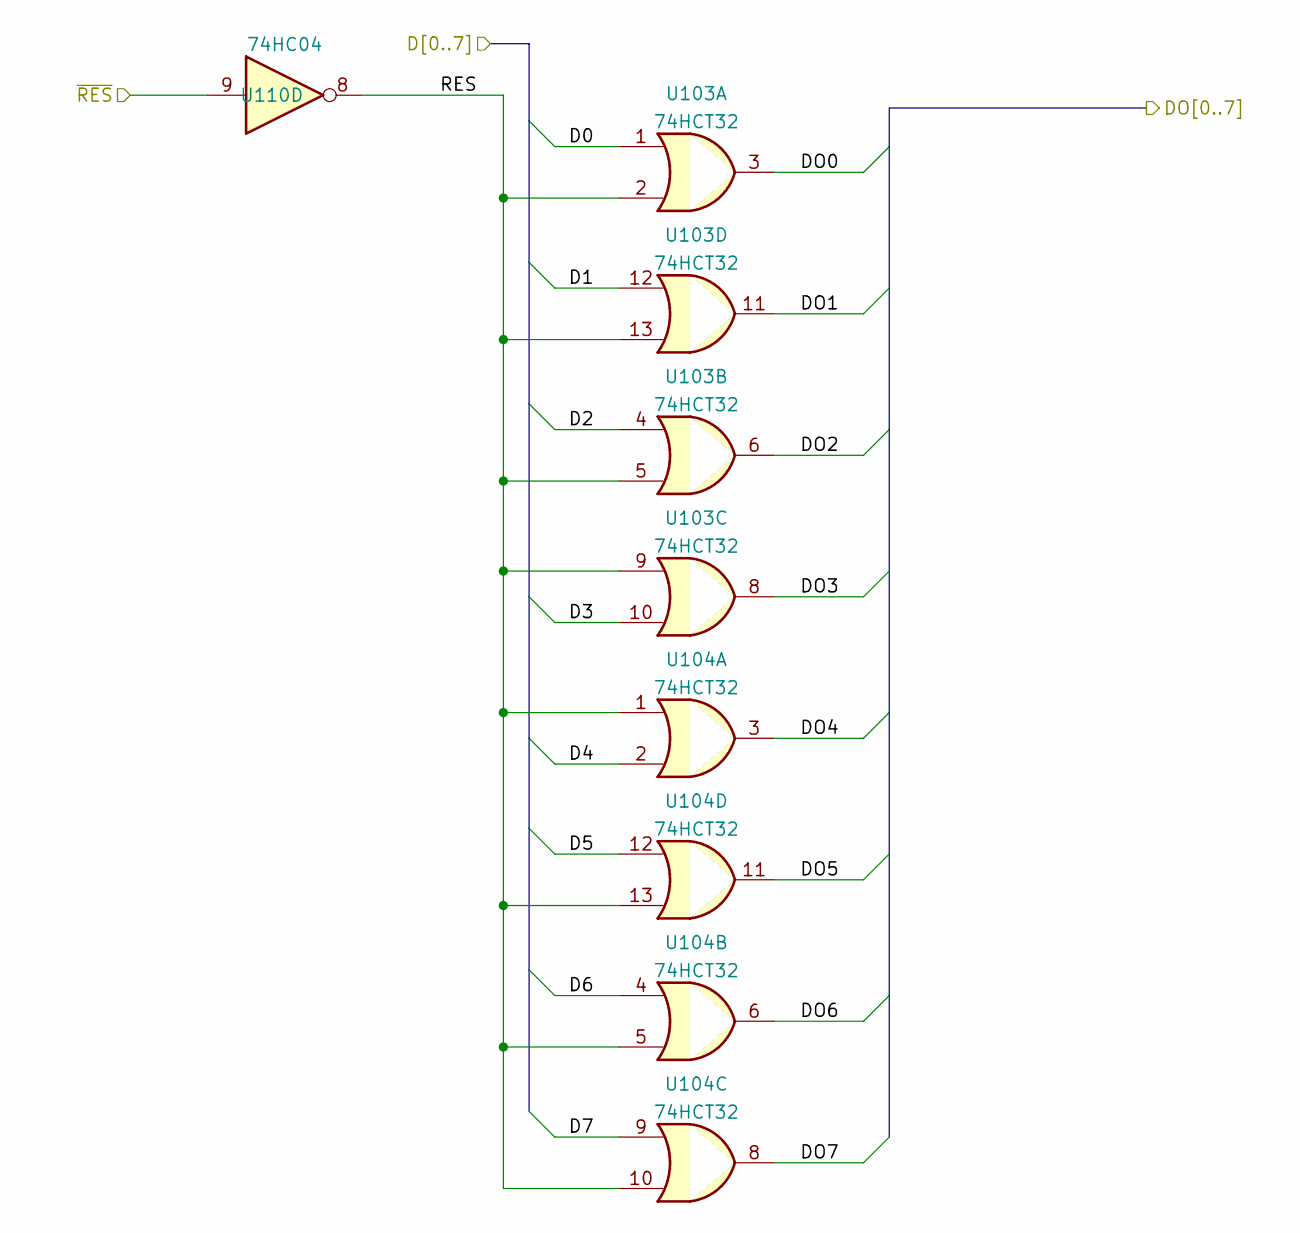
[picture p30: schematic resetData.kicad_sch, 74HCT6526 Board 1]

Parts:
U103, U104: 74HCT32; SO-14_3.9x8.65mm_P1.27mm
U110: 74HC04; SOIC-14_3.9x8.7mm_P1.27mm

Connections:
/resetData/DO0: U103.3; also elsewhere on the board
/resetData/DO1: U103.11; also elsewhere on the board
/resetData/DO2: U103.6; also elsewhere on the board
/resetData/DO3: U103.8; also elsewhere on the board
/resetData/DO4: U104.3; also elsewhere on the board
/resetData/DO5: U104.11; also elsewhere on the board
/resetData/DO6: U104.6; also elsewhere on the board
/resetData/DO7: U104.8; also elsewhere on the board
/resetData/RES: U103.2, U103.5, U103.9, U103.13, U104.1, U104.5, U104.10, U104.13, U110.8
D0: U103.1; also elsewhere on the board
D1: U103.12; also elsewhere on the board
D2: U103.4; also elsewhere on the board
D3: U103.10; also elsewhere on the board
D4: U104.2; also elsewhere on the board
D5: U104.12; also elsewhere on the board
D6: U104.4; also elsewhere on the board
D7: U104.9; also elsewhere on the board
~RES: U110.9; also elsewhere on the board


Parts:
U105: 74HC244; SOIC-20W_7.5x12.8mm_P1.27mm
U108: 74HC32; SOIC-14_3.9x8.7mm_P1.27mm
U110: 74HC04; SOIC-14_3.9x8.7mm_P1.27mm
U115, U120, U125: 74HC74; SO-14_3.9x8.65mm_P1.27mm
U124: 74HC00; SOIC-14_3.9x8.7mm_P1.27mm
U127: 74HC08; SO-14_3.9x8.65mm_P1.27mm
U128: 74HC377; SOIC-20W_7.5x12.8mm_P1.27mm

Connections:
/TAINMODE: U105.13 (2A2), U128.16 (Q6); also elsewhere on the board
/TALOAD: U120.5 (Q); also elsewhere on the board
/TAOUTMODE: U105.4 (1A1), U128.9 (Q3); also elsewhere on the board
/crega/TARUNMODE: U105.15 (2A1), U108.9, U120.12 (D), U128.12 (Q4)
/crega/TAUNDERFLOW: U124.5; also elsewhere on the board
/crega/WE14: U110.10, U127.1
/crega/rTASTART: U105.2 (1A0), U115.12 (D), U125.5 (Q)
/crega/~OE14: U105.1 (1OE), U105.19 (2OE), U108.11
/crega/~WE14: U110.11, U124.11, U128.1 (~E)
/~PHI2: U115.11 (C), U125.13 (~R), U127.2, U128.11 (CP); also elsewhere on the board
D0: U105.18 (1Y0); also elsewhere on the board
D1: U105.3 (2Y0); also elsewhere on the board
D2: U105.16 (1Y1); also elsewhere on the board
D3: U105.5 (2Y1); also elsewhere on the board
D4: U105.14 (1Y2); also elsewhere on the board
D5: U105.7 (2Y2); also elsewhere on the board
D6: U105.12 (1Y3); also elsewhere on the board
D7: U105.9 (2Y3); also elsewhere on the board
DZ0: U125.2 (D); also elsewhere on the board
DZ1: U128.14 (D5); also elsewhere on the board
DZ2: U128.8 (D3); also elsewhere on the board
DZ3: U128.13 (D4); also elsewhere on the board
DZ4: U125.12 (D); also elsewhere on the board
DZ5: U128.17 (D6); also elsewhere on the board
DZ6: U128.7 (D2); also elsewhere on the board
DZ7: U128.18 (D7); also elsewhere on the board
ENABLE_NAND: U108.13, U124.12; also elsewhere on the board
GND: U105.6 (1A2), U105.10 (GND), U128.10 (GND); also elsewhere on the board
unnamed: U108.8, U124.4
unnamed: U108.10, U120.9 (Q)
unnamed: U120.2 (D), U125.9 (Q)
unnamed: U124.6, U125.1 (~R)
unnamed: U124.3, U124.13
unnamed: U125.3 (C), U125.11 (C), U127.3
PB6ON: U105.17 (2A0), U128.15 (Q5); also elsewhere on the board
PHI2: U120.3 (C), U120.11 (C); also elsewhere on the board
SPMODE: U105.8 (1A3), U128.6 (Q2); also elsewhere on the board
TASTART: U115.9 (Q); also elsewhere on the board
TODIN: U105.11 (2A3), U128.19 (Q7); also elsewhere on the board
VCC: U105.20 (VCC), U115.10 (~S), U115.13 (~R), U120.1 (~R), U120.4 (~S), U120.10 (~S), U120.13 (~R), U125.4 (~S), U125.10 (~S), U128.3 (D0), U128.4 (D1), U128.20 (VCC); also elsewhere on the board
~EN14: U108.12, U124.2; also elsewhere on the board
~RES: U124.1; also elsewhere on the board


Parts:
C101, C102, C103, C104, C105, C106, C107, C108, C109, C110, C111, C112, C113, C114, C115, C116, C117, C118, C119, C120, C121, C122, C123, C124, C125, C126, C127, C128, C129: 100n; C_0603_1608Metric
U103, U104: 74HCT32; SO-14_3.9x8.65mm_P1.27mm
U108: 74HC32; SOIC-14_3.9x8.7mm_P1.27mm
U109, U115, U118, U119, U120, U125, U129: 74HC74; SO-14_3.9x8.65mm_P1.27mm
U110: 74HC04; SOIC-14_3.9x8.7mm_P1.27mm
U113: 74HC27; SO-14_3.9x8.65mm_P1.27mm
U123: 74HCT74; SO-14_3.9x8.65mm_P1.27mm
U124: 74HC00; SOIC-14_3.9x8.7mm_P1.27mm
U126: 74HC00; SO-14_3.9x8.65mm_P1.27mm
U127: 74HC08; SO-14_3.9x8.65mm_P1.27mm

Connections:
GND: C101.2, C102.2, C103.2, C104.2, C105.2, C106.2, C107.2, C108.2, C109.2, C110.2, C111.2, C112.2, C113.2, C114.2, C115.2, C116.2, C117.2, C118.2, C119.2, C120.2, C121.2, C122.2, C123.2, C124.2, C125.2, C126.2, C127.2, C128.2, C129.2, U103.7 (GND), U104.7 (GND), U108.7 (GND), U109.7 (GND), U110.7 (GND), U113.7 (GND), U115.7 (GND), U118.7 (GND), U119.7 (GND), U120.7 (GND), U123.7 (GND), U124.7 (GND), U125.7 (GND), U126.7 (GND), U127.7 (GND), U129.7 (GND); also elsewhere on the board
VCC: C101.1, C102.1, C103.1, C104.1, C105.1, C106.1, C107.1, C108.1, C109.1, C110.1, C111.1, C112.1, C113.1, C114.1, C115.1, C116.1, C117.1, C118.1, C119.1, C120.1, C121.1, C122.1, C123.1, C124.1, C125.1, C126.1, C127.1, C128.1, C129.1, U103.14 (VCC), U104.14 (VCC), U108.14 (VCC), U109.14 (VCC), U110.3, U110.5, U110.14 (VCC), U113.14 (VCC), U115.14 (VCC), U118.14 (VCC), U119.10 (~S), U119.11 (C), U119.12 (D), U119.13 (~R), U119.14 (VCC), U120.14 (VCC), U123.14 (VCC), U124.14 (VCC), U125.14 (VCC), U126.14 (VCC), U127.14 (VCC), U129.14 (VCC); also elsewhere on the board


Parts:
C100: 100n; C_0603_1608Metric
CONTROLBUS1: Conn_02x10_Odd_Even; PinHeader_2x10_P2.54mm_Vertical
DATABUS1: Conn_02x10_Odd_Even; PinHeader_2x10_P2.54mm_Vertical
ENABLEBUS1: Conn_02x10_Odd_Even; PinHeader_2x10_P2.54mm_Vertical

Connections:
ALARM: CONTROLBUS1.14
CNT: CONTROLBUS1.3; also elsewhere on the board
D0: DATABUS1.8; also elsewhere on the board
D1: DATABUS1.7; also elsewhere on the board
D2: DATABUS1.6; also elsewhere on the board
D3: DATABUS1.5; also elsewhere on the board
D4: DATABUS1.4; also elsewhere on the board
D5: DATABUS1.3; also elsewhere on the board
D6: DATABUS1.2; also elsewhere on the board
D7: DATABUS1.1; also elsewhere on the board
DZ0: DATABUS1.13; also elsewhere on the board
DZ1: DATABUS1.17; also elsewhere on the board
DZ2: DATABUS1.20; also elsewhere on the board
DZ3: DATABUS1.16; also elsewhere on the board
DZ4: DATABUS1.14; also elsewhere on the board
DZ5: DATABUS1.18; also elsewhere on the board
DZ6: DATABUS1.19; also elsewhere on the board
DZ7: DATABUS1.15; also elsewhere on the board
ENABLE_NAND: CONTROLBUS1.16; also elsewhere on the board
GND: C100.2, DATABUS1.10, DATABUS1.12, ENABLEBUS1.14, ENABLEBUS1.16, ENABLEBUS1.18, ENABLEBUS1.20; also elsewhere on the board
PB6ON: CONTROLBUS1.2; also elsewhere on the board
PB7ON: CONTROLBUS1.4
PHI2: CONTROLBUS1.7; also elsewhere on the board
SP: CONTROLBUS1.5
SPMODE: CONTROLBUS1.10; also elsewhere on the board
TAOUT: CONTROLBUS1.6; also elsewhere on the board
TAPULSE: CONTROLBUS1.13; also elsewhere on the board
TASTART: CONTROLBUS1.1; also elsewhere on the board
TBOUT: CONTROLBUS1.8
TBPULSE: CONTROLBUS1.15
TOD: CONTROLBUS1.11
TODIN: CONTROLBUS1.12; also elsewhere on the board
TODIRQ: CONTROLBUS1.17
VCC: DATABUS1.9, DATABUS1.11, ENABLEBUS1.6, ENABLEBUS1.8, ENABLEBUS1.10, ENABLEBUS1.12; also elsewhere on the board
~EN4: ENABLEBUS1.4; also elsewhere on the board
~EN5: ENABLEBUS1.2; also elsewhere on the board
~EN6: ENABLEBUS1.1
~EN7: ENABLEBUS1.3
~EN8: ENABLEBUS1.17
~EN9: ENABLEBUS1.15
~EN10: ENABLEBUS1.13
~EN11: ENABLEBUS1.11
~EN12: ENABLEBUS1.9
~EN13: ENABLEBUS1.7
~EN14: ENABLEBUS1.5; also elsewhere on the board
~EN15: ENABLEBUS1.19
~FLAG: CONTROLBUS1.9
~IRQ: CONTROLBUS1.19
~RES: C100.1, CONTROLBUS1.20; also elsewhere on the board

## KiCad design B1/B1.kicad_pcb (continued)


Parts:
U101, U102: 74HC244; SOIC-20W_7.5x12.8mm_P1.27mm
U106, U107: 74HC688; SOIC-20W_7.5x12.8mm_P1.27mm
U111, U112, U116, U117: 74HC193; SOIC-16_3.9x9.9mm_P1.27mm
U127: 74HC08; SO-14_3.9x8.65mm_P1.27mm

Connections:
/timera/TACOUNT: U127.13; also elsewhere on the board
/timera/timer16/TA0: U102.17 (2A0), U107.17 (P7), U117.3 (QA)
/timera/timer16/TA1: U102.2 (1A0), U107.2 (P0), U117.2 (QB)
/timera/timer16/TA2: U102.15 (2A1), U107.15 (P6), U117.6 (QC)
/timera/timer16/TA3: U102.4 (1A1), U107.4 (P1), U117.7 (QD)
/timera/timer16/TA4: U102.13 (2A2), U107.13 (P5), U112.3 (QA)
/timera/timer16/TA5: U102.6 (1A2), U107.6 (P2), U112.2 (QB)
/timera/timer16/TA6: U102.8 (1A3), U107.8 (P3), U112.6 (QC)
/timera/timer16/TA7: U102.11 (2A3), U107.11 (P4), U112.7 (QD)
/timera/timer16/TA8: U101.17 (2A0), U106.17 (P7), U116.3 (QA)
/timera/timer16/TA9: U101.2 (1A0), U106.2 (P0), U116.2 (QB)
/timera/timer16/TA10: U101.15 (2A1), U106.15 (P6), U116.6 (QC)
/timera/timer16/TA11: U101.4 (1A1), U106.4 (P1), U116.7 (QD)
/timera/timer16/TA12: U101.13 (2A2), U106.13 (P5), U111.3 (QA)
/timera/timer16/TA13: U101.6 (1A2), U106.6 (P2), U111.2 (QB)
/timera/timer16/TA14: U101.8 (1A3), U106.8 (P3), U111.6 (QC)
/timera/timer16/TA15: U101.11 (2A3), U106.11 (P4), U111.7 (QD)
/timera/timer16/TACOMPCASCADE: U106.19 (P=R), U107.1 (G)
/timera/timer16/TAHI0: U116.15 (A); also elsewhere on the board
/timera/timer16/TAHI1: U116.1 (B); also elsewhere on the board
/timera/timer16/TAHI2: U116.10 (C); also elsewhere on the board
/timera/timer16/TAHI3: U116.9 (D); also elsewhere on the board
/timera/timer16/TAHI4: U111.15 (A); also elsewhere on the board
/timera/timer16/TAHI5: U111.1 (B); also elsewhere on the board
/timera/timer16/TAHI6: U111.10 (C); also elsewhere on the board
/timera/timer16/TAHI7: U111.9 (D); also elsewhere on the board
/timera/timer16/TALO0: U117.15 (A); also elsewhere on the board
/timera/timer16/TALO1: U117.1 (B); also elsewhere on the board
/timera/timer16/TALO2: U117.10 (C); also elsewhere on the board
/timera/timer16/TALO3: U117.9 (D); also elsewhere on the board
/timera/timer16/TALO4: U112.15 (A); also elsewhere on the board
/timera/timer16/TALO5: U112.1 (B); also elsewhere on the board
/timera/timer16/TALO6: U112.10 (C); also elsewhere on the board
/timera/timer16/TALO7: U112.9 (D); also elsewhere on the board
/timera/timer16/~TIMER_UNDERFLOW: U107.19 (P=R); also elsewhere on the board
/timera/~OETAHI: U101.1 (1OE), U101.19 (2OE); also elsewhere on the board
/timera/~OETALO: U102.1 (1OE), U102.19 (2OE); also elsewhere on the board
/timera/~TALOAD: U127.4; also elsewhere on the board
D0: U101.3 (2Y0), U102.3 (2Y0); also elsewhere on the board
D1: U101.18 (1Y0), U102.18 (1Y0); also elsewhere on the board
D2: U101.5 (2Y1), U102.5 (2Y1); also elsewhere on the board
D3: U101.16 (1Y1), U102.16 (1Y1); also elsewhere on the board
D4: U101.7 (2Y2), U102.7 (2Y2); also elsewhere on the board
D5: U101.14 (1Y2), U102.14 (1Y2); also elsewhere on the board
D6: U101.12 (1Y3), U102.12 (1Y3); also elsewhere on the board
D7: U101.9 (2Y3), U102.9 (2Y3); also elsewhere on the board
GND: U101.10 (GND), U102.10 (GND), U106.1 (G), U106.3 (R0), U106.5 (R1), U106.7 (R2), U106.9 (R3), U106.10 (GND), U106.12 (R4), U106.14 (R5), U106.16 (R6), U106.18 (R7), U107.3 (R0), U107.5 (R1), U107.7 (R2), U107.9 (R3), U107.10 (GND), U107.12 (R4), U107.14 (R5), U107.16 (R6), U107.18 (R7), U111.8 (GND), U111.14 (CLR), U112.8 (GND), U112.14 (CLR), U116.8 (GND), U116.14 (CLR), U117.8 (GND), U117.14 (CLR); also elsewhere on the board
unnamed: U111.4 (DOWN), U116.13 (~BO)
unnamed: U111.11 (~LOAD), U112.11 (~LOAD), U116.11 (~LOAD), U117.11 (~LOAD), U127.6
unnamed: U112.4 (DOWN), U117.13 (~BO)
unnamed: U112.13 (~BO), U116.4 (DOWN)
unnamed: U117.4 (DOWN), U127.11
PHI2: U127.12; also elsewhere on the board
VCC: U101.20 (VCC), U102.20 (VCC), U106.20 (VCC), U107.20 (VCC), U111.5 (UP), U111.16 (VCC), U112.5 (UP), U112.16 (VCC), U116.5 (UP), U116.16 (VCC), U117.5 (UP), U117.16 (VCC); also elsewhere on the board
~RES: U127.5; also elsewhere on the board


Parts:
U109, U115: 74HC74; SO-14_3.9x8.65mm_P1.27mm
U114: 74HC153; SOIC-16_3.9x9.9mm_P1.27mm

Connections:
/TAOUTMODE: U114.14 (S0); also elsewhere on the board
/timera/timeraOutput/TAPULSESET: U115.4 (~S); also elsewhere on the board
/timera/timeraOutput/TATOGGLE: U109.9 (Q), U114.5 (I1a)
/timera/timeraOutput/TATOGGLESET: U109.6 (~Q), U109.10 (~S)
/timera/timeraOutput/~TATOGGLE: U109.8 (~Q), U109.12 (D)
/~PHI2: U109.1 (~R); also elsewhere on the board
GND: U114.1 (Ea), U114.2 (S1), U114.3 (I3a), U114.4 (I2a), U114.8 (GND), U114.10 (I0b), U114.11 (I1b), U114.12 (I2b), U114.13 (I3b), U114.15 (Eb), U115.2 (D); also elsewhere on the board
PHI2: U115.3 (C); also elsewhere on the board
TAOUT: U114.7 (Za); also elsewhere on the board
TAPULSE: U109.11 (C), U114.6 (I0a), U115.5 (Q); also elsewhere on the board
TASTART: U109.3 (C); also elsewhere on the board
VCC: U109.2 (D), U109.4 (~S), U114.16 (VCC), U115.1 (~R); also elsewhere on the board
~RES: U109.13 (~R); also elsewhere on the board

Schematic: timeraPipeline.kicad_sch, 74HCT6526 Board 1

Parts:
U110: 74HC04; SOIC-14_3.9x8.7mm_P1.27mm
U113: 74HC27; SO-14_3.9x8.65mm_P1.27mm
U118, U119, U129: 74HC74; SO-14_3.9x8.65mm_P1.27mm
U127: 74HC08; SO-14_3.9x8.65mm_P1.27mm

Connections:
/TALOAD: U113.10; also elsewhere on the board
/crega/TAUNDERFLOW: U110.13, U113.6, U113.9; also elsewhere on the board
/timera/TACOUNT: U119.5 (Q); also elsewhere on the board
/timera/timer16/~TIMER_UNDERFLOW: U113.3; also elsewhere on the board
/timera/timeraOutput/TAPULSESET: U110.12, U118.13 (~R); also elsewhere on the board
/timera/timeraPipeline/TIMERAINPUT: U127.10; also elsewhere on the board
/timera/~TALOAD: U129.9 (Q); also elsewhere on the board
/timera/~WETAHI: U113.13; also elsewhere on the board
/~PHI2: U129.3 (C), U129.11 (C); also elsewhere on the board
GND: U113.2, U113.4; also elsewhere on the board
unnamed: U113.5, U118.8 (~Q)
unnamed: U113.8, U129.1 (~R), U129.13 (~R)
unnamed: U113.11, U113.12
unnamed: U118.9 (Q), U119.1 (~R), U119.2 (D)
unnamed: U118.12 (D), U127.8
unnamed: U129.5 (Q), U129.12 (D)
PHI2: U118.11 (C), U119.3 (C); also elsewhere on the board
TASTART: U113.1, U127.9; also elsewhere on the board
VCC: U118.10 (~S), U119.4 (~S), U129.2 (D), U129.4 (~S), U129.10 (~S); also elsewhere on the board


Board: 4 copper layers, 100.0 x 100.0 mm, 66 parts (0 on the bottom side), 118 nets.

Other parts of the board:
GND101, GND102: GND; MountingHole_2.2mm_M2_DIN965_Pad
VCC101, VCC102: VCC; MountingHole_2.2mm_M2_DIN965_Pad

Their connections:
GND: GND101.GND, GND102.GND; also elsewhere on the board
VCC: VCC101.VCC, VCC102.VCC; also elsewhere on the board

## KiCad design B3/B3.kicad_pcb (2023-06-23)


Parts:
U328: 74HC00; SO-14_3.9x8.65mm_P1.27mm

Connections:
/~PHI2: U328.8; also elsewhere on the board
PHI2: U328.9, U328.10; also elsewhere on the board


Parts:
C300: 100n; C_0603_1608Metric
CONTROLBUS3: Conn_02x10_Odd_Even; PinHeader_2x10_P2.54mm_Vertical
DATABUS3: Conn_02x10_Odd_Even; PinHeader_2x10_P2.54mm_Vertical
ENABLEBUS3: Conn_02x10_Odd_Even; PinHeader_2x10_P2.54mm_Vertical

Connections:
ALARM: CONTROLBUS3.14
CNT: CONTROLBUS3.3; also elsewhere on the board
D0: DATABUS3.8; also elsewhere on the board
D1: DATABUS3.7; also elsewhere on the board
D2: DATABUS3.6; also elsewhere on the board
D3: DATABUS3.5; also elsewhere on the board
D4: DATABUS3.4; also elsewhere on the board
D5: DATABUS3.3; also elsewhere on the board
D6: DATABUS3.2; also elsewhere on the board
D7: DATABUS3.1; also elsewhere on the board
DZ0: DATABUS3.13; also elsewhere on the board
DZ1: DATABUS3.17; also elsewhere on the board
DZ2: DATABUS3.20; also elsewhere on the board
DZ3: DATABUS3.16; also elsewhere on the board
DZ4: DATABUS3.14; also elsewhere on the board
DZ5: DATABUS3.18; also elsewhere on the board
DZ6: DATABUS3.19; also elsewhere on the board
DZ7: DATABUS3.15; also elsewhere on the board
ENABLE_NAND: CONTROLBUS3.16; also elsewhere on the board
GND: C300.2, DATABUS3.10, DATABUS3.12, ENABLEBUS3.14, ENABLEBUS3.16, ENABLEBUS3.18, ENABLEBUS3.20; also elsewhere on the board
PB6ON: CONTROLBUS3.2
PB7ON: CONTROLBUS3.4
PHI2: CONTROLBUS3.7; also elsewhere on the board
SP: CONTROLBUS3.5; also elsewhere on the board
SPMODE: CONTROLBUS3.10; also elsewhere on the board
TAOUT: CONTROLBUS3.6
TAPULSE: CONTROLBUS3.13; also elsewhere on the board
TASTART: CONTROLBUS3.1; also elsewhere on the board
TBOUT: CONTROLBUS3.8
TBPULSE: CONTROLBUS3.15; also elsewhere on the board
TOD: CONTROLBUS3.11
TODIN: CONTROLBUS3.12
TODIRQ: CONTROLBUS3.17; also elsewhere on the board
VCC: DATABUS3.9, DATABUS3.11, ENABLEBUS3.6, ENABLEBUS3.8, ENABLEBUS3.10, ENABLEBUS3.12; also elsewhere on the board
~EN4: ENABLEBUS3.4
~EN5: ENABLEBUS3.2
~EN6: ENABLEBUS3.1
~EN7: ENABLEBUS3.3
~EN8: ENABLEBUS3.17
~EN9: ENABLEBUS3.15
~EN10: ENABLEBUS3.13
~EN11: ENABLEBUS3.11
~EN12: ENABLEBUS3.9; also elsewhere on the board
~EN13: ENABLEBUS3.7; also elsewhere on the board
~EN14: ENABLEBUS3.5
~EN15: ENABLEBUS3.19
~FLAG: CONTROLBUS3.9; also elsewhere on the board
~IRQ: CONTROLBUS3.19; also elsewhere on the board
~RES: C300.1, CONTROLBUS3.20; also elsewhere on the board


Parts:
C301, C302, C303, C304, C305, C306, C307, C308, C309, C310, C311, C312, C313, C314, C315, C316, C317, C318, C319, C320, C321, C322, C323, C324, C325, C326, C327, C328, C329, C330, C331, C332, C333, C334, C335, C336, C337, C338, C339, C340, C341, C342: 100n; C_0603_1608Metric
U301, U309, U316, U320, U321, U322, U323, U324, U328, U329: 74HC00; SO-14_3.9x8.65mm_P1.27mm
U302: 74HCT125; SO-14_3.9x8.65mm_P1.27mm
U303, U304, U317, U330, U331, U332, U333, U334, U340, U342: 74HC74; SO-14_3.9x8.65mm_P1.27mm
U305: 74HCT74; SO-14_3.9x8.65mm_P1.27mm
U306, U314, U319, U338: 74HC32; SO-14_3.9x8.65mm_P1.27mm
U318, U325, U326, U337, U339: 74HC08; SO-14_3.9x8.65mm_P1.27mm
U335: 74HCT04; SO-14_3.9x8.65mm_P1.27mm
U341: 74HC157; SO-16_3.9x9.9mm_P1.27mm

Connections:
GND: C301.2, C302.2, C303.2, C304.2, C305.2, C306.2, C307.2, C308.2, C309.2, C310.2, C311.2, C312.2, C313.2, C314.2, C315.2, C316.2, C317.2, C318.2, C319.2, C320.2, C321.2, C322.2, C323.2, C324.2, C325.2, C326.2, C327.2, C328.2, C329.2, C330.2, C331.2, C332.2, C333.2, C334.2, C335.2, C336.2, C337.2, C338.2, C339.2, C340.2, C341.2, C342.2, U301.7 (GND), U302.7 (GND), U302.9, U302.10, U303.7 (GND), U304.7 (GND), U305.7 (GND), U306.7 (GND), U309.7 (GND), U309.9, U309.10, U314.4, U314.5, U314.7 (GND), U316.7 (GND), U317.7 (GND), U318.7 (GND), U319.7 (GND), U320.7 (GND), U321.7 (GND), U322.7 (GND), U323.7 (GND), U324.7 (GND), U325.4, U325.5, U325.7 (GND), U325.12, U325.13, U326.7 (GND), U328.4, U328.5, U328.7 (GND), U329.7 (GND), U330.7 (GND), U331.7 (GND), U332.7 (GND), U333.7 (GND), U334.7 (GND), U335.5, U335.7 (GND), U337.1, U337.2, U337.7 (GND), U338.7 (GND), U339.1, U339.2, U339.4, U339.5, U339.7 (GND), U340.7 (GND), U341.8 (GND), U341.13, U341.14, U342.7 (GND); also elsewhere on the board
VCC: C301.1, C302.1, C303.1, C304.1, C305.1, C306.1, C307.1, C308.1, C309.1, C310.1, C311.1, C312.1, C313.1, C314.1, C315.1, C316.1, C317.1, C318.1, C319.1, C320.1, C321.1, C322.1, C323.1, C324.1, C325.1, C326.1, C327.1, C328.1, C329.1, C330.1, C331.1, C332.1, C333.1, C334.1, C335.1, C336.1, C337.1, C338.1, C339.1, C340.1, C341.1, C342.1, U301.14 (VCC), U302.14 (VCC), U303.14 (VCC), U304.14 (VCC), U305.14 (VCC), U306.14 (VCC), U309.14 (VCC), U314.14 (VCC), U316.14 (VCC), U317.14 (VCC), U318.14 (VCC), U319.14 (VCC), U320.14 (VCC), U321.14 (VCC), U322.14 (VCC), U323.14 (VCC), U324.14 (VCC), U325.14 (VCC), U326.14 (VCC), U328.14 (VCC), U329.14 (VCC), U330.14 (VCC), U331.14 (VCC), U332.14 (VCC), U333.14 (VCC), U334.14 (VCC), U335.14 (VCC), U337.14 (VCC), U338.14 (VCC), U339.14 (VCC), U340.10 (~S), U340.11 (C), U340.12 (D), U340.13 (~R), U340.14 (VCC), U341.16 (VCC), U342.14 (VCC); also elsewhere on the board


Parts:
U314, U319: 74HC32; SO-14_3.9x8.65mm_P1.27mm
U316: 74HC00; SO-14_3.9x8.65mm_P1.27mm
U317: 74HC74; SO-14_3.9x8.65mm_P1.27mm
U318: 74HC08; SO-14_3.9x8.65mm_P1.27mm

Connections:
/sdr/sdrController/DONE: U316.1, U316.2; also elsewhere on the board
/sdr/sdrController/S0': U314.3, U317.2 (D)
/sdr/sdrController/S1': U317.12 (D), U319.3
/sdr/sdrController/SDRCOUNT: U317.9 (Q), U318.1, U318.13; also elsewhere on the board
/sdr/sdrController/~FULL: U316.5; also elsewhere on the board
/sdr/sdrController/~SDRCOUNT: U317.8 (~Q), U318.10, U319.5; also elsewhere on the board
/sdr/sdrController/~SDRRES: U318.4; also elsewhere on the board
/sdr/sdrController/~WRITE: U316.9, U316.10; also elsewhere on the board
/~PHI2: U317.3 (C), U317.11 (C); also elsewhere on the board
/~SDRIRQ: U316.11; also elsewhere on the board
unnamed: U314.1, U318.11
unnamed: U314.2, U316.8, U319.4
unnamed: U316.3, U318.2, U319.13
unnamed: U316.4, U319.8
unnamed: U316.6, U316.12, U316.13
unnamed: U317.1 (~R), U317.13 (~R), U318.6
unnamed: U317.5 (Q), U318.9, U318.12, U319.12
unnamed: U318.3, U319.1
unnamed: U318.8, U319.2
unnamed: U319.6, U319.9
unnamed: U319.10, U319.11
TASTART: U318.5; also elsewhere on the board
VCC: U317.4 (~S), U317.10 (~S); also elsewhere on the board


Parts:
U301: 74HC00; SO-14_3.9x8.65mm_P1.27mm
U302: 74HCT125; SO-14_3.9x8.65mm_P1.27mm
U303, U304: 74HC74; SO-14_3.9x8.65mm_P1.27mm
U305: 74HCT74; SO-14_3.9x8.65mm_P1.27mm
U306: 74HC32; SO-14_3.9x8.65mm_P1.27mm
U307: 74HC299; SOIC-20W_7.5x12.8mm_P1.27mm
U308: 74HC193; SO-16_3.9x9.9mm_P1.27mm

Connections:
/sdr/sdrController/~FULL: U304.6 (~Q), U304.13 (~R), U307.2 (OE1), U307.3 (OE2); also elsewhere on the board
/sdr/sdrInput/FULL: U304.5 (Q), U306.5; also elsewhere on the board
/sdr/sdrInput/INDATA0: U307.7 (IO0); also elsewhere on the board
/sdr/sdrInput/INDATA1: U307.13 (IO1); also elsewhere on the board
/sdr/sdrInput/INDATA2: U307.6 (IO2); also elsewhere on the board
/sdr/sdrInput/INDATA3: U307.14 (IO3); also elsewhere on the board
/sdr/sdrInput/INDATA4: U307.5 (IO4); also elsewhere on the board
/sdr/sdrInput/INDATA5: U307.15 (IO5); also elsewhere on the board
/sdr/sdrInput/INDATA6: U307.4 (IO6); also elsewhere on the board
/sdr/sdrInput/INDATA7: U307.16 (IO7); also elsewhere on the board
/~PHI2: U303.3 (C), U303.11 (C), U304.3 (C); also elsewhere on the board
CNT: U305.3 (C); also elsewhere on the board
GND: U302.1, U303.12 (D), U304.2 (D), U307.10 (GND), U307.19 (S1), U308.8 (GND); also elsewhere on the board
unnamed: U301.3, U306.4
unnamed: U302.3, U307.11 (Ds0)
unnamed: U303.2 (D), U303.9 (Q)
unnamed: U303.5 (Q), U307.12 (Cp), U308.5 (UP)
unnamed: U303.6 (~Q), U305.1 (~R)
unnamed: U303.10 (~S), U305.6 (~Q)
unnamed: U304.4 (~S), U304.8 (~Q)
unnamed: U304.11 (C), U308.7 (QD)
unnamed: U306.1, U306.6
unnamed: U306.3, U308.14 (CLR)
SP: U302.2; also elsewhere on the board
SPMODE: U306.2; also elsewhere on the board
VCC: U303.1 (~R), U303.4 (~S), U303.13 (~R), U304.1 (~R), U304.10 (~S), U304.12 (D), U305.2 (D), U305.4 (~S), U307.1 (S0), U307.9 (Mr), U307.18 (Ds7), U307.20 (VCC), U308.1 (B), U308.4 (DOWN), U308.9 (D), U308.10 (C), U308.11 (~LOAD), U308.15 (A), U308.16 (VCC); also elsewhere on the board
~RES: U301.1, U301.2; also elsewhere on the board

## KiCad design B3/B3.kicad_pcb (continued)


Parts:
U306: 74HC32; SO-14_3.9x8.65mm_P1.27mm
U309: 74HC00; SO-14_3.9x8.65mm_P1.27mm
U310, U312: 74HC244; SOIC-20W_7.5x12.8mm_P1.27mm
U311: 74HC377; SOIC-20W_7.5x12.8mm_P1.27mm
U325: 74HC08; SO-14_3.9x8.65mm_P1.27mm

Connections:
/sdr/sdrController/~FULL: U325.2; also elsewhere on the board
/sdr/sdrController/~WRITE: U306.9, U309.6, U325.1; also elsewhere on the board
/sdr/sdrInput/FULL: U306.10; also elsewhere on the board
/sdr/sdrInput/INDATA0: U310.9 (2Y3), U311.13 (D4); also elsewhere on the board
/sdr/sdrInput/INDATA1: U310.12 (1Y3), U311.8 (D3); also elsewhere on the board
/sdr/sdrInput/INDATA2: U310.7 (2Y2), U311.14 (D5); also elsewhere on the board
/sdr/sdrInput/INDATA3: U310.14 (1Y2), U311.7 (D2); also elsewhere on the board
/sdr/sdrInput/INDATA4: U310.16 (1Y1), U311.17 (D6); also elsewhere on the board
/sdr/sdrInput/INDATA5: U310.5 (2Y1), U311.4 (D1); also elsewhere on the board
/sdr/sdrInput/INDATA6: U310.18 (1Y0), U311.18 (D7); also elsewhere on the board
/sdr/sdrInput/INDATA7: U310.3 (2Y0), U311.3 (D0); also elsewhere on the board
/sdr/sdrOutput/OUTDATA0: U311.12 (Q4), U312.11 (2A3); also elsewhere on the board
/sdr/sdrOutput/OUTDATA1: U311.9 (Q3), U312.8 (1A3); also elsewhere on the board
/sdr/sdrOutput/OUTDATA2: U311.15 (Q5), U312.13 (2A2); also elsewhere on the board
/sdr/sdrOutput/OUTDATA3: U311.6 (Q2), U312.6 (1A2); also elsewhere on the board
/sdr/sdrOutput/OUTDATA4: U311.16 (Q6), U312.4 (1A1); also elsewhere on the board
/sdr/sdrOutput/OUTDATA5: U311.5 (Q1), U312.15 (2A1); also elsewhere on the board
/sdr/sdrOutput/OUTDATA6: U311.19 (Q7), U312.2 (1A0); also elsewhere on the board
/sdr/sdrOutput/OUTDATA7: U311.2 (Q0), U312.17 (2A0); also elsewhere on the board
/sdr/sdrRegister/~OE12: U306.11, U312.1 (1OE), U312.19 (2OE)
/~PHI2: U311.11 (CP); also elsewhere on the board
D0: U312.9 (2Y3); also elsewhere on the board
D1: U312.12 (1Y3); also elsewhere on the board
D2: U312.7 (2Y2); also elsewhere on the board
D3: U312.14 (1Y2); also elsewhere on the board
D4: U312.16 (1Y1); also elsewhere on the board
D5: U312.5 (2Y1); also elsewhere on the board
D6: U312.18 (1Y0); also elsewhere on the board
D7: U312.3 (2Y0); also elsewhere on the board
DZ0: U310.11 (2A3); also elsewhere on the board
DZ1: U310.8 (1A3); also elsewhere on the board
DZ2: U310.13 (2A2); also elsewhere on the board
DZ3: U310.6 (1A2); also elsewhere on the board
DZ4: U310.4 (1A1); also elsewhere on the board
DZ5: U310.15 (2A1); also elsewhere on the board
DZ6: U310.2 (1A0); also elsewhere on the board
DZ7: U310.17 (2A0); also elsewhere on the board
ENABLE_NAND: U306.12, U309.5; also elsewhere on the board
GND: U310.10 (GND), U311.10 (GND), U312.10 (GND); also elsewhere on the board
unnamed: U306.8, U310.1 (1OE), U310.19 (2OE)
unnamed: U309.3, U309.4
unnamed: U311.1 (~E), U325.3
VCC: U310.20 (VCC), U311.20 (VCC), U312.20 (VCC); also elsewhere on the board
~EN12: U306.13, U309.1; also elsewhere on the board
~RES: U309.2; also elsewhere on the board


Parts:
U301, U309: 74HC00; SO-14_3.9x8.65mm_P1.27mm
U302: 74HCT125; SO-14_3.9x8.65mm_P1.27mm
U305: 74HCT74; SO-14_3.9x8.65mm_P1.27mm
U313: 74HC299; SOIC-20W_7.5x12.8mm_P1.27mm
U314: 74HC32; SO-14_3.9x8.65mm_P1.27mm
U315: 74HC193; SO-16_3.9x9.9mm_P1.27mm
U340: 74HC74; SO-14_3.9x8.65mm_P1.27mm

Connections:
/sdr/sdrController/DONE: U315.7 (QD); also elsewhere on the board
/sdr/sdrController/SDRCOUNT: U305.10 (~S); also elsewhere on the board
/sdr/sdrController/~SDRCOUNT: U314.9, U315.14 (CLR), U340.2 (D); also elsewhere on the board
/sdr/sdrController/~SDRRES: U301.6, U305.13 (~R); also elsewhere on the board
/sdr/sdrOutput/OUTDATA0: U313.7 (IO0); also elsewhere on the board
/sdr/sdrOutput/OUTDATA1: U313.13 (IO1); also elsewhere on the board
/sdr/sdrOutput/OUTDATA2: U313.6 (IO2); also elsewhere on the board
/sdr/sdrOutput/OUTDATA3: U313.14 (IO3); also elsewhere on the board
/sdr/sdrOutput/OUTDATA4: U313.5 (IO4); also elsewhere on the board
/sdr/sdrOutput/OUTDATA5: U313.15 (IO5); also elsewhere on the board
/sdr/sdrOutput/OUTDATA6: U313.4 (IO6); also elsewhere on the board
/sdr/sdrOutput/OUTDATA7: U313.16 (IO7); also elsewhere on the board
/~PHI2: U340.3 (C); also elsewhere on the board
CNT: U302.6; also elsewhere on the board
GND: U302.5, U302.12, U313.10 (GND), U315.8 (GND); also elsewhere on the board
unnamed: U301.4, U301.5, U309.11
unnamed: U301.8, U313.12 (Cp)
unnamed: U301.9, U301.10, U302.4, U314.8
unnamed: U301.11, U314.12
unnamed: U302.13, U314.11
unnamed: U305.8 (~Q), U305.12 (D), U314.10, U315.5 (UP)
unnamed: U313.8 (Q0), U313.11 (Ds0)
unnamed: U313.17 (Q7), U314.13
unnamed: U313.19 (S1), U340.5 (Q)
SP: U302.11; also elsewhere on the board
SPMODE: U301.12, U301.13, U309.12; also elsewhere on the board
TAPULSE: U305.11 (C); also elsewhere on the board
VCC: U313.1 (S0), U313.2 (OE1), U313.3 (OE2), U313.9 (Mr), U313.18 (Ds7), U313.20 (VCC), U315.1 (B), U315.4 (DOWN), U315.9 (D), U315.10 (C), U315.11 (~LOAD), U315.15 (A), U315.16 (VCC), U340.1 (~R), U340.4 (~S); also elsewhere on the board
~RES: U309.13; also elsewhere on the board


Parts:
U320, U321, U322, U323, U324, U328: 74HC00; SO-14_3.9x8.65mm_P1.27mm
U325, U326: 74HC08; SO-14_3.9x8.65mm_P1.27mm
U327: 74HC377; SOIC-20W_7.5x12.8mm_P1.27mm

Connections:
/icr/icrControl/MASK0: U323.1, U327.19 (Q7); also elsewhere on the board
/icr/icrControl/MASK1: U323.5, U327.15 (Q5); also elsewhere on the board
/icr/icrControl/MASK2: U323.12, U327.2 (Q0); also elsewhere on the board
/icr/icrControl/MASK3: U322.12, U327.6 (Q2); also elsewhere on the board
/icr/icrControl/MASK4: U322.9, U327.12 (Q4); also elsewhere on the board
/icr/icrRegister/MASKINT0: U326.3, U327.18 (D7)
/icr/icrRegister/MASKINT1: U326.8, U327.14 (D5)
/icr/icrRegister/MASKINT2: U326.11, U327.3 (D0)
/icr/icrRegister/MASKINT3: U326.6, U327.7 (D2)
/icr/icrRegister/MASKINT4: U325.8, U327.13 (D4)
/icr/icrRegister/~WE12: U327.1 (~E), U328.11
/~PHI2: U327.11 (CP); also elsewhere on the board
DZ0: U320.1, U320.2, U322.1; also elsewhere on the board
DZ1: U321.9, U321.10, U322.5; also elsewhere on the board
DZ2: U320.12, U321.12, U321.13; also elsewhere on the board
DZ3: U320.5, U321.1, U321.2; also elsewhere on the board
DZ4: U320.10, U321.4, U321.5; also elsewhere on the board
DZ7: U320.4, U320.9, U320.13, U322.2, U322.4; also elsewhere on the board
ENABLE_NAND: U328.13; also elsewhere on the board
GND: U327.4 (D1), U327.8 (D3), U327.10 (GND), U327.17 (D6); also elsewhere on the board
unnamed: U320.3, U323.2
unnamed: U320.6, U324.5
unnamed: U320.8, U323.10
unnamed: U320.11, U324.13
unnamed: U321.3, U322.13
unnamed: U321.6, U322.10
unnamed: U321.8, U323.4
unnamed: U321.11, U323.13
unnamed: U322.3, U324.2
unnamed: U322.6, U324.10
unnamed: U322.8, U323.9
unnamed: U322.11, U324.4
unnamed: U323.3, U324.1
unnamed: U323.6, U324.9
unnamed: U323.8, U325.9
unnamed: U323.11, U324.12
unnamed: U324.3, U326.2
unnamed: U324.6, U326.4
unnamed: U324.8, U326.9
unnamed: U324.11, U326.13
unnamed: U328.3, U328.12
VCC: U327.20 (VCC); also elsewhere on the board
~EN13: U328.1; also elsewhere on the board
~RES: U325.10, U326.1, U326.5, U326.10, U326.12, U328.2; also elsewhere on the board

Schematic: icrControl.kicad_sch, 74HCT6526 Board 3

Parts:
SW301: SW_SPDT; SW_SPDT_PCM12
U329: 74HC00; SO-14_3.9x8.65mm_P1.27mm
U330, U331, U332, U333, U334, U342: 74HC74; SO-14_3.9x8.65mm_P1.27mm
U335: 74HCT04; SO-14_3.9x8.65mm_P1.27mm
U336: 74HC244; SOIC-20W_7.5x12.8mm_P1.27mm
U337, U339: 74HC08; SO-14_3.9x8.65mm_P1.27mm
U338: 74HC32; SO-14_3.9x8.65mm_P1.27mm
U341: 74HC157; SO-16_3.9x9.9mm_P1.27mm

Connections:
/icr/icrControl/ICR0: U331.5 (Q), U336.2 (1A0), U339.12
/icr/icrControl/ICR1: U332.9 (Q), U336.17 (2A0)
/icr/icrControl/ICR2: U332.5 (Q), U336.4 (1A1), U337.4
/icr/icrControl/ICR3: U331.9 (Q), U336.15 (2A1), U337.9
/icr/icrControl/ICR4: U333.9 (Q), U336.13 (2A2), U339.9
/icr/icrControl/ICR7: U336.8 (1A3), U341.7
/icr/icrControl/ICRCLR: U329.6, U330.12 (D)
/icr/icrControl/MASK0: U339.13; also elsewhere on the board
/icr/icrControl/MASK1: U337.13; also elsewhere on the board
/icr/icrControl/MASK2: U337.5; also elsewhere on the board
/icr/icrControl/MASK3: U337.10; also elsewhere on the board
/icr/icrControl/MASK4: U339.10; also elsewhere on the board
/icr/icrControl/~ICRCLR1: U330.8 (~Q), U331.1 (~R), U331.13 (~R), U332.1 (~R), U333.13 (~R), U334.1 (~R), U334.13 (~R), U341.2, U342.1 (~R), U342.13 (~R)
/icr/icrControl/~ICRCLR2: U330.6 (~Q), U341.3
/icr/icrControl/~OE13: U329.5, U329.8, U336.1 (1OE), U336.19 (2OE)
/~PHI2: U330.3 (C), U330.11 (C), U334.11 (C), U342.11 (C); also elsewhere on the board
/~SDRIRQ: U331.10 (~S); also elsewhere on the board
D0: U336.18 (1Y0); also elsewhere on the board
D1: U336.3 (2Y0); also elsewhere on the board
D2: U336.16 (1Y1); also elsewhere on the board
D3: U336.5 (2Y1); also elsewhere on the board
D4: U336.7 (2Y2); also elsewhere on the board
D5: U336.14 (1Y2); also elsewhere on the board
D6: U336.9 (2Y3); also elsewhere on the board
D7: U336.12 (1Y3); also elsewhere on the board
ENABLE_NAND: U329.12, U329.13; also elsewhere on the board
GND: SW301.1 (A), U336.6 (1A2), U336.10 (GND), U336.11 (2A3), U341.15 (~E); also elsewhere on the board
unnamed: SW301.2 (B), U341.1 (S)
unnamed: U329.3, U329.9
unnamed: U329.10, U329.11
unnamed: U330.2 (D), U330.9 (Q)
unnamed: U331.4 (~S), U335.10
unnamed: U332.4 (~S), U335.2
unnamed: U332.10 (~S), U335.12
unnamed: U332.13 (~R), U341.4
unnamed: U333.1 (~R), U333.8 (~Q)
unnamed: U333.3 (C), U335.4
unnamed: U333.6 (~Q), U333.10 (~S)
unnamed: U334.4 (~S), U335.8, U342.4 (~S)
unnamed: U334.9 (Q), U341.6
unnamed: U334.5 (Q), U334.12 (D), U341.5
unnamed: U335.9, U338.6
unnamed: U337.6, U338.12
unnamed: U337.8, U338.13
unnamed: U337.11, U338.2
unnamed: U338.1, U339.11
unnamed: U338.3, U338.9
unnamed: U338.4, U338.8
unnamed: U338.5, U339.8
unnamed: U338.10, U338.11
unnamed: U341.10, U342.8 (~Q)
unnamed: U341.11, U342.6 (~Q)
unnamed: U342.5 (Q), U342.12 (D)
TAPULSE: U335.11; also elsewhere on the board
TBPULSE: U335.13, U337.12; also elsewhere on the board
TODIRQ: U335.1; also elsewhere on the board
VCC: SW301.3 (C), U330.1 (~R), U330.4 (~S), U330.10 (~S), U330.13 (~R), U331.2 (D), U331.3 (C), U331.11 (C), U331.12 (D), U332.2 (D), U332.3 (C), U332.11 (C), U332.12 (D), U333.2 (D), U333.4 (~S), U333.11 (C), U333.12 (D), U334.2 (D), U334.3 (C), U334.10 (~S), U336.20 (VCC), U342.2 (D), U342.3 (C), U342.10 (~S); also elsewhere on the board
~EN13: U329.1, U329.2; also elsewhere on the board
~FLAG: U335.3; also elsewhere on the board
~IRQ: U341.9; also elsewhere on the board
~RES: U329.4; also elsewhere on the board


Board: 4 copper layers, 100.0 x 100.0 mm, 93 parts (0 on the bottom side), 161 nets.

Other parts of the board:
GND101, GND102: GND; MountingHole_2.2mm_M2_DIN965_Pad
VCC101, VCC102: VCC; MountingHole_2.2mm_M2_DIN965_Pad

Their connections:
GND: GND101.GND, GND102.GND; also elsewhere on the board
VCC: VCC101.VCC, VCC102.VCC; also elsewhere on the board

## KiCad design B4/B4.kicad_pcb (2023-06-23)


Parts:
U429: 74HC04; SOIC-14_3.9x8.7mm_P1.27mm

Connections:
/~PHI2: U429.8; also elsewhere on the board
PHI2: U429.9; also elsewhere on the board


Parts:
U405, U411, U416, U423: 74HC688; SOIC-20W_7.5x12.8mm_P1.27mm
U429: 74HC04; SOIC-14_3.9x8.7mm_P1.27mm

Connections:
/todAlarm/ALARM4: U405.5 (R1); also elsewhere on the board
/todAlarm/ALARM5: U405.3 (R0); also elsewhere on the board
/todAlarm/ALARM6: U405.14 (R5); also elsewhere on the board
/todAlarm/ALARM7: U405.12 (R4); also elsewhere on the board
/todAlarm/ALARM8: U411.5 (R1); also elsewhere on the board
/todAlarm/ALARM9: U411.3 (R0); also elsewhere on the board
/todAlarm/ALARM10: U411.14 (R5); also elsewhere on the board
/todAlarm/ALARM11: U411.12 (R4); also elsewhere on the board
/todAlarm/ALARM12: U411.16 (R6); also elsewhere on the board
/todAlarm/ALARM13: U411.7 (R2); also elsewhere on the board
/todAlarm/ALARM14: U411.9 (R3); also elsewhere on the board
/todAlarm/ALARM16: U416.5 (R1); also elsewhere on the board
/todAlarm/ALARM17: U416.3 (R0); also elsewhere on the board
/todAlarm/ALARM18: U416.14 (R5); also elsewhere on the board
/todAlarm/ALARM19: U416.12 (R4); also elsewhere on the board
/todAlarm/ALARM20: U416.16 (R6); also elsewhere on the board
/todAlarm/ALARM21: U416.7 (R2); also elsewhere on the board
/todAlarm/ALARM22: U416.9 (R3); also elsewhere on the board
/todAlarm/ALARM24: U423.5 (R1); also elsewhere on the board
/todAlarm/ALARM25: U423.3 (R0); also elsewhere on the board
/todAlarm/ALARM26: U423.14 (R5); also elsewhere on the board
/todAlarm/ALARM27: U423.12 (R4); also elsewhere on the board
/todAlarm/ALARM28: U423.16 (R6); also elsewhere on the board
/todAlarm/ALARM31: U423.18 (R7); also elsewhere on the board
/todComparator/TODBUS4: U405.4 (P1); also elsewhere on the board
/todComparator/TODBUS5: U405.2 (P0); also elsewhere on the board
/todComparator/TODBUS6: U405.13 (P5); also elsewhere on the board
/todComparator/TODBUS7: U405.11 (P4); also elsewhere on the board
/todComparator/TODBUS8: U411.4 (P1); also elsewhere on the board
/todComparator/TODBUS9: U411.2 (P0); also elsewhere on the board
/todComparator/TODBUS10: U411.13 (P5); also elsewhere on the board
/todComparator/TODBUS11: U411.11 (P4); also elsewhere on the board
/todComparator/TODBUS12: U411.15 (P6); also elsewhere on the board
/todComparator/TODBUS13: U411.6 (P2); also elsewhere on the board
/todComparator/TODBUS14: U411.8 (P3); also elsewhere on the board
/todComparator/TODBUS16: U416.4 (P1); also elsewhere on the board
/todComparator/TODBUS17: U416.2 (P0); also elsewhere on the board
/todComparator/TODBUS18: U416.13 (P5); also elsewhere on the board
/todComparator/TODBUS19: U416.11 (P4); also elsewhere on the board
/todComparator/TODBUS20: U416.15 (P6); also elsewhere on the board
/todComparator/TODBUS21: U416.6 (P2); also elsewhere on the board
/todComparator/TODBUS22: U416.8 (P3); also elsewhere on the board
/todComparator/TODBUS24: U423.4 (P1); also elsewhere on the board
/todComparator/TODBUS25: U423.2 (P0); also elsewhere on the board
/todComparator/TODBUS26: U423.13 (P5); also elsewhere on the board
/todComparator/TODBUS27: U423.11 (P4); also elsewhere on the board
/todComparator/TODBUS28: U423.15 (P6); also elsewhere on the board
/todComparator/TODBUS31: U423.17 (P7); also elsewhere on the board
GND: U405.1 (G), U405.6 (P2), U405.7 (R2), U405.8 (P3), U405.9 (R3), U405.10 (GND), U405.15 (P6), U405.16 (R6), U405.17 (P7), U405.18 (R7), U411.10 (GND), U411.17 (P7), U411.18 (R7), U416.10 (GND), U416.17 (P7), U416.18 (R7), U423.6 (P2), U423.7 (R2), U423.8 (P3), U423.9 (R3), U423.10 (GND); also elsewhere on the board
unnamed: U405.19 (P=R), U411.1 (G)
unnamed: U411.19 (P=R), U416.1 (G)
unnamed: U416.19 (P=R), U423.1 (G)
unnamed: U423.19 (P=R), U429.13
TODIRQ: U429.12; also elsewhere on the board
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

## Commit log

2021-09-12 Fix typo in 74HCT6526.kicad_sch
    [74HCT6526.kicad_sch]
2021-10-02 v0.1
    B0 v0.1 Production release
    B1 N/A
    B2 N/A
    B3 N/A
    B4 N/A
    [B0.kicad_pcb, B0.kicad_sch, icInterface.kicad_sch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]
2021-10-17 Added gerber for v0.1.1
    [B0.kicad_pcb]
2021-10-18 Fixed Soldermask over mount pads
    [B0.kicad_pcb]
2021-10-18 Fixed mounted pads thermal relief
    [B0.kicad_pcb]
2021-10-19 v0.1.0 completed
    [B0.kicad_pcb]
2022-03-20 B1 CREGA added
    Work started on b1. CREGA added.
    Minor changes to B0 schematic properties.
    [74HCT6526.kicad_pcb, 74HCT6526.kicad_sch, B0.kicad_pcb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]
2022-04-27 v0.1.0 B1 uploaded
    Pending review and production. Version release will be published once sent for fab
    [B1.kicad_pcb, B1.kicad_sch, buses.kicad_sch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]
2022-05-10 Fixed CREGA Clock
    Fixed CREGA Clock
    [B1.kicad_pcb, crega.kicad_sch]
2022-06-06 B1 into production!
    [B1.kicad_sch, crega.kicad_sch, power.kicad_sch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]
2022-07-30 Pre B2 Clone
    [B1.kicad_pcb]
2022-08-13 B2 almost ready
    [74HCT6526.kicad_sch, B0.kicad_pcb, B0.kicad_sch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]
2022-08-17 Almost 0.1.1
    [B0.kicad_pcb, B0.kicad_sch, B1.kicad_sch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]
2022-08-24 B2 Ready for prod
    [B1.kicad_pcb, B2.kicad_pcb]
2022-09-02 Gerbers B2 and B1
    [B1-B_Cu.gbr, B1-B_Mask.gbr, B1-B_Paste.gbr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]
2022-09-12 Updates to B3
    [B2-B_Cu.gbr, B2-B_Mask.gbr, B2-B_Paste.gbr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]
2022-09-23 B3 added. First revision
    Still not verified.
    [B3-B_Cu.gbr, B3-B_Mask.gbr, B3-B_Paste.gbr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]
2022-09-24 Added ICR. B2 fixes
    [B2.kicad_pcb, B2.kicad_sch, cregb.kicad_sch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]
2022-11-01 Release v0.1.2. Added SDR!
    [B1-B_Cu.gbr, B1-B_Mask.gbr, B1-B_Paste.gbr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]
2022-11-30 Fixed B3 3d footprints
    [B3.kicad_pcb]
2023-01-23 B0 ready for v0.2.0 release.
    [B0.kicad_pcb, B0.kicad_sch, B1.kicad_pcb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]
2023-01-23 B1 ready for v0.2.0 release
    [B1.kicad_pcb]
2023-01-24 B2 ready for v0.2.0 release
    [B2.kicad_pcb]
2023-01-24 B3 ready for v0.2.0 release
    [B3.kicad_pcb, B3.kicad_sch, power.kicad_sch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]
2023-03-26 Ready for v0.2.1
    [B0.kicad_pcb, B0.kicad_sch, B1.kicad_pcb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]
2023-04-20 B2 refactored. B4 Added. TOD sch completed.
    [B2.kicad_pcb, B2.kicad_sch, B3.kicad_pcb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]
2023-05-02 TOD is here
    [02 - HCTNEW - STAGE1.logicdata-test5.csv, 02 - HCTNEW - STAGE1.logicdata-test7.csv, 02 - HCTOLD - STAGE1.logicdata-test5.csv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]
2023-05-02 Issue #12 diagnosis
    [02 - OLD - TEST5.xlsx, B3.kicad_pcb, B3.kicad_sch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]
2023-05-07 Fixing ICR
    [B3.kicad_sch, icrControl.kicad_sch]
2023-06-23 Ready for v0.2.2
    [All_ICs_Inventory.xlsx, B0.kicad_pcb, B0.kicad_sch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]
